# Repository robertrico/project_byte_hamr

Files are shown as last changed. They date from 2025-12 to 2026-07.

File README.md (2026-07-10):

# Byte Hamr

An open-source FPGA expansion card for the Apple II family of computers.

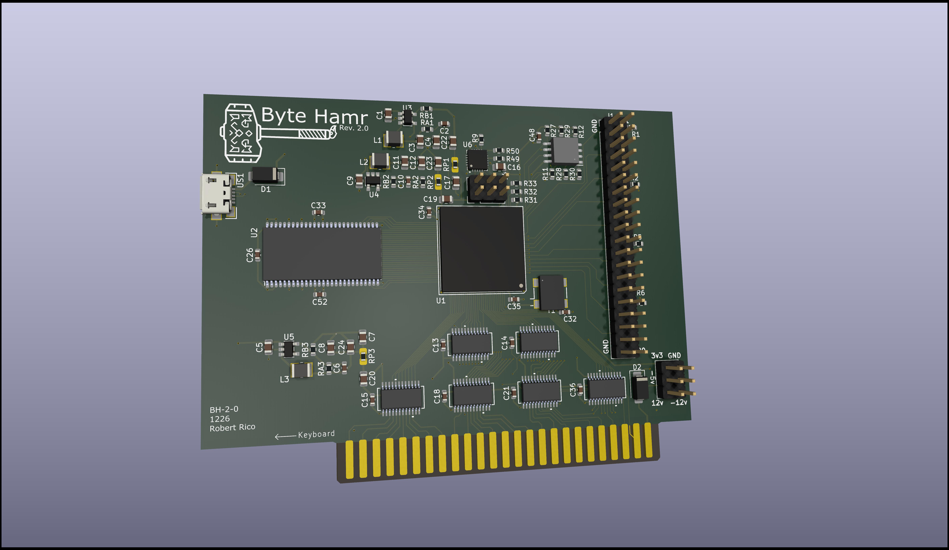
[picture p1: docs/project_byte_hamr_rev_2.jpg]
Byte Hamr


## Overview

Byte Hamr brings modern FPGA capabilities to the Apple II, II+, IIe, and IIgs. Unlike purpose-built cards that serve a single function, Byte Hamr is a general-purpose platform for developing and running custom hardware designs on vintage Apple hardware.

The card sits between the simplicity of the A2FPGA (which targets HDMI output) and the complexity of the Carte Blanche (which is difficult to obtain and uses proprietary tooling). Byte Hamr uses the Lattice ECP5 FPGA with full support for the open-source Yosys/nextpnr toolchain.

## Features

- Lattice ECP5-85F FPGA (84K LUTs, BGA381 package)
- 64MB SDRAM (AS4C32M16SB-7TCNTR)
- 128Mb SPI Flash for bitstream storage
- USB programming via FTDI FT231XQ
- JTAG header for development/debugging
- 20-pin GPIO header with heavy ground interleaving (Rev 2)
- 2×3 power breakout: +3V3, +5V, −5V, +12V, −12V (Rev 2)
- Full Apple II bus interface with bidirectional level shifting
- Dedicated FPGA-controlled data-bus transceiver OE (Rev 2)
- Hardware R/W inverter for correct transceiver direction (Rev 2)
- Bidirectional nRES — drive *and* monitor Apple II reset (Rev 2)
- Dual power input (USB or Apple II bus) with automatic switching
- On-board 100 MHz oscillator (Rev 2; 25 MHz on Rev 1)
- Open-source hardware and gateware

## Specifications

| Parameter | Value |
|---|---|
| FPGA | Lattice ECP5-85F (LFE5U-85F-8BG381I) |
| Logic Elements | 84K LUTs |
| Block RAM | 3744 Kbit |
| SDRAM | 64MB, 16-bit bus |
| Flash | 128Mb SPI |
| USB | Full-speed via FT231XQ |
| GPIO | 20 pins, 3.3V LVCMOS33 |
| Oscillator | 100 MHz (Rev 2) |
| Power | +5V from USB or Apple II slot |
| Dimensions | Standard Apple II card form factor |

## Architecture

```
                                    +------------------+
                                    |     SDRAM        |
                                    |   (64MB x16)     |
                                    +--------+---------+
                                             |
+-------------+     +----------+     +-------+--------+     +----------+
| Apple II    |     | Level    |     |                |     |   SPI    |
| Expansion   +---->+ Shifters +---->+   ECP5-85F     +---->+  Flash   |
| Slot        |     | (5V/3.3V)|     |     FPGA       |     |  (16MB)  |
+-------------+     +----------+     +-------+--------+     +----------+
                                             |
                                     +-------+--------+
                                     |      USB       |
                                     |  (FT231XQ)     |
                                     +----------------+
```

## Power Distribution

Three on-board switching regulators generate the required voltages:

- +3.3V for FPGA I/O, SDRAM, Flash, level shifters
- +2.5V for FPGA auxiliary power
- +1.1V for FPGA core

Power can be sourced from USB (+5V) or the Apple II slot, with Schottky diode OR-ing for automatic switching. Rev 2 moves the 5V input diode ahead of the level-shifter rail so USB alone can power the bus logic.

## Bus Interface

Six 74LVC8T245 bidirectional level shifters translate between the Apple II's 5V bus and the FPGA's 3.3V I/O. The interface provides access to:

- 16-bit address bus
- 8-bit data bus (bidirectional)
- Control signals (R/W, PHI0, device select, etc.)

Rev 2 adds a dedicated 74AHC1G04 inverter (`U7`) that generates the correct-polarity DIR control for the data-bus transceiver, and exposes the transceiver's OE on an FPGA pin so gateware can cleanly gate drive.

## GPIO Header

20-pin header with ground interleaving (pin `1` marked at the top, `20` at the bottom). All pins are 3.3V LVCMOS33.

| GPIO | FPGA Site | | GPIO | FPGA Site |
|---|---|---|---|---|
| GPIO_1  | P3 | | GPIO_11 | J1 |
| GPIO_2  | P1 | | GPIO_12 | H2 |
| GPIO_3  | P2 | | GPIO_13 | H1 |
| GPIO_4  | N1 | | GPIO_14 | G2 |
| GPIO_5  | M1 | | GPIO_15 | G1 |
| GPIO_6  | L2 | | GPIO_16 | F2 |
| GPIO_7  | L1 | | GPIO_17 | F1 |
| GPIO_8  | K3 | | GPIO_18 | E2 |
| GPIO_9  | K1 | | GPIO_19 | E1 |
| GPIO_10 | K2 | | GPIO_20 | D2 |

See [byte_hamr.lpf](gateware/rev2/constraints/byte_hamr.lpf) for full pin constraints.

## Project Status

**Rev 2** — fabricated and bring-up in progress (April 2026). Both boards enumerate over USB and pass initial SDRAM + GPIO tests.

**Rev 1** — sent to fabrication (December 2025). Tagged `rev1` in git; all Rev 1 gateware preserved under `gateware/rev1/`.

See [VERSION.md](VERSION.md) for full version history.

### Rev 2 changes

- Board footprint shrunk
- GPIO expanded from 12 → 20 pins with dense ground interleaving
- Power breakout block exposing ±5V / ±12V / 3V3
- On-board R/W inverter (replaces Rev 1 bodge wire)
- 5V diode moved ahead of level shifters so USB can power the bus side
- Shortened SDRAM routes to the ECP5
- Data-bus transceiver OE promoted from GPIO bodge to dedicated FPGA pin (`DATA_OE`, B20)
- Bidirectional nRES: separate `nRES_READ` input (A5) so gateware can monitor Apple II reset
- Oscillator upgraded 25 MHz → 100 MHz for better CDC oversampling and PLL headroom

## Repository Structure

```
project_byte_hamr/
├── hardware/
│   └── byte_hamr/          # Main FPGA card
│       ├── kicad/          # KiCad schematic and PCB
│       ├── bom/            # Bill of materials
│       └── gerbers/        # Manufacturing files
├── gateware/
│   ├── rev1/               # Rev 1 designs (frozen, matches rev1 git tag)
│   │   ├── constraints/
│   │   ├── signal_check/
│   │   ├── sdram_test/
│   │   ├── sdram_bank/
│   │   ├── pattern_rom/
│   │   ├── logic_hamr/
│   │   ├── smart_hamr/
│   │   ├── block_hamr/
│   │   └── flash_hamr/
│   └── rev2/               # Rev 2 designs (porting in progress)
│       ├── constraints/
│       └── signal_check/
├── software/
│   ├── ASM/                # 6502 assembly source (Merlin32)
│   ├── LOGICHAMR/          # Logic analyzer disk contents
│   └── utils/              # Disk image utilities
└── docs/                   # Documentation
```

## Getting Started

### Prerequisites

**Gateware:**
- [oss-cad-suite](https://github.com/YosysHQ/oss-cad-suite-build) (recommended) or individual tools:
  - [Yosys](https://github.com/YosysHQ/yosys) (synthesis)
  - [nextpnr-ecp5](https://github.com/YosysHQ/nextpnr) (place and route)
  - [openFPGALoader](https://github.com/trabucayre/openFPGALoader) (programming)

**6502 Assembly:**
- [Merlin32](https://brutaldeluxe.fr/products/crossdevtools/merlin/) (cross-assembler)

**Disk Utilities:**
- [AppleCommander](https://applecommander.github.io/) (disk image manipulation)
- [ADTPro](https://adtpro.com/) (disk transfer to real hardware)
- Java runtime

### Building Gateware

Builds are selected by `DESIGN` and `REV`. `REV` defaults to `rev1`; set `REV=rev2` when targeting the current hardware.

```bash
make                                # Build default (REV=rev1, DESIGN=signal_check)
make DESIGN=xxx                     # Build specific design (rev1)
make DESIGN=xxx REV=rev2            # Build against Rev 2 pinout
make sim DESIGN=xxx REV=rev2        # Run simulation
make wave                           # Run simulation and open GTKWave
make help                           # Show all available targets
```

`b8008_hamr` lives under `gateware/rev2/` and always needs `REV=rev2`; it also
needs `fusesoc` installed and a sibling `intel-8008-vhdl` checkout
(`INTEL8008_DIR`, default `~/Development/intel-8008-vhdl`) to generate its
netlist at build time, e.g. `make DESIGN=b8008_hamr REV=rev2 bit`.

### Programming

```bash
make DESIGN=xxx REV=rev2 prog                         # Program via JTAG (volatile)
make DESIGN=xxx REV=rev2 prog-flash                   # Program SPI flash (persistent)
make DESIGN=xxx REV=rev2 prog-flash SERIAL=<FTDI_SN>  # Target a specific board
```

### Software Development Workflow

```
┌─────────────┐     ┌───────────────┐     ┌─────────────┐     ┌───────────┐
│  Merlin32   │────▶│ AppleCommander│────▶│   ADTPro    │────▶│ Apple IIe │
│  (assemble) │     │ (create .dsk) │     │  (transfer) │     │   (run)   │
└─────────────┘     └───────────────┘     └─────────────┘     └───────────┘
```

```bash
# 1. Edit source in software/LOGICHAMR/*.S

# 2. Assemble with Merlin32
make assemble ASM_SRC=software/LOGICHAMR/LOGIC.S

# 3. Create disk image (auto-copied to ADTPro disks folder)
make create-dsk DSK=LOGICHAMR

# 4. Transfer via ADTPro to real hardware

# 5. On Apple II: BRUN LOGIC
```

**Disk utilities:**
```bash
make extract-dsk DSK=file.dsk     # Extract files from disk image
make list-dsk                     # List disks in ADTPro folder
```

### Utility Commands

```bash
make pinout             # Regenerate FPGA pinout from schematics
make lpf                # Regenerate LPF constraints
make clean              # Remove build files
```

## Gateware Designs

Rev 1 versions (proven on Rev 1 hardware):

| Design | Description |
|---|---|
| [signal_check](gateware/rev1/signal_check/SIGNAL_CHECK.md) | Board bring-up test (SDRAM, GPIO, bus monitor) |
| sdram_test | Register-driven SDRAM access from Apple II |
| [sdram_bank](gateware/rev1/sdram_bank/README.md) | SDRAM bank-switching controller |
| [pattern_rom](gateware/rev1/pattern_rom/README.md) | SDRAM-backed pattern ROM for display testing |
| [logic_hamr](gateware/rev1/logic_hamr/README.md) | 8-channel logic analyzer with HIRES display |
| [smart_hamr](gateware/rev1/smart_hamr/README.md) | SmartPort/IWM disk controller with ESP32 companion |
| [block_hamr](gateware/rev1/block_hamr/README.md) | ProDOS block device with SDRAM and SPI flash persistence |
| [flash_hamr](gateware/rev1/flash_hamr/) | SD card ProDOS block device (PicoRV32 + FatFS) |

Rev 2 port: `signal_check` ported and validated; other designs pending.

## Testing

Bringup sequence for new boards:

1. Visual inspection
2. Power rail verification (+5V, +3.3V, +2.5V, +1.1V)
3. USB enumeration (FTDI detection)
4. FPGA configuration with [signal_check](gateware/rev2/signal_check/)
5. Oscillator verification (100 MHz on scope; derived 25 MHz appears on SDRAM_CLK)
6. GPIO walk — watch walking 1s across `GPIO_9`..`GPIO_20`
7. Apple II bus communication (register loopback at $C0C0)
8. Data-bus transceiver + R/W inverter walk: `C0C0:01 → C0C0`, then `02`, `04`, … `80`
9. Full system integration

## Design References

This project builds on the work of others:

- [ULX3S](https://github.com/emard/ulx3s) - ECP5 reference design, power architecture
- [Xander's 8-bit fun](https://xjmaas.wordpress.com/my-apple-collection/apple-edge-connector-template-for-eagle/) - Apple II Edge Card Design
- [Understanding the Apple IIe](https://archive.org/details/understanding_the_apple_iie) - Jim Sather's essential reference

## Why "Byte Hamr"?

"Hamr" is Old Norse for "shape" or "form" — the concept of shapeshifting in Norse mythology. Byte Hamr: shapeshifting bytes. An FPGA that can become any hardware you define. The shape changes based on what you program it to be.

## License

This project is released under the [MIT License](LICENSE.md).

## Author

Robert Rico

## Contributing

This is an early-stage project. Issues, suggestions, and pull requests welcome.

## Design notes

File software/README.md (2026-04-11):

# Software

Apple II and host-side software for the Byte Hamr FPGA expansion card.

## Directories

| Directory | Language | Purpose |
|---|---|---|
| [ASM](ASM/) | 6502 Assembly | Graphics demos, logic analyzer UI prototypes, and FPGA hardware test programs |
| [LOGICHAMR](LOGICHAMR/) | 6502 Assembly | Logic analyzer display program with full FPGA capture engine integration |
| [SMARTPORT](SMARTPORT/) | C + ARM Assembly + PIO | PicoPort: SmartPort disk emulator on Raspberry Pi Pico W with SD card support |
| [utils](utils/) | Bash | Disk image manipulation scripts (extract/create `.dsk` files via AppleCommander) |

## Workflow

1. Write 6502 assembly source (`.S` files)
2. Assemble with **Merlin32** cross-assembler
3. Package into ProDOS `.dsk` images using `utils/create_dsk.sh`
4. Transfer to Apple II via **ADTPro** or embed in FPGA flash

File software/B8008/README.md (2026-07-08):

# B8008 — On-Apple Development Ecosystem for the Intel 8008 Coprocessor

Complete toolchain for writing, assembling, loading, and running Intel
8008 programs **entirely on the Apple //e**, targeting the `b8008_hamr`
coprocessor card (`gateware/rev2/b8008_hamr/`). No Mac in the loop once
the disk is built.

The 8008 core and its instruction encodings come from the upstream
`~/Development/intel-8008-vhdl` repo (consumer relationship — never
modified here). `docs/isa.json` in that repo is the single source of
truth for the ISA: the CPU, the assembler table, and the validation
model are all generated from or checked against it.

## The tools (all ProDOS BIN, `BRUN` from the shipped disk)

| Tool | What it does |
|---|---|
| `A8` | All-in-one 8008 environment: 80-col fullscreen editor + embedded ASM8 core + card loader. The whole edit → assemble → run loop in one program (see below). |
| `ASM8` | Native 8008 assembler. True 8008new syntax (`MOV A,B`, `MVI C,41h`) — no dialect. Reads a ProDOS TXT source, writes a BIN object whose **aux type = ORG**. |
| `B8RUN` | Loader. Reads a BIN object, streams it into 8008 RAM via the monitor's `L` (Intel-hex) command, prints the `G` address. |
| `B8CMP` | Byte-compare two files via MLI; prints `PASS $nnnn BYTES` or the first-diff offset. The acceptance gate tool. |
| `B8TERM` | Glass TTY attached to the 8008 monitor (Ctrl-Q exits, Ctrl-R reboots the 8008). |
| `B8TEST` | Card presence + FIFO self-test. Run first on a fresh flash. |
| `MAC8008.S` | Legacy: 8008 as Merlin macros (`MOV A;B`, `JMP8` renames). Proven, kept as fallback — ASM8 exists to delete this dialect. |

Fixtures: `HELLO8R.ASM` (verbatim upstream ASL source, ASM8's golden
input) and `HELLO8R.REF` (457-byte reference object derived from the
ASL golden hex). `HELLO8.S` is the same program in MAC8008 dialect.

## Build (Mac side)

Requirements: Merlin32 (`~/Development/Merlin32_v1.2`), AppleCommander
jars (paths in the top-level Makefile), python3, and the
`intel-8008-vhdl` repo checked out as a sibling of this project.

```
make asm8tab    # regenerate ASM8TAB.S from isa.json (opcode cross-check)
make asm8       # table + Python model gate + Merlin32 assemble of ASM8.S
make b8cmp      # assemble B8CMP.S
make b8008disk  # everything + bootable B8008.po (tools BIN, sources TXT)
make copy-dsk DSK=software/B8008/B8008.po   # ship to the //e via ADTPro
```

`make asm8` refuses to build if the design gate fails:
`scripts/asm8_check.py` is a Python reference model of the ASM8 spec —
same generated table (imports `build_table()` from
`scripts/gen_asm8_table.py`), same lexer/expression/encoder rules — and
must assemble `HELLO8R.ASM` byte-identical to `HELLO8R.REF` before
Merlin32 runs. The model passed 6/6 upstream sample programs against
their ASL golden hex. Design bugs die on the Mac; only 6502
implementation faithfulness is tested on hardware.

## Workflow on the //e

### A8 (the one-program loop)

`BRUN A8`, then live there:

```
edit -> ^A (assemble in memory; errors jump the cursor to the line)
     -> ^G (stream object into 8008 RAM, drop into the monitor TTY)
     -> inspect (D/H), type G <org>, watch it run
     -> ^Q back to the editor, buffer untouched
```

- Row 0 = key legend, rows 1-22 = 80-col window into the buffer,
  row 23 = status (filename, `*` dirty flag, L=line C=col, `<`/`>`
  horizontal-scroll hints) and all prompts/messages.
- Keys: arrows; `^B`/`^E` top/bottom; `^P`/`^V` page up/down;
  `^S` save, `^L` load, `^N` new; `^D` delete line; `^F` find
  (case-insensitive, wraps, prompt pre-filled with last pattern);
  `^O` goto line; `^A` assemble; `^G` load-to-card + TTY;
  `^Q` quit (confirms if dirty).
- Buffer: 12KB (~400 lines), CR line ends — the buffer IS the TXT
  file format, so load/save are single MLI calls and round-trip
  byte-identical. Lines longer than 79 cols edit via horizontal
  scroll of the current line (upstream ASL sources hit 81 cols).
- `^A` needs a filename (refuses with `NO NAME. ^S FIRST`); a clean
  assemble also writes the BIN object (aux=ORG) to disk, so B8RUN
  and B8CMP interop keeps working. Errors show `LINE n: MSG` on the
  status row and jump the cursor.
- `^G` assembles first if the buffer is dirty or never assembled,
  then streams and lands at the monitor: `LOADED $len AT $org -
  G org WHEN READY`. **No auto-G** — inspect with D/H, type G
  yourself. `^Q` exits the TTY back to the editor.

### Standalone tools (the original loop, still shipped)

1. Write 8008 source in an editor, save as ProDOS TXT (see Merlin
   notes below).
2. `BRUN ASM8` → filename → object written, `OK $nnnn BYTES AT $oooo`.
3. `BRUN B8RUN` → object name → streamed into 8008 RAM.
4. `PR#4` then `G <org>` — run it. (Ctrl-Q exits the terminal;
   objects are run with B8RUN, never `BRUN <8008 bin>`.)

Since the A8 work, ASM8.S is a thin file driver around `ASM8CORE.S`
(the parser/encoder/symbol library both programs embed). The core's
only seams are line source, object sink, and error exit; everything
else moved verbatim. `make asm8` and the Python model gate are
unchanged.

### ASM8 v1 syntax

- All 8008new mnemonics, real names, comma operands. Registers
  `A B C D E H L M`.
- Labels col 0 (trailing `:` optional), `;` comments, case-insensitive.
- Numbers: decimal, ASL `0FFh` (digit-first, trailing h), `$FF`, `'c'`.
- Expressions: flat left-to-right `+ - & | << >>` and parens.
- Directives: `ORG EQU DB DW DS END`; `cpu`/`page` accepted and
  ignored so verbatim upstream ASL sources assemble unmodified.
- Errors print `LINE n: MESSAGE` plus the offending line.
- Limits: symbols 12 chars, lines 127 chars, output 12KB (= full 8008
  RAM), sources any length (streamed in 512-byte chunks).

### Merlin usage notes

Merlin Pro is the **editor only** in this workflow — ASM8 does the
assembling. Save sources as TXT; ASM8 tolerates Merlin's CR line ends
and high-bit characters. Column alignment is free-form (one space
between fields is enough). Notes from the bench:

- Editing 6502 `.S` files here (ASM8.S, B8CMP.S, ASM8TAB.S) in Merlin
  works and is part of QA — they follow the project-wide Merlin style
  guide in `CLAUDE.md` (single-space fields, ASCII, <=40 cols).
- Do NOT load `HELLO8R.ASM` into Merlin: it has 81-col lines (that's
  ASM8 *input*, deliberately wider than Merlin's comfort).
- MAC8008 macro assembly inside Merlin still works as the fallback
  path, dialect warts and all (`MOV A;B`, `JMP8`).

The Merlin-as-editor loop works — it shipped ECHO8 and validated all
of ASM8 — but it is a multi-step round trip (save, quit, BRUN ASM8,
BRUN B8RUN, PR#4, G). That friction is the motivation for the next
project in this line: a single all-in-one fullscreen
editor/assembler/runner for the 8008. ASM8's assembler core was built
to be embeddable for exactly that future.

## Memory map (ASM8 at runtime)

| Range | Use |
|---|-----|
| `$2000-$3FFF` | ASM8 program + buffers (BRUN target) |
| `$4000-$6FFF` | Output buffer (12KB = full 8008 RAM) |
| `$7000-$8BFF` | Symbol table (14 bytes/entry: 12-char name + value) |
| `$8C00` | MLI IOBUF |

## Memory map (A8 at runtime)

| Range | Use |
|---|-----|
| `$2000-$57FF` | A8 code (14KB budget; ~9.2KB used) |
| `$5800-$87FF` | TEXT buffer (12KB, CR lines = TXT format) |
| `$8800-$8FFF` | Symbol table (2KB — 8008 scale is tens of symbols) |
| `$9000-$93FF` | MLI IOBUF |
| `$9400-$94FF` | Aux staging page |
| AUX `$4000-$6FFF` | 8008 object buffer (full 12KB of 8008 RAM) |

BASIC.SYSTEM stays resident (everything <= `$95FF`). Aux access is
via A8's own RAMRD/RAMWR copy loops — AUXMOVE is banned (it uses
ProDOS-adjacent ZP `$3C-$43`). Aux *reads* execute from a 20-byte
stub at `$0130`: the stack page stays main RAM under RAMRD, code at
`$2000` does not. Self-mod operands are only written with RAMWR off,
and MLI/COUT are never called with a bank flipped.

No zero page is touched anywhere (self-modifying absolute pointers) —
ProDOS ZP is a minefield; see `CLAUDE.md` and the SDM lessons.

## Validation status

ASM8 v1 SHIPPED 2026-07-08. All bench gates passed on real hardware
the day it was built: B8CMP plumbing, the golden gate (HELLO8R.ASM
assembled on the //e byte-identical to HELLO8R.REF, then run via
B8RUN + `G 2040`), the error paths, and a from-scratch program
(COUNT8) written in Merlin, assembled with ASM8, and run — the
founding "write 8008 code on the Apple" goal, in true 8008 syntax.

A8 v1 SHIPPED 2026-07-08 — all bench gates passed on real hardware
the same day it was built: the golden gate (`^A` of the verbatim
HELLO8R.ASM inside A8, B8CMP vs HELLO8R.REF = `PASS $01C9 BYTES`),
the `^G` stream + monitor D-dump + TTY + `^Q` round trip, error
cursor-jump (`LINE n:` message and the cursor lands on the line),
and the ship criterion: a from-scratch 8008 program written,
assembled, loaded, and run without ever leaving A8. Four bench
bugs were found and fixed the same day (key-dispatch clobber,
hi-bit TXT line ends, X-clobber digit truncation, save-prompt
editing) — see git log.

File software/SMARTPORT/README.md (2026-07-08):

# PicoPort (SmartPort Disk Emulator)

SmartPort disk emulator running on a Raspberry Pi Pico W. Receives SmartPort commands from the Apple II via the Byte Hamr FPGA, decodes FM-encoded packets, and serves ProDOS block storage from disk images on an SD card.

## What It Does

1. **Receives** SmartPort commands from Apple II via FM-encoded serial protocol
2. **Decodes** packets using oversampled PIO sampling and edge detection
3. **Processes** commands: STATUS, READBLOCK, WRITEBLOCK, FORMAT, CONTROL, INIT
4. **Reads** disk images from SD card (`.2mg` / `.po` format, block-based)
5. **Encodes** responses as SmartPort packets with proper framing and checksums
6. **Transmits** FM-encoded data back to Apple II via PIO output
7. **Manages** handshaking with ACK (open-drain), REQ, and phase signals

## Key Files

| File | Purpose |
|---|---|
| `main.c` | Entry point: GPIO init, PIO state machines, SmartPort bus loop |
| `picoport.h` | Pin definitions mapping Pico W GPIO to FPGA/SmartPort signals |
| `sp_proto.h` | Protocol definitions (commands, packet types, buffer sizes) |
| `sp_cmd.c` | Bus state machine, packet routing, command handlers |
| `sp_asm.S` | Timing-critical ARM assembly (ACK, phase reads, REQ waits) |
| `sp_encode.c` | Packet encoding (bit 7 masking, checksums, group-of-7) |
| `sp_decode_pkt.c` | Packet decoding (extract commands from received packets) |
| `sp_data.c` | Static data (DIB blocks, status responses, sync bytes) |
| `sd_block.c/h` | SD card interface: reads `.2mg` disk images, serves blocks |
| `fm_decode.S` | ARM Thumb-2 assembly: decodes FM samples from PIO into bytes |
| `fm_rx.pio` | PIO state machine for receiving FM-encoded data |
| `fm_tx.pio` | PIO state machine for transmitting FM-encoded data |
| `hw_config.c` | SPI clock and pin setup for SD card |

## SmartPort Wire Protocol

- **FM encoding**: 4us bit cells; transition = 1-bit, steady = 0-bit
- **Sync**: `$FF $3F $CF $F3 $FC $FF $C3` (PBEGIN)
- **Packet**: SYNC + PBEGIN + DEST + SRC + TYPE + AUX + STAT + ODDCNT + GRP7CNT + data + CHKSUM + PEND
- **Group-of-7 encoding**: Preserves bit 7 by packing MSBs into a header byte
- **Bus phases**: 4 pins (PH0-PH3) indicate command/idle/reset state
- **Block size**: 512 bytes

## Pin Mapping

| Pico GPIO | Signal | Direction |
|---|---|---|
| GP11 | SP_WRDATA | Output (to Apple II) |
| GP21 | SP_RDDATA | Input (from Apple II) |
| GP9 | SP_ACK | Output (open-drain) |
| GP2-5 | SP_PHx | Input (phase bits) |

## Build

Requires Raspberry Pi Pico SDK, ARM GCC cross-compiler, and CMake 3.13+.

```bash
make                        # Build with default images/ProDOS_2_4_1.po
make DISK=images/Merlin.po  # Build with different disk image
make flash                  # Flash via OpenOCD/SWD
make monitor                # Serial output at 115200 baud
make test                   # Build test firmware
make clean                  # Remove build directory
```

## Disk Utilities

```bash
python3 dsk2po.py game.dsk game.po         # Convert DOS 3.3 to ProDOS
python3 create_prodos_vol.py out.po 500000  # Create empty ProDOS volume
```

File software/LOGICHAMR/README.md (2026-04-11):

# Logic Hamr (Apple II Software)

Apple II logic analyzer display program for the Logic Hamr FPGA design. Renders captured digital waveforms on the HI-RES screen with trigger control and zoom.

## Programs

| File | Purpose |
|---|---|
| `LOGIC.S` | Main logic analyzer: captures, triggers, and renders 8-channel waveforms |
| `CAPTEST.S` | Capture engine test: validates trigger and capture flow without display |

## How It Works

Communicates with the Logic Hamr FPGA via `$C0C0`-`$C0C9`:

| Register | Purpose |
|---|---|
| `$C0C0` | Channel select (0-7) |
| `$C0C1` | Sample address |
| `$C0C2` | Data read port |
| `$C0C3` | Command register |
| `$C0C4` | Status register |
| `$C0C5` | Stretch/zoom factor |
| `$C0C6`-`$C0C9` | Trigger configuration |

The program arms the FPGA capture engine, waits for a trigger event, then reads back decimated sample data and renders each channel as a waveform trace on the Apple II HI-RES screen. Supports programmable trigger modes (rising/falling edge) and multiple window presets.

## Build

```bash
merlin32 LOGIC.S      # Produces LOGIC executable at $8000
merlin32 CAPTEST.S    # Produces CAPTEST executable at $8000
```

## Shared Includes

- `INCLUDE.S` -- Apple II memory constants and HI-RES utilities
- `LINEADDR.S` -- HI-RES line address lookup tables

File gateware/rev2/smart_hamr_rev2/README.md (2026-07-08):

# smart_hamr_rev2

ASIC-faithful Apple Liron card recreation on Byte Hamr Rev 2.

Stock FujiNet, stock ProDOS, stock Apple II. Card presents as Slot 4 SmartPort
controller; bridges Apple II IWM register space to FujiNet ESP32 over GPIO
header.

## Spec references

- Apple Integrated Woz Machine Specification, Revision 19 (Jan 2 1985)
- US Patent 4,326,256 (Wozniak, IWM bit-cell decoder)
- Apple SmartPort Bus Specification
- Liron schematic 670-9107 / 820-0117

## Build

```
make clean
make DESIGN=smart_hamr_rev2 REV=rev2
```

## Flash (only on user authorization)

```
make DESIGN=smart_hamr_rev2 REV=rev2 prog-flash
```

## Phase status

| Phase | Scope | Status |
|---|---|---|
| 0 | scaffolding (top, ROM, idle iwm) | bench PASS (2026-05-03) |
| 1 | state regs + mode reg + data_out mux + /ENBL timer | bench PASS (2026-05-03) |
| 2 | write path (TX serializer) | bench PASS (2026-05-03) |
| 3 | read path (RX shifter + x7 + buffer) | bench PASS (2026-05-03) |
| 4 | full ProDOS session | bench PASS (2026-05-03) — full 10-device enum + ProDOS boot |
| 5 | second drive + WRITE/FORMAT | not started |

v1 spec-pure (no drain, no Q6-flush, no DRAIN_DELAY) reaches the
PR#4 functional milestone of the prior `smart_hamr`. Empirical
hacks from PR#4 era are NOT required for Liron protocol fidelity.

`data_chksum=1` errors observed during early bring-up traced to
FujiNet ESP32 debug-print flooding stalling its ISR — not a
gateware fault. Reduce ESP32 print rate when troubleshooting
similar errors.

See `docs/bringup_log.md` for bench results.

## Files

| File | Purpose |
|---|---|
| `smart_hamr_rev2_top.v` | Slot interface, GPIO map, tri-state, POR, reset |
| `iwm_asic.v` | IWM ASIC emulation (single FCLK domain) |
| `addr_decoder.v` | nI_O_SELECT / nI_O_STROBE expansion ROM mgmt (verbatim) |
| `boot_rom.v` | 4 KB ROM container, combinatorial read (verbatim) |
| `liron_rom.mem` | Liron firmware data (verbatim) |
| `smart_hamr_rev2.lpf` | FPGA pin constraints (Rev 2) |

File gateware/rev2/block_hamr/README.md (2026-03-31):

# Block Hamr

ProDOS block storage device for the Apple II, implemented on the Byte Hamr FPGA card. Stores a disk image in SDRAM backed by SPI flash persistence, allowing the Apple II to boot and run from a virtual hard drive.

## What It Does

Block Hamr acts as a ProDOS-compatible block device (similar to a SmartPort drive):

1. **Boot** - On power-up, copies a disk image from SPI flash (at offset `0x400000`) into SDRAM
2. **Auto-detect** - Reads the ProDOS volume header to determine total block count
3. **Block I/O** - The 6502 reads and writes 512-byte blocks through a register interface at `$C0C0-$C0CF`
4. **Write-through persistence** - Modified blocks are asynchronously flushed back to SPI flash

Max disk image size: 12 MB (24,576 blocks of 512 bytes), limited by flash space after the bitstream.

## Register Map

Base address: `$C0C0` (slot 4)

| Offset | Name | R/W | Description |
|---|---|-----|---|
| `$00` | STATUS / CMD | R/W | Read: `{ready, error, 5'b0, boot_done}` / Write: `$01` = READ, `$02` = WRITE |
| `$01` | DATA_READ | R | Read block data (auto-increment) |
| `$02` | BLOCK_LO | R/W | Block number low byte |
| `$03` | BLOCK_HI | R/W | Block number high byte |
| `$04` | SOFT_RESET | W | Pulse to reset state machine |
| `$05` | DATA_WRITE | W | Write block data (auto-increment) |
| `$06` | BLKCNT_LO | R | Total block count low (from boot loader) |
| `$07` | BLKCNT_HI | R | Total block count high |

## Architecture

```
Apple II Bus (7 MHz)           FPGA System (25 MHz)

  boot_rom.v                   boot_loader.v
  (Slot $Cn ROM)               Flash -> SDRAM copy
       |                       Auto-detect blocks
  bus_interface.v                    |
  (Register file)              sdram_arbiter.v
       |                       (Mux boot + block requests)
  block_buffer.v                     |
  (512B dual-port BRAM)        sdram_controller.v
       |                       (64MB SDRAM interface)
       +------ CDC sync ------+
                               flash_persist.v
                               (Write-through to flash)
```

**Clock domains**: 7.16 MHz (Apple II bus) and 25 MHz (SDRAM/flash), with 2-FF synchronizers at boundaries.

**Key design decisions**:
- Driver fits entirely in `$Cn` (256 bytes) - no shared `$C800` ROM needed
- Separate DATA_READ/DATA_WRITE addresses to avoid 6502 STA dummy-read bug
- Prefetch pipeline hides BRAM read latency

## Boot Sequence

1. SDRAM initializes (~200us)
2. Boot loader reads disk image from flash at `0x400000`
3. ProDOS volume header parsed for block count (bytes 1065-1066)
4. Image copied to SDRAM address 0
5. `boot_done` asserted, SPI mux switches from reader to writer
6. Apple II boots from block 0

## Makefile Commands

All commands run from the project root (`project_byte_hamr/`).

```bash
# Build
make DESIGN=block_hamr         # Build complete bitstream
make DESIGN=block_hamr synth   # Synthesis only
make DESIGN=block_hamr pnr     # Place & route only
make DESIGN=block_hamr bit     # Generate bitstream

# Program
make DESIGN=block_hamr prog              # JTAG (volatile)
make DESIGN=block_hamr prog-flash        # SPI flash (persistent)
make DESIGN=block_hamr prog-flash-with-image  # Bitstream + disk image

# Disk image management
make DESIGN=block_hamr prog-flash-with-image DISK_IMAGE=path/to/image.po

# Swap disk images without re-flashing the bitstream
make read-flash                          # Dump current image to disk_dump.po
make read-flash DUMP_FILE=backup.po      # Dump to a specific file
make read-flash DUMP_SIZE=4194304        # Read only 4MB (default: 12MB)
make write-flash DISK_IMAGE=new_disk.po  # Write new image to flash at 0x400000
make write-flash DISK_IMAGE=new_disk.po FLASH_IMG_OFFSET=0x400000

# Simulate
make DESIGN=block_hamr sim         # Run testbench
make DESIGN=block_hamr wave        # Simulation + GTKWave
make DESIGN=block_hamr unit MODULE=bus_interface

# Reports
make DESIGN=block_hamr report      # View build summary
make clean                         # Remove build artifacts
```

## Files

| File | Description |
|---|---|
| `block_hamr_top.v` | Top-level - SPI mux, reset, clock domains |
| `boot_rom.v` | 4KB slot ROM (256B boot + shared expansion) |
| `bus_interface.v` | Register file, command/status, prefetch pipeline |
| `block_buffer.v` | 512-byte dual-port BRAM (7 MHz / 25 MHz) |
| `boot_loader.v` | Flash-to-SDRAM copy with ProDOS auto-detect |
| `sdram_controller.v` | SDRAM init, refresh, read/write |
| `sdram_arbiter.v` | Mux boot loader and block I/O requests |
| `flash_reader.v` | SPI flash reader (boot phase) |
| `flash_writer.v` | SPI flash programmer (runtime phase) |
| `flash_persist.v` | Sector erase/program controller |
| `write_through.v` | Gates block_ready during flash writes |
| `addr_decoder.v` | Apple II address space decoder |
| `hamr_rom.asm` | 6502 ProDOS driver source (Merlin32) |
| `hamr_rom.mem` | Generated ROM content (hex) |
| `block_hamr.lpf` | Pin constraints (design-specific) |

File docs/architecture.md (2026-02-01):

# Byte Hamr Architecture

## System Overview

```
┌─────────────────────────────────────────────────────────────────────────────┐
│                              APPLE II SLOT                                  │
│  ┌─────────────────────────────────────────────────────────────────────┐    │
│  │  Address Bus (A0-A15)  Data Bus (D0-D7)  Control (PHI0/1, R/W, etc) │    │
│  └──────────────────────────────┬──────────────────────────────────────┘    │
└─────────────────────────────────┼───────────────────────────────────────────┘
                                  │
                                  │ 5V ↔ 3.3V
                    ┌─────────────┴─────────────┐
                    │       LEVEL SHIFTERS      │
                    │        (SN74LVC245)       │
                    └─────────────┬─────────────┘
                                  │ 3.3V
┌─────────────────────────────────┼────────────────────────────────────────────┐
│                          BYTE HAMR PCB                                       │
│  ┌──────────────────────────────┴───────────────────────────────────────┐    │
│  │                                                                      │    │
│  │                      ┌─────────────────────┐                         │    │
│  │   Apple II Bus ──────│                     │────── SDRAM (64MB)      │    │
│  │   A0-A15, D0-D7      │                     │       AS4C32M16SB       │    │
│  │   PHI0, PHI1         │    LATTICE ECP5     │                         │    │
│  │   R/W, RDY           │    LFE5U-85F-8      │────── SPI Flash         │    │
│  │   IRQ, NMI, RES      │                     │       (Bitstream)       │    │
│  │   DMA, INH           │    381-ball BGA     │                         │    │
│  │   I/O SELECT         │    85K LUTs         │────── GPIO Header (J1)  │    │
│  │   I/O STROBE         │                     │       12 pins direct    │    │
│  │   DEVICE SELECT      │                     │                         │    │
│  │   7M, Q3, SYNC       └─────────────────────┘────── JTAG (FT2232H)    │    │
│  │                              │                                       │    │
│  │                         CLK_25MHz                                    │    │
│  │                        (Oscillator)                                  │    │
│  └──────────────────────────────────────────────────────────────────────┘    │
└──────────────────────────────────────────────────────────────────────────────┘
```

## Signal Categories

### Apple II Bus Interface (active low signals marked with n)

| Category | Signals | Direction | Description |
|---|---|---|---|
| Address | A0-A15 | Input | 16-bit address from 6502 |
| Data | D0-D7 | Bidirectional | 8-bit data bus |
| Timing | PHI0, PHI1 | Input | System clocks (~1MHz) |
| Timing | 7M, Q3 | Input | High-speed timing (7.16MHz, 1.79MHz) |
| Timing | SYNC | Input | Opcode fetch indicator |
| Control | R/nW | Input | Read/Write direction |
| Control | RDY | Input | Ready (active high) |
| Interrupt | nIRQ, nNMI | Output (active low) | Interrupt requests |
| Reset | nRES | Input | System reset |
| DMA | nDMA, DMA_IN, DMA_OUT | Mixed | DMA control |
| Select | nDEVICE_SELECT | Input | Slot device select ($C0n0-$C0nF) |
| Select | nI/O_SELECT | Input | Slot I/O select ($Cn00-$CnFF) |
| Select | nI/O_STROBE | Input | Expansion ROM ($C800-$CFFF) |
| Control | nINH | Output | Inhibit main ROM |
| Misc | INT_IN, INT_OUT | Mixed | Interrupt daisy chain |

### SDRAM Interface

| Signal | Width | Description |
|---|---|---|
| SDRAM_CLK | 1 | Clock (directly from FPGA, 25MHz) |
| SDRAM_CKE | 1 | Clock enable |
| SDRAM_nCS | 1 | Chip select |
| SDRAM_nRAS | 1 | Row address strobe |
| SDRAM_nCAS | 1 | Column address strobe |
| SDRAM_nWE | 1 | Write enable |
| SDRAM_BA | 2 | Bank address |
| SDRAM_A | 13 | Address (row/column multiplexed) |
| SDRAM_D | 16 | Data (bidirectional) |
| SDRAM_DQM | 2 | Data mask (byte lanes) |

**SDRAM: AS4C32M16SB-7TCNTR**
- 512Mbit (32M x 16bit = 64MB)
- 143MHz max, running at 25MHz (plenty of margin)
- CAS Latency 2 at this speed

### GPIO Header (J1)

12 pins directly connected to FPGA (no level shifters):
- GPIO1-GPIO12: General purpose I/O
- 3.3V logic levels
- Direct FPGA connection for maximum flexibility

## Clock Domains

```
                    ┌──────────────┐
   25MHz OSC ───────│  CLK_25MHz   │──────┬────── FPGA Logic
                    └──────────────┘      │
                                          └────── SDRAM_CLK

   ~1MHz (Apple) ───│    PHI0      │──────────── Sampled by FPGA
                    │    PHI1      │             (oversampled at 25MHz)

   7.16MHz ─────────│    7M        │──────────── Available for timing
   1.79MHz ─────────│    Q3        │
```

**Key Insight**: PHI0/PHI1 are NOT used as FPGA clocks. They are sampled as inputs using the 25MHz system clock. This avoids clock domain crossing issues and provides 25 samples per Apple II bus cycle.

## Memory Map (Apple II Perspective)

| Address Range | Signal Asserted | Typical Use |
|---|---|---|
| $C0n0-$C0nF | nDEVICE_SELECT | Slot n I/O registers (soft switches) |
| $Cn00-$CnFF | nI/O_SELECT | Slot n ROM space (directly addressable) |
| $C800-$CFFF | nI/O_STROBE | Expansion ROM (shared, banked by slot access) |

Where n = slot number (1-7, typically 4-7 for peripheral cards)

## Build Flow

```
┌─────────────┐     ┌─────────────┐     ┌─────────────┐     ┌─────────────┐
│   Verilog   │────▶│   Yosys     │────▶│  nextpnr    │────▶│  ecppack    │
│   Sources   │     │  (synth)    │     │   (PnR)     │     │ (bitstream) │
└─────────────┘     └──────┬──────┘     └──────┬──────┘     └──────┬──────┘
                           │                   │                   │
                           ▼                   ▼                   ▼
                      .json             .config               .bit/.svf
                                           │
┌─────────────┐                            │
│    LPF      │────────────────────────────┘
│ Constraints │    (pin locations, I/O settings)
└─────────────┘
```

## File Structure

```
project_byte_hamr/
├── gateware/                    # FPGA designs
│   ├── signal_check/            # Board bring-up test
│   │   ├── signal_check_top.v   # Top module
│   │   └── signal_check_tb.v    # Testbench
│   └── <future_projects>/
├── hardware/
│   └── byte_hamr/
│       ├── kicad/               # Schematic & PCB
│       └── constraints/
│           └── byte_hamr.lpf    # Pin constraints (generated)
├── scripts/
│   ├── extract_fpga_pinout.py   # Parse KiCad netlist
│   ├── augment_fpga_pinout.py   # Add ECP5 pin info
│   └── generate_lpf.py          # Generate LPF from JSON
├── docs/
│   ├── fpga_pinout.json         # Master pinout (generated)
│   └── architecture.md          # This file
├── build/                       # Build outputs (gitignored)
└── Makefile                     # Build system
```

## Design Conventions

### Signal Naming
- Active-low signals: prefix with `n` (e.g., `nRES`, `nIRQ`)
- Apple II signals: match slot documentation where possible
- SDRAM signals: prefix with `SDRAM_`
- GPIO header: `GPIO1` through `GPIO12`
- Signals starting with numbers: prefix with `sig_` (e.g., `sig_7M`)

### I/O Standards
- All I/O: LVCMOS33 (3.3V)
- SDRAM: FAST slewrate for signal integrity
- Apple II bus: SLOW slewrate (through level shifters)
- Default drive: 8mA

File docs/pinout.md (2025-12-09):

# Apple IIe Peripheral Slot Pinout

This document describes the 50-pin peripheral slot connector used in the Apple IIe. Each expansion slot provides address decoding, data bus access, power, and control signals for peripheral cards.

---

## Pin Reference

| Pin | Signal | Direction | Description |
|-----|---|---|---|
| 1 | I/O SELECT´ | To FPGA | Active low when the MMU references page `$Cn`, where *n* is the slot number. Active during Ø0. |
| 2–17 | A0–A15 | To FPGA | Three-state buffered address bus. Valid during Ø1 through Ø0. |
| 18 | R/W´ | To FPGA | Three-state buffered Read/Write signal. Valid with address bus; high = read, low = write. |
| 19 | SYNC | To FPGA | **Slot 7 only.** Connected to the video timing generator's composite sync signal. |
| 20 | I/O STROBE´ | To FPGA | Active low during Ø0 when address is `$C800`–`$CFFF`. |
| 21 | RDY | To Apple IIe | 6502 RDY input. Pulling low during Ø1 halts the processor with the current address held on the bus. |
| 22 | DMA´ | To Apple IIe | Pulling low disables the 6502 address bus and halts the processor. Held high by 3kΩ resistor to +5V. |
| 23 | INT OUT | To FPGA | Daisy-chain input from higher-priority slot. Active = no higher slot is using interrupts. |
| 24 | DMA OUT | To FPGA | Daisy-chain input from higher-priority slot. Active = no higher slot is using DMA. |
| 25 | +5V | — | +5 volt power supply. 500mA available across *all* peripheral cards. |
| 26 | GND | — | System ground. |
| 27 | DMA IN | To Apple IIe | Daisy-chain output to lower-priority slot. Directly connect to DMA OUT (pin 24), or disable when asserting DMA´. |
| 28 | INT IN | To Apple IIe | Daisy-chain output to lower-priority slot. Directly connect to INT OUT (pin 23), or disable when asserting IRQ´/NMI´. |
| 29 | NMI´ | To Apple IIe | Non-Maskable Interrupt. Pulling low initiates an interrupt cycle; jumps to vector at `$03FB`. This line has a 3.3kΩ pullup to +5v.|
| 30 | IRQ´ | To Apple IIe | Interrupt Request. Pulling low initiates an interrupt cycle if the 6502's I flag is clear. Vector at `$03FE`–`$03FF`. This line has a 3.3kΩ pullup to +5v. |
| 31 | RES´ | To Apple IIe | Reset. Pulling low initiates a processor reset cycle. |
| 32 | INH´ | To Apple IIe | Inhibit. Pulling low disables all onboard ROMs. This line has a 2kΩ pullup to +5v.|
| 33 | −12V | — | −12 volt power supply. 200mA maximum across all peripheral cards. |
| 34 | −5V | — | −5 volt power supply. 200mA maximum across all peripheral cards. |
| 35 | COLOR REF / 3.58M | To FPGA | **Slot 7 only.** 3.58 MHz color reference signal from the video generator. |
| 36 | 7M | To FPGA | 7 MHz clock. |
| 37 | Q3 | To FPGA | 2 MHz asymmetrical clock. |
| 38 | Ø1 | To FPGA | Microprocessor phase-one clock. |
| 39 | µPSYNC | To FPGA | The 6502 drives this line high during the first read cycle of each instruction (opcode fetch). |
| 40 | Ø0 | To FPGA | Microprocessor phase-zero clock. |
| 41 | DEVICE SELECT´ | To FPGA | Active low when address is `$C0n0`–`$C0nX`, where *n* = slot number + 8 and X is between 1 & F. |
| 42–49 | D0–D7 | Both | Three state buffered bidirectional data bus. Write data valid 300ns into Ø0; read data must be stable 100ns before end of Ø0. |
| 50 | +12V | — | +12 volt power supply. 250mA maximum across all peripheral cards. |

---

## Regarding DMA´ and INT, IRQ´, NMI´

The DMA and interrupt signals use a hardware daisy-chain for priority arbitration. Priority is determined by slot position — higher slot numbers have higher priority:

```
Slot 7 (highest) → 6 → 5 → 4 → 3 → 2 → 1 (lowest)
```

**To use interrupts (IRQ´ or NMI´):**
1. Check INT OUT (pin 23) — if active, no higher-priority slot is interrupting
2. Assert IRQ´ or NMI´ to request the interrupt
3. Disable INT IN (pin 28) — this blocks lower-priority slots until you release

**To use DMA:**
1. Check DMA OUT (pin 24) — if active, no higher-priority slot is using DMA
2. Assert DMA´ (pin 22) to take control of the bus
3. Disable DMA IN (pin 27) — this blocks lower-priority slots until you release

For the daisy-chain to function, all slots between yours and slot 7 must either have cards that pass INT OUT → INT IN and DMA OUT → DMA IN, or be empty (with the signals connected on the backplane). [1]

---

## Regarding µPSYNC

The µPSYNC signal enables peripheral cards to detect specific 6502 instructions in hardware. When µPSYNC is high, the data bus contains an opcode being fetched. By sampling the data bus when Ø0 falls, a card can identify which instruction is executing.

For example, detecting an RTI instruction: watch for µPSYNC high with `$40` on the data bus at the falling edge of Ø0. This allows peripheral cards to respond directly to program instructions without software intervention. [2]

---

## Notes

- Active-low signals are indicated with a prime suffix (´), matching Apple's convention. In KiCad, use `~{SIGNAL}` for the equivalent overline notation.
- Slot 7 has unique signals (SYNC, COLOR REF) for video applications.
- The daisy-chain connections (INT IN/OUT, DMA IN/OUT) enable priority-based arbitration across slots.

---

## References

- [1] _Reference Manual for the Apple IIe_ by Apple
- [2] _Understanding the Apple IIe_ by Jim Sather

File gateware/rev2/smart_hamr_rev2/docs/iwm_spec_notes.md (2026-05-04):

# iwm_asic.v — spec → RTL signal mapping

Cross-reference for every IWM signal in `iwm_asic.v`. Citation form
`spec pN` = IWM Specification Rev 19 (Jan 2 1985); `patent col N` = US
Patent 4,326,256 (Wozniak).

## Bus interface

| RTL signal | Source | Spec ref | Notes |
|---|---|---|---|
| `addr[3:0]` | A0..A3 of slot bus | spec p7 | A3..A1 selects state bit, A0 is value |
| `nDEVICE_SELECT` | slot decode | spec p7 | active-low, drives state-reg latches |
| `fclk` | sig_7M | spec p2 | 7.16 MHz Apple II 7M |
| `Q3` | Apple II Q3 | spec p7 | 2 MHz strobe, OR'd with /DEV for bus access |
| `R_nW` | 6502 R/W | spec p7 | gates buffer / mode writes |
| `nRES` | combined POR + Apple reset | — | async clear |
| `data_in/data_out` | D0..D7 mux | spec p9 | tri-stated externally by top |

## State registers (/DEV-clocked)

Per spec p7 + patent Fig. 2 block 39. addr[3:1] decode:

| addr[3:1] | Register | addr[0]=0 | addr[0]=1 |
|---|---|---|---|
| 000 | `phase_r[0]` | clear | set |
| 001 | `phase_r[1]` | clear | set |
| 010 | `phase_r[2]` | clear | set |
| 011 | `phase_r[3]` | clear | set |
| 100 | `motorOn` | clear | set |
| 101 | `driveSel` | clear | set |
| 110 | `q6` | clear | set |
| 111 | `q7` | clear | set |

Latched on `negedge nDEVICE_SELECT`. Async clear on `~nRES`. No FCLK
synchronizer downstream — real ASIC has none, state changes are bus-
cycle-aligned and slower than any FCLK consumer's reaction window.

`rnw_dev` and `a0_dev` also latched on /DEV falling, used by mode/buffer
write event.

## Bus access strobe

Per spec p7. `dev_or_q3 = nDEVICE_SELECT | Q3`. `bus_strobe_rise` =
posedge of `dev_or_q3` in fclk domain. Used to commit data_held into
`modeReg` when q7=1, q6=1, a0_dev=1, rnw_dev=0, motorOn=0.

`data_held` continuously samples `data_in` while `~nDEVICE_SELECT`,
so the latched value is the last byte the 6502 drove during PHI0 high.

## Mode register (spec p8)

| Bit | Name | Function |
|-----|---|---|
| 0 | modeLatch | 1 = latch (SmartPort) framing |
| 1 | modeAsync | 1 = async handshake |
| 2 | modeTimerOff | 1 = disable 1-second motor timer |
| 3 | modeFast | 1 = 2 µs bit cells |
| 4 | mode8MHz | 1 = 8 MHz fclk (unused on Apple II) |
| 5 | modeTest | 1 = test mode |
| 6 | modeMZreset | 1 = MZ reset |
| 7 | (unused) | — |

Reset value: `8'h07` (latch=1, async=1, timer-off=1) — Liron ROM init
expects this.

## Bit-cell timing constants (spec p4 / p10)

Not yet instantiated (Phase 2/3). Reference values for FCLK cycle counts:

| Mode | oneThreshold | zeroThreshold | writeBitCell |
|---|---|---|---|
| slow / 7 MHz | 14 | 42 | 28 |
| slow / 8 MHz | 16 | 48 | 32 |
| fast / 7 MHz | 7 | 21 | 14 |
| fast / 8 MHz | 8 | 24 | 16 |

## /ENBL gating (spec p7 / p12)

`_enbl1 = ~((motorOn & ~driveSel) | (timerActive & ~timerDriveSel))`
`_enbl2 = ~((motorOn &  driveSel) | (timerActive &  timerDriveSel))`

`timerActive` set on `motorOn` falling when `~modeTimerOff`. Holds
2^23 + 100 FCLK = 8388708 cycles (~1.17 s @ 7.16 MHz).

`timerDriveSel` snapshots `driveSel` at timer start so the correct
/ENBL is held even if `driveSel` toggles during the wind-down.

## Read register mux (spec p7 / p9)

| q7 | q6 | motorOn | data_out |
|----|----|---|---|
| 0 | 0 | 0 | `8'hFF` |
| 0 | 0 | 1 | `{x7, buffer[6:0]}` |
| 0 | 1 | x | `{sense, 1'b0, enableActive, modeReg[4:0]}` (status) |
| 1 | 0 | x | `{writeBufferEmpty, _underrun, 6'b0}` (handshake) |
| 1 | 1 | x | `8'hFF` (write-only registers) |

`enableActive = ~_enbl1 | ~_enbl2`. Per spec p9 bit 5.

## Phase 1 stubs

Not yet implemented; held at idle:

- `x7 = 0`, `buffer = 0`
- `writeBufferEmpty = 1`, `_underrun = 1`
- `wrdata = 1` (idle HIGH)
- `_wrreq = 1` (inactive)
- `rddata` consumed by `_unused_rd` ribbon

Phase 2 brings `wrdata`, `writeShifter`, `_underrun`, `_wrreq` under
the serializer. Phase 3 brings `rddata` sampling, `bitTimer`,
`shifter`, `buffer`, `x7`.

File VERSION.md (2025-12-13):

# Version History

## Current Version

**Rev 1** - December 2025

## Changelog

### Rev 1 (December 2025)

Initial release sent to fabrication.

- Lattice ECP5-85F FPGA (LFE5U-85F-8BG381I)
- 64MB SDRAM (AS4C32M16SB-7TCNTR)
- 16MB SPI Flash for bitstream storage
- USB programming via FTDI FT231XQ
- JTAG header for development/debugging
- 13-pin GPIO header
- Full Apple II bus interface with bidirectional level shifting
- Dual power input (USB or Apple II bus)
- On-board 25MHz oscillator

## Planned Revisions

Future revisions will be documented here as the project evolves based on
Rev 1 hardware validation results.

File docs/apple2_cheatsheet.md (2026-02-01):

# Apple II Address Cheat Sheet

Quick reference for slot peripheral development.

## Slot Address Calculation

| Region | Address Formula | Range (Slot 4) | Purpose |
|---|---|---|---|
| Device Select | $C080 + (slot × 16) | $C0C0-$C0CF | 16 I/O registers |
| I/O Select | $C000 + (slot × 256) | $C400-$C4FF | 256 bytes slot ROM |
| I/O Strobe | $C800-$CFFF | $C800-$CFFF | 2K shared expansion ROM |

### Decimal Equivalents (for BASIC)

| Slot | Device Select Base | I/O Select Base |
|---|---|---|
| 1 | 49296 ($C090) | 49408 ($C100) |
| 2 | 49312 ($C0A0) | 49664 ($C200) |
| 3 | 49328 ($C0B0) | 49920 ($C300) |
| 4 | 49344 ($C0C0) | 50176 ($C400) |
| 5 | 49360 ($C0D0) | 50432 ($C500) |
| 6 | 49376 ($C0E0) | 50688 ($C600) |
| 7 | 49392 ($C0F0) | 50944 ($C700) |

**Formula:** `BASE = 49280 + SLOT * 16` (Device Select)

## Common Soft Switches

| Address | Read | Write | Description |
|---|---|---|---|
| $C000 | Keyboard | 80STOREOFF | Last key pressed (bit 7 = strobe) |
| $C010 | Any | Any | Clear keyboard strobe |
| $C030 | Toggle | Toggle | Speaker click |
| $C050 | TXTCLR | TXTCLR | Graphics mode |
| $C051 | TXTSET | TXTSET | Text mode |
| $C052 | MIXCLR | MIXCLR | Full screen |
| $C053 | MIXSET | MIXSET | Mixed (4 lines text) |
| $C054 | PAGE1 | PAGE1 | Display page 1 |
| $C055 | PAGE2 | PAGE2 | Display page 2 |
| $C056 | LORES | LORES | Lo-res graphics |
| $C057 | HIRES | HIRES | Hi-res graphics |

## HIRES Screen Memory

| Page | Address Range | Size |
|---|---|---|
| Page 1 | $2000-$3FFF | 8K |
| Page 2 | $4000-$5FFF | 8K |

**Line address calculation:** Non-linear! Use lookup table.

```
Line 0:   $2000, $2400, $2800, $2C00, $3000, $3400, $3800, $3C00
Line 8:   $2080, $2480, $2880, $2C80, $3080, $3480, $3880, $3C80
Line 64:  $2028, $2428, $2828, $2C28, $3028, $3428, $3828, $3C28
...
```

Each line = 40 bytes. Bits 0-6 = pixels, bit 7 = palette.

## BASIC Examples

### Read from Card
```basic
10 SLOT = 4
20 BASE = 49280 + SLOT * 16
30 STATUS = PEEK(BASE + 4)
40 PRINT "STATUS: "; STATUS
```

### Write to Card
```basic
10 SLOT = 4
20 BASE = 49280 + SLOT * 16
30 POKE BASE + 0, 0: REM Select channel 0
40 POKE BASE + 3, 2: REM Send read command
50 DATA = PEEK(BASE + 2): REM Read result
```

### Enter HIRES Mode
```basic
10 HGR: REM Page 1, mixed mode
20 HGR2: REM Page 2, full screen
30 POKE 49234,0: REM Full screen (MIXCLR)
```

## Assembly Examples

### Slot-Independent Register Access
```asm
* X = slot number * 16 (e.g., $40 for slot 4)
        LDA $C080,X     ; Read register 0
        STA $C081,X     ; Write register 1
```

### Calculate Slot Offset
```asm
* Convert slot number (1-7) to offset
        LDA SLOT        ; Slot number
        ASL             ; ×2
        ASL             ; ×4
        ASL             ; ×8
        ASL             ; ×16
        TAX             ; X = slot × 16
```

### Wait for Ready Bit
```asm
WAIT    LDA $C084,X     ; Read status register
        AND #$02        ; Check ready bit
        BEQ WAIT        ; Loop until ready
```

## Hex/Decimal Conversion

| Hex | Decimal | Hex | Decimal |
|-----|---|-----|---|
| $00 | 0 | $80 | 128 |
| $10 | 16 | $90 | 144 |
| $20 | 32 | $A0 | 160 |
| $30 | 48 | $B0 | 176 |
| $40 | 64 | $C0 | 192 |
| $50 | 80 | $D0 | 208 |
| $60 | 96 | $E0 | 224 |
| $70 | 112 | $F0 | 240 |
| $FF | 255 | | |

## Byte Hamr Register Maps

### logic_hamr_v1 (Slot 4: $C0C0-$C0CF)

| Offset | Address | R/W | Name | Description |
|---|---|-----|---|---|
| $00 | $C0C0 | R/W | CHANNEL | Channel select (0-7) |
| $01 | $C0C1 | R/W | ADDR | Byte index (0-37) |
| $02 | $C0C2 | R | DATA | Read result from SDRAM |
| $03 | $C0C3 | W | CMD | $02=Read, $10=Regenerate |
| $04 | $C0C4 | R | STATUS | [0]=busy [1]=ready |
| $05 | $C0C5 | R/W | STRETCH | Pixels per sample (1-15) |

### signal_check (Slot 4: $C0C0-$C0CF)

| Offset | Address | R/W | Name | Description |
|---|---|-----|---|---|
| $00-$0F | $C0C0-$C0CF | R/W | REG[n] | General-purpose registers |

Reads return last written value. GPIO directly reflects card status.

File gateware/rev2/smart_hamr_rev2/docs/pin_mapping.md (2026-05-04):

# Pin mapping — smart_hamr_rev2

LPF: `smart_hamr_rev2.lpf`. Identical layout to `smart_hamr/smart_hamr.lpf`
(daughter-board mapping shared).

## Apple II slot

| Signal | FPGA pin | Direction | Notes |
|---|---|---|---|
| sig_7M | A9 | in | 7.16 MHz |
| Q3 | B10 | in | 2 MHz IWM strobe |
| PHI0 / PHI1 | A11 / A10 | in | unused |
| R_nW | D10 | in | |
| nDEVICE_SELECT | D16 | in | $C0Cx assertion |
| nI_O_SELECT | A19 | in | $C400-$C4FF |
| nI_O_STROBE | C11 | in | $C800-$CFFF |
| nRES | A8 | out (open-drain) | always released |
| nRES_READ | A5 | in | Apple II reset monitor |
| A0..A15 | (see LPF) | in | individually constrained |
| D0..D7 | (see LPF) | inout | tri-state by `data_oe` |
| DATA_OE | B20 | out | level-shifter U12 OE (active-low) |

## GPIO header (FujiNet bridge)

Daughter-board ribbon mapping. ESP32 column on right of perfboard.

| GPIO | FPGA | Direction | Signal | ESP32 GPIO |
|---|---|---|---|---|
| GPIO_1 | P3 | out | nDEVICE_SELECT (LA debug) | — |
| GPIO_2 | P1 | out | tied 0 | — |
| GPIO_3 | P2 | out | nRES_READ (LA debug) | — |
| GPIO_4..GPIO_8 | N1, M1, L2, L1, K3 | out | tied 0 (reserved LA debug) | — |
| GPIO_9 | K1 | out | _enbl2 | IO3/RX |
| GPIO_10 | K2 | out | wrdata (FAST slew) | IO22 |
| GPIO_11 | J1 | out | tied 0 | — |
| GPIO_12 | H2 | in | rddata (idle-LOW, inverted internally) | IO14 |
| GPIO_13 | H1 | in | sense (PULLMODE=UP) | IO27 |
| GPIO_14 | G2 | out | _wrreq | IO26 |
| GPIO_15 | G1 | out | phase[1] | IO33 |
| GPIO_16 | F2 | out | phase[0] (damped pad) | IO32 |
| GPIO_17 | F1 | out | phase[3] | IO35 |
| GPIO_18 | E2 | out | phase[2] | IO34 |
| GPIO_19 | E1 | out | tied 0 | — |
| GPIO_20 | D2 | out | _enbl1 | IO36 |

## Pad properties

- `wrdata` (GPIO_10): SLEWRATE=FAST so bit-cell edges stay clean.
- `rddata` (GPIO_12): PULLMODE=DOWN (matches ESP32 idle-LOW).
- `sense` (GPIO_13): PULLMODE=UP (defined idle when ESP32 not driving).
- All others: SLEWRATE=SLOW, PULLMODE=NONE/UP per slot defaults.

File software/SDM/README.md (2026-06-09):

# SDM — SDRAM driver library + bank test

Apple II software for the Byte Hamr Rev 2 `project_obscurus` card (slot 4). A
reusable Merlin driver library for the card's SDRAM register port, plus a test
that exercises all 1024 banks.

Talks to the always-live `$C0C0–$C0C6` register port directly — **no `PR#4`, no
`$C800` monitor ROM**. The interactive `$C800` monitor and this library are two
independent clients of the same hardware.

## Files

| File | What |
|---|---|
| `SDRAMLIB.S` | The driver. `PUT`-include into any Merlin program. No `ORG`, no zero page. |
| `SDMTEST.S`  | The bank test. `ORG $2000`, `PUT SDRAMLIB`, BRUN it. |
| `SDMTEST` / `SDMTEST.po` | Build artifacts (assembled BIN / bootable disk). |

## Library API (`SDRAMLIB.S`)

Configure the slot with one equate at the top: `SLOT = 4` (→ `SDMBASE = $C0C0`).

**Param variables** (set, then call an entry point):

| Var | Size | Meaning |
|-----|---|---|
| `SDM_BANK` | 2 | bank `$000–$3FF` (high 6 bits ignored) |
| `SDM_ADDR` | 2 | 16-bit offset within the bank |
| `SDM_VAL`  | 1 | value to write / last value read |

**Entry points** (`JSR`):

| Routine | Contract |
|---|---|
| `SDM_READY`  | Bounded wait for ready. **Returns `C=0` ready, `C=1` timeout** (card absent / wrong slot). Caller MUST branch on carry. |
| `SDM_SETBANK`| `SDM_BANK` → bank registers |
| `SDM_SETADDR`| `SDM_ADDR` → addr registers |
| `SDM_WRITE`  | set bank+addr, write `SDM_VAL`, wait |
| `SDM_READ` | set bank+addr, read → `A` and `SDM_VAL`, wait |
| `SDM_WRNEXT` | write `SDM_VAL` at the auto-incremented addr (no addr re-set), wait |
| `SDM_RDNEXT` | read at the auto-incremented addr → `A`/`SDM_VAL`, wait |

**Handshake** is internal: every entry point sets the strobe then spins on
STATUS busy (bit7) until the access completes, so callers never poll manually.

**Auto-increment rules:**
- `addr` advances by one on each *completed access* (a `WRITE`/`WRNEXT` or a
  `READ`/`RDNEXT`). A bare DATA read does not advance — only the library's
  triggered ops do.
- `WRNEXT`/`RDNEXT` need a prior `SETADDR` (or `WRITE`/`READ`) to establish the
  start address; the hardware then walks forward by one per call.
- **No bank carry on wrap:** the 16-bit `addr` wraps `$FFFF→$0000` within the
  same bank. A walk past `$FFFF` needs an explicit `SETBANK`+`SETADDR`.

**Invariant:** the library uses only plain absolute `STA`/`LDA $C0Cx` (never
indexed) — a single `nDEVICE_SELECT` pulse each, dodging the `STA abs,X`
dummy-read double-count. Preserve this in any addition.

## Using it from your own Merlin source (on the Apple II)

```
        ORG $2000
        ...
        LDA #$22 : STA SDM_ADDR : LDA #$4D : STA SDM_ADDR+1   ; offset $4D22
        LDA #$00 : STA SDM_BANK : STA SDM_BANK+1               ; bank 0
        LDA #$AA : STA SDM_VAL
        JSR SDM_WRITE
        JSR SDM_READ        ; A = byte read back
        ...
        PUT SDRAMLIB        ; include the library (first is cleanest)
```
On disk the file is named **`SDRAMLIB.S`** (TXT, sequential, high-bit). Merlin-Pro
auto-appends `.S` to Load/Save/`PUT`/`USE`, so `L SDRAMLIB` and `PUT SDRAMLIB`
both resolve `SDRAMLIB.S`. (If a file ever lands without the `.S` suffix, Merlin
reports `46 FILE NOT FOUND` — rename it via the Disk command: `RENAME
SDRAMLIB,SDRAMLIB.S`.) Note: AppleCommander stamps TXT files with record length
$2000 by default — the build forces `--aux 0` (sequential), because a
random-access (`L=8192`) text file makes ProDOS copy utilities read past EOF and
crash.

## The bank test (`SDMTEST.S`)

Two-phase sweep over offsets `$0000–$0009` of every bank `0..1023`:
`expected(bank,off) = lo(bank) EOR hi(bank) EOR off EOR $5A`.
- **Phase 1** writes the expected value to every (bank, offset).
- **Phase 2** reads every (bank, offset) back and compares.

Writing *everything* before reading *anything* is what catches **bank aliasing**
(a dropped/stuck bank-address line) — an immediate read-after-write would mask
it. The value folds both bank bytes, so any **single-bit** bank-decode fault
yields a different expected value and is caught. (An 8-bit value can't uniquely
tag 1024 banks, so multi-bit aliases — banks ≥2 bits apart — are not
distinguished; those aren't reachable by a single-bit fault anyway.)

Output: `SDM BANK TEST` banner, a `.` every 64 banks, the first 16 mismatches as
`bbbb/oo ee gg` (bank/offset expected got), then `PASS` or `nnnn FAILURES`
(hex). `NO CARD` if `SDM_READY` times out (no hang).

## Build & run

```bash
make sdmtest        # assemble SDMTEST.S (+ SDRAMLIB) -> software/SDM/SDMTEST
make sdmdisk        # build bootable software/SDM/SDMTEST.po (BIN + lib source)
```
Deliver: copy `software/SDM/SDMTEST.po` to the ADTPro disks folder, send it to a
5.25" floppy, boot it (lands at `]`), then:
```
BRUN SDMTEST
```

## Bench verification checklist

1. Boot `SDMTEST.po` → `]` → `BRUN SDMTEST`.
2. Expect: `SDM BANK TEST`, ~16 `.` per phase, then **`PASS`**.
3. **Negative test** (proves the test actually checks): in `SDMTEST.S` change
   phase-2's `CALCEXP` constant `$5A`→`$5B` so every read mismatches → `make
   sdmdisk` → expect `FAILURES` count `2800` (hex = 10240) with the first 16
   mismatch lines, then revert.
4. Card absent at boot → `NO CARD` (not a hang, not a fail count).
5. Capture the screen via the `obs-screenshot` skill.

## Notes

- This is host-side software only — no FPGA rebuild or flashing.
- The card RTL is `gateware/rev2/project_obscurus/`; the interactive monitor is
  separate (`PR#4`).

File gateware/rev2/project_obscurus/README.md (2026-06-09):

# project_obscurus

Apple II SDRAM monitor for the Byte Hamr Rev 2. A self-contained 6502 monitor
in the card's `$C800` expansion ROM does live random-access read/write to the
full 64 MB SDRAM through a `$C0Cx` register port, with 64 KB bank switching.
No disk image, no FujiNet, no external probing — everything ships in the
bitstream and runs on the Apple II keyboard + screen. Slot 4 hardcoded.

Foundation for later "hardware support for software" experiments. (Supersedes
the original boot-time "HELLO, WORLD! / HELLO, SDRAM!" string demo.)

## What it does

On power-on the `sdram_ctrl` controller initializes SDRAM (precharge, 2×
refresh, mode register CL=2 / burst=1) and then idles, servicing one byte
read/write per request with a free-running, priority refresh. From the Apple II:

```
PR#4
```

does `JSR $C400`. The `$C400` stub **arms the `$C800` expansion ROM** (writes
`$AA` to `$C0C7`), restores the BASIC output vector (`CSW = $FDF0` / COUT1) so
screen output works, then `JMP $C800` into the monitor. The monitor prints a
banner + `*` prompt and accepts commands:

| Command | Action |
| --- | --- |
| `R aaaa` | Read one byte; prints `aaaa: bb` |
| `W aaaa bb` | Write byte `bb` to offset `aaaa` in current bank  |
| `B bbb` | Set bank (`$000`–`$3FF`) |
| `D aaaa` | Dump 16 bytes from `aaaa` (hex + ASCII) |
| `T` | Run the 1024-bank sweep; prints `TEST PASS`/`nnnn TEST FAIL` |
| `Q` | Disarm `$C800` and return to BASIC |

All numbers are hex. `Q` jumps to a `DISARM` routine at `$C420` in the always-live
slot ROM, which writes `$AA` to `$C0C8` and `RTS`es to BASIC.

## Expansion ROM arming (the `$C800` bus-contention fix)

`$C800–$CFFF` is a **shared** Apple expansion-ROM bus. The card is **silent**
there by default — it only drives it when software arms it:

- **Arm:** write `$AA` to `$C0C7`. **Disarm:** write `$AA` to `$C0C8`. Any other
  value is ignored (symmetric magic guard).
- **Reset / Ctrl-Reset / POR auto-disarm** — a crash recovers to silent.
- The card drives `$C800–$CFFF` only when `rom_en & rom_armed`. With `rom_armed=0`
  by default, **CATALOG, file copies, and disk I/O never collide** with the //e
  internal ROM or other cards (this was the `$CEF3`-crash bug).
- Unused expansion ROM (`$CA08–$CFFE`) is filled with `$60` (RTS), so a stray
  fetch returns harmlessly.

**Software contract:**
- **SDRAM data access (`$C0C0–$C0C6`) never arms** — it's slot-gated and always
  safe. `SDMTEST`/`SDRAMLIB` use only this path.
- **Arm only to run `$C800` ROM code** (`arm → run → disarm`). Keep the window
  short; don't do disk I/O or call other `$C800` firmware while armed (`SEI` if an
  IRQ could touch `$C800`). `rom_en` must also be set (a `$C4xx` access) to drive
  `$C800` — `PR#4` does this via `JSR $C400`.
- Timing: `rom_armed` settles in ~80 ns (≪ one 6502 instruction) — no delay needed
  after `STA $C0C7`. `SDRAMLIB` provides `SDM_ROMON`/`SDM_ROMOFF` helpers.

## Memory model

- SDRAM AS4C32M16 = 32M × 16 = **64 MB**, **byte-packed** (two bytes per 16-bit
  word, DQM-selected): `phys_word = phys_byte[25:1]`, `phys_byte[0]` picks the
  lane.
- Physical byte address = `{bank[9:0], addr[15:0]}` = 26 bits = **1024 banks of
  64 KB**. Each bank is a full 6502-style 64 KB space; `R 4D22` reads offset
  `$4D22` inside the selected bank.

## Register port (slot 4, `$C0Cx`)

| Address | R/W | Name | Description |
| --- | --- | --- | --- |
| `$C0C0` | W | ADDR_LO | `addr[7:0]` |
| `$C0C1` | W | ADDR_HI | `addr[15:8]` |
| `$C0C2` | W | BANK_LO | `bank[7:0]` |
| `$C0C3` | W | BANK_HI | `bank[9:8]` |
| `$C0C4` | W | TRIG_RD | Write any byte → start SDRAM read at `{bank,addr}`|
| `$C0C5` | R | STATUS | **bit7 = busy**, **bit6 = ready**; others 0 |
| `$C0C6` | W | DATA | Write → SDRAM write at `{bank,addr}` |
| `$C0C6` | R | DATA | Read → last SDRAM read result (RD_HOLD) |
| `$C0C7` | W | ROM_ARM | Write `$AA` → arm `$C800` ROM (other values ignored) |
| `$C0C8` | W | ROM_DISARM| Write `$AA` → disarm `$C800` ROM |
| `$C0C9-$C0CF` | R/W | SCRATCH | Loopback registers |
| `$C400-$C4FF` | R | slot ROM  | `$C400` stub (`slot_rom.S`) |
| `$C800-$CFFF` | R | exp ROM | monitor program (`monitor.S`); `$CFFF` unused |

**Handshake.** SDRAM latency >> one 6502 bus cycle, so there is no in-cycle
round-trip. Sequence: set ADDR/BANK → strobe (TRIG_RD or DATA write) → **poll
STATUS until bit7 (busy) clears** → read DATA / done.

- `BIT $C0C5` lands busy→N and ready→V, so polling is branchless:
  `BIT $C0C5 : BMI *-3` (loop while busy); `BIT $C0C5 : BVC *-3` (wait ready).
- `busy` is **sticky** from the strobe until the first STATUS read after the
  access completes, so the first poll always observes busy=1 even for a fast op.
- `addr` **auto-increments on access completion** (not on the DATA read), so a
  `D` dump loop is: set start addr once, then `{strobe; poll; read}` ×N. A bare
  DATA read with no strobe does not advance `addr`.

`STA $C0Cx` / `LDA $C0Cx` absolute = 4 cycles, single `nDEVICE_SELECT` pulse —
no indexed dummy-read double-step. (CLAUDE.md "6502 Bus Timing Gotchas".)

## Expansion ROM enable

`rom_en` flip-flop: set on `$Cn00` access (`nI_O_SELECT`), cleared on `$CFFF`
access. Gates `~nI_O_STROBE` into both the U12 `DATA_OE` and the `$C800` data
drive. **`$CFFF` is reserved unused** — touching it disables the ROM; the
monitor (520 bytes) lives only in `$C800–$CA07`.

## Files

| File | Description |
| --- | --- |
| `project_obscurus_top.v`  | Top — clock, POR, bus iface, monitor_regs, exp ROM  |
| `sdram_ctrl.v` | SDRAM controller: init, priority refresh, byte R/W  |
| `sim/sdram_model.v` | Behavioral SDRAM model (bounded dense) for sim |
| `sdram_ctrl_tb.v` | Unit TB for `sdram_ctrl` |
| `project_obscurus_tb.v` | Integration TB (register-port protocol) |
| `slot_rom.S` / `.mem` | `$C400` stub (Merlin32) |
| `monitor.S` / `.mem` | `$C800` monitor program (Merlin32) |

## Build & run

```bash
make clean && make DESIGN=project_obscurus REV=rev2     # bitstream
make DESIGN=project_obscurus REV=rev2 sim               # integration TB
make unit DESIGN=project_obscurus MODULE=sdram_ctrl REV=rev2   # controller unit TB
make assemble ASM_SRC=gateware/rev2/project_obscurus/monitor.S # reassemble monitor
```

> **iverilog note:** this machine's Icarus 13.0 hangs on `-g2009`/`-g2012`; the
> build uses default `-g2005`. The SDRAM sim model is a bounded dense array
> (64K words, banks 0–1) rather than a SystemVerilog associative array.

To program flash (only when you intend to flash):
`make DESIGN=project_obscurus REV=rev2 prog-flash`. After flashing, type `PR#4`.

## Bench verification checklist

**The regression that motivated the arm switch (do this first):**
1. Card installed, **without** `PR#4`: `CATALOG`, then **copy a file** (CopyUtils)
   → no crash, no `$CEF3`, disks intact. (The card is disarmed = silent on `$C800`.)

**Monitor + test:**
2. `PR#4` → monitor banner + `*` prompt.
3. `W 0000 AA`, then `R 0000` → `0000: AA`.
4. `B 1`, `R 0000` → value ≠ `AA` (bank isolation); `B 0`, `R 0000` → `AA`.
5. `D 0000` → 16-byte hex + ASCII dump, first byte `AA`.
6. `T` → `TEST PASS`.
7. `Q` → returns to BASIC `]` prompt.
8. After `Q`: `CATALOG` / copy a file again → still clean (card re-disarmed).
9. Ctrl-Reset mid-monitor → back to BASIC, card silent, disks fine.

Capture via the `obs-screenshot` skill.

## Why "obscurus"

Placeholder name — this is the foundation. The next thing built on top will
need a real name.

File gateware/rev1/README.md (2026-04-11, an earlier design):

# Gateware

FPGA designs for the Byte Hamr Apple II expansion card, targeting a Lattice ECP5-85F with 64 MB SDRAM, 16 MB SPI flash, and a 12-pin GPIO header.

All designs are built with the open-source ECP5 toolchain: **Yosys** (synthesis) -> **nextpnr** (place & route) -> **ecppack** (bitstream).

## Designs

| Design | Purpose | Clocks |
|---|---|---|
| [block_hamr](block_hamr/) | ProDOS block storage (SDRAM + flash persistence) | 7M / 25M |
| [flash_hamr](flash_hamr/) | SD card disk system with PicoRV32 CPU and FatFS | 7M / 25M |
| [smart_hamr](smart_hamr/) | IWM/SmartPort disk controller (ESP32 FujiNet bridge) | 7M only |
| [logic_hamr](logic_hamr/) | 8-channel logic analyzer with Apple II display | 25M |
| [signal_check](signal_check/) | Board bring-up: SDRAM test, GPIO walking 1s, bus monitor | 25M |
| [pattern_rom](pattern_rom/) | SDRAM read-path validation (test patterns) | 25M |
| [sdram_test](sdram_test/) | Direct register-driven SDRAM access (full 25-bit addressing) | 25M |
| [sdram_bank](sdram_bank/) | 4-bank independent SDRAM addressing PoC | 25M |
| [constraints](constraints/) | Shared pin constraint file (ECP5 LPF) | -- |

## Quick Start

```bash
make DESIGN=<name>              # Full bitstream build
make DESIGN=<name> prog         # JTAG program (volatile)
make DESIGN=<name> prog-flash   # Flash program (persistent)
make DESIGN=<name> sim          # Testbench simulation
make DESIGN=<name> report       # Timing and utilization summary
```

Default design (no `DESIGN=` argument) is `signal_check`.

## Disk Image Management

```bash
make DESIGN=block_hamr prog-flash-with-image DISK_IMAGE=path/to/disk.po
make write-flash DISK_IMAGE=new.po    # Swap disk without bitstream rebuild
make read-flash                       # Dump image from flash
```

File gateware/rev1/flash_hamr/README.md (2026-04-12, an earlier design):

# Flash Hamr

Full-featured SD card-based disk system with an embedded PicoRV32 (RISC-V) CPU running FatFS, a Merlin picker menu, and multi-drive support.

## What It Does

- Embeds a **PicoRV32 RISC-V CPU** running at 25 MHz with 32KB IMEM and 16KB DMEM
- Reads `.po`/`.2mg` disk images from **SD card** via SPI using FatFS (FAT32)
- Presents up to **4 drives** (S4D1-S4D4) to the Apple II as ProDOS block devices
- **Magic block interception**: CPU fills the block buffer for catalog/metadata blocks (`$FFFF`/`$FFFE`)
- **On-demand caching**: Optionally intercepts all reads for performance
- **Menu volume**: Picker program + ProDOS on SPI flash for disk image selection at boot
- Toggle-based **mailbox CDC** for safe 7 MHz / 25 MHz cross-domain communication

## Architecture

```
PicoRV32 CPU (25 MHz)
  +-- IMEM (32KB, firmware.mem)
  +-- DMEM (16KB, stack/heap)
  +-- SPI Master -> SD card (GPIO1-4)
  +-- UART TX -> serial debug
  +-- GPIO output [7:0]

Apple II Bus (7.16 MHz)
  +-- Boot ROM (4KB, $C0C0/$C400/$C800)
  +-- bus_interface (register file)
  |     +-- Block request arbiter
  |     +-- Magic block detection
  |     +-- Cache gating
  +-- Block buffer (512B dual-port)
  +-- SDRAM (shared with CPU)

Mailbox (toggle-CDC): 7 MHz <-> 25 MHz
  - Command/status, persist requests, unit metadata
```

## CPU Memory Map

| Address | Size | Purpose |
|---|---|---|
| `0x00000000` | 32KB | IMEM (firmware) |
| `0x10000000` | 16KB | DMEM (stack/heap) |
| `0x20000000` | -- | SPI Master (SD card) |
| `0x30000000` | -- | Mailbox |
| `0x40000000` | -- | SDRAM port |
| `0x50000000` | -- | UART TX |
| `0x60000000` | -- | Block buffer port |
| `0x70000000` | -- | GPIO output |

## Key Modules

### Gateware
| File | Purpose |
|---|---|
| `flash_hamr_top.v` | Top-level integration (CDC, multiplexing) |
| `cpu_soc.v` | PicoRV32 wrapper (IMEM, DMEM, peripherals) |
| `picorv32.v` | PicoRV32 CPU core |
| `bus_interface.v` | Enhanced register file (multi-unit support) |
| `block_buffer.v` | 512B dual-port BRAM |
| `boot_loader.v` | Flash-to-SDRAM copy, ProDOS header parsing |
| `sdram_controller.v` | SDRAM interface |
| `sdram_arbiter.v` | Mux boot/block/CPU requests |
| `mailbox.v` | Toggle-CDC mailbox |
| `spi_master.v` | SD card SPI interface |
| `uart_tx.v` | Serial debug output |

### Firmware (C / RISC-V)
| File | Purpose |
|---|---|
| `main.c` | Main program (SD mount, FatFS, catalog) |
| `spi_sd.c/h` | SD card SPI driver |
| `diskio.c/h` | FatFS disk I/O layer |
| `ff.c/h` | FatFS filesystem library |
| `hal.h` | Hardware abstraction layer |
| `crt0.S` | RISC-V startup |
| `linker.ld` | Linker script |

### 6502 Boot
| File | Purpose |
|---|---|
| `hamr_rom.S` | ProDOS block driver (Merlin32) |
| `picker.S` | Menu picker (selects disk image) |
| `images/menu.po` | ProDOS disk image with picker + ProDOS |

## Build

```bash
make DESIGN=flash_hamr              # Build gateware
make DESIGN=flash_hamr prog         # JTAG program
make DESIGN=flash_hamr prog-flash   # Flash program (persistent)
make menu                           # Build menu volume
make DESIGN=flash_hamr report       # Timing and utilization
make DESIGN=flash_hamr sim          # Testbench simulation
```

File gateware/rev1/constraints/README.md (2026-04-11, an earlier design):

# Constraints

Shared FPGA pin constraints for the Byte Hamr ECP5-85F board.

## What It Contains

- `byte_hamr.lpf` -- Base pin constraint file (Lattice LPF format)

## Pin Groups

- **Apple II bus**: Address, data, and control lines (PHI0, sig_7M, R/W, nDEVICE_SELECT, nI_O_SELECT, nI_O_STROBE)
- **SDRAM**: Address, data, and control (CKE, CLK, nCS, nRAS, nCAS, nWE, BA, DQM)
- **SPI flash**: CS, CLK, MOSI, MISO
- **GPIO header**: 12 pins for expansion/debugging
- **Clock inputs**: sig_7M, PHI0, CLK_25MHz

Each design may include its own `.lpf` file for design-specific overrides; the build system checks for a design-specific file first, then falls back to this base.

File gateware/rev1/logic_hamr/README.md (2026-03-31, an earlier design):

# Logic Hamr

8-channel digital logic analyzer for the Apple II, implemented on the Byte Hamr FPGA card. Captures digital signals at 1 MHz, stores raw samples in SDRAM, and regenerates decimated display data in Apple II HIRES format.

## What It Does

Logic Hamr turns the Byte Hamr into a self-contained logic analyzer:

1. **Capture** - Arms on a configurable trigger (rising/falling edge on any channel), captures 8 bits of digital input at 1 MHz into SDRAM with a pre-trigger window
2. **Regenerate** - Processes raw samples through 8 parallel `decimate_pack` engines that convert to Apple II HIRES 7-bit byte format with configurable zoom
3. **Read** - Apple II software reads the display buffer (8 channels x 38 bytes) and renders waveforms to screen

Key capabilities:
- 4 window presets: 38us, 88us, 133us, 266us capture depth
- Configurable pre/post trigger split
- Rising or falling edge trigger on any channel
- **Re-zoom without recapture** - regenerate the same raw data at different zoom levels
- Built-in debug pattern generator with 8 test frequencies

## Register Map

Base address: `$C0C0` (slot 4)

| Offset | Name | R/W | Description |
|---|---|-----|---|
| `$00` | CHANNEL | R/W | Select channel (0-7) for display read |
| `$01` | ADDR | R/W | Byte offset (0-37) within channel |
| `$02` | DATA | R | Display buffer read result |
| `$03` | CMD | W | `$02` = read, `$10` = regenerate, `$FF` = reset |
| `$04` | STATUS | R | init_done, busy, armed, captured, regen_done |
| `$05` | STRETCH | R | Current zoom stretch factor (1-7) |
| `$06` | TRIG_CH | R/W | Trigger channel (0-7) |
| `$07` | TRIG_MODE | R/W | `0` = rising edge, `1` = falling edge |
| `$08` | WINDOW | R/W | Window preset (0-3) |
| `$09` | ARM | W | Arm capture |
| `$0A` | DEBUG_EN | R/W | Enable debug test patterns |

## Probe Inputs

Connect digital signals to the GPIO header:

| GPIO | Channel |
|---|---|
| GPIO4 | Channel 0 |
| GPIO5 | Channel 1 |
| GPIO6 | Channel 2 |
| GPIO7 | Channel 3 |
| GPIO8 | Channel 4 |
| GPIO10 | Channel 5 |

GPIO1 outputs a 250 kHz heartbeat. GPIO2/GPIO3 indicate ready/armed status.

## Architecture

```
Probes (GPIO) --> Capture Engine --> SDRAM (raw samples)
                                       |
                                       v
Apple II <-- Bus Interface <-- Regen Engine (8x parallel decimate_pack)
                                       |
                                       v
                               SDRAM (display buffer)
```

- **Capture engine**: Pre-trigger BRAM circular buffer + edge detector + SDRAM streaming
- **Regen engine**: 8 parallel `decimate_pack` instances process all channels in a single SDRAM pass
- **SDRAM controller**: 25 MHz, CAS latency 2, with pause_refresh during capture
- **Clock**: 25 MHz system, 1 MHz sample strobe, PHI0 sampled (not used as clock)

## Makefile Commands

All commands run from the project root (`project_byte_hamr/`).

```bash
# Build
make DESIGN=logic_hamr         # Build complete bitstream
make DESIGN=logic_hamr synth   # Synthesis only
make DESIGN=logic_hamr pnr     # Place & route only
make DESIGN=logic_hamr bit     # Generate bitstream

# Program
make DESIGN=logic_hamr prog        # JTAG (volatile)
make DESIGN=logic_hamr prog-flash  # SPI flash (persistent)

# Simulate
make DESIGN=logic_hamr sim         # Run testbench
make DESIGN=logic_hamr wave        # Simulation + GTKWave

# Unit test a specific module
make DESIGN=logic_hamr unit MODULE=capture_engine
make DESIGN=logic_hamr unit MODULE=decimate_pack
make DESIGN=logic_hamr unit-wave MODULE=regen_engine

# Reports
make DESIGN=logic_hamr report      # View build summary
make clean                         # Remove build artifacts
```

## Files

| File | Description |
|---|---|
| `logic_hamr_top.v` | Top-level integration - phase state machine, clock gen, probe sync |
| `capture_engine.v` | Trigger detection, pre-trigger buffer, raw sample capture |
| `regen_engine.v` | Parallel decimation controller - reads SDRAM, feeds 8 channels |
| `decimate_pack.v` | Converts 1-bit samples to HIRES 7-bit bytes with stretch/zoom |
| `sdram_controller.v` | SDRAM init, refresh, read/write with pause_refresh support |
| `bus_interface.v` | Apple II register file with PHI0 synchronization |
| `logic_hamr.lpf` | Pin constraints (design-specific) |

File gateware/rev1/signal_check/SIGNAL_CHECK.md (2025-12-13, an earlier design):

# Signal Check

Board bring-up test gateware for the Byte Hamr.

## Purpose

Validates that all major interfaces are functional after assembly:

1. **SDRAM** - Write/read pattern test to 8 addresses
2. **GPIO** - Walking 1s pattern on GPIO5-12 (0.5s per step)
3. **Apple II Bus** - Monitors PHI0 for bus activity

## Status Indicators

| GPIO | Signal | Meaning |
|---|---|---|
| GPIO1 | Heartbeat | Blinks at 1Hz when FPGA is running |
| GPIO2 | SDRAM Pass | Solid ON = SDRAM test passed |
| GPIO3 | Apple Activity | ON when PHI0 transitions detected |
| GPIO4 | Error | ON = SDRAM test failed |
| GPIO5-12 | Walking 1s | Rotating pattern for scope/LED verification |

## Build

From the project root:

```bash
make                    # Build signal_check (default)
make prog               # Program via JTAG (volatile)
make prog-flash         # Program SPI flash (persistent)
```

## Simulation

A testbench is included that simulates the SDRAM and Apple II bus:

```bash
make sim                # Run simulation
make wave               # Run simulation and open GTKWave
```

The testbench (`signal_check_tb.v`) includes:
- 25 MHz system clock
- Simple SDRAM model that stores/returns written data
- PHI0 toggling at ~1 MHz to simulate Apple II bus activity

VCD output is written to `build/signal_check_tb.vcd`.

## Expected Results

On power-up or programming:

1. GPIO1 starts blinking immediately (FPGA alive)
2. After ~200us, SDRAM initialization begins
3. After a few ms, GPIO2 lights up (SDRAM pass) OR GPIO4 lights up (fail)
4. If Apple II is connected and running, GPIO3 will be lit

## Files

| File | Description |
|---|---|
| `signal_check_top.v` | Top-level module with SDRAM controller, bus monitor, GPIO driver |
| `signal_check_tb.v` | Testbench with SDRAM model and Apple II bus simulation |

## Notes

- The signal "7M" from the schematic is mapped to `sig_7M` in Verilog (identifiers can't start with numbers)
- This test does NOT drive the Apple II data bus - it only observes
- DMA_OUT and INT_OUT are held low (inactive)
- The SDRAM test is basic - it doesn't test all memory or all patterns

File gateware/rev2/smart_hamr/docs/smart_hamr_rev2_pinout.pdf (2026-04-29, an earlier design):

================================================================================ SMART HAMR REV 2 -- DAUGHTER BOARD PINOUT REFERENCE
FujiNet bridge for Byte Hamr Rev 2. ESP32-WROVER-E + microSD breakout + ribbon cable to Byte Hamr's J1 GPIO header.
Design files:
gateware/rev2/smart_hamr/smart_hamr_top.v gateware/rev2/smart_hamr/smart_hamr.lpf ================================================================================
1. ESP32-WROVER-E DEVKIT -- PIN MAP (USB pointing UP) ================================================================================ Hold the module with the USB-C jack at the top. CLK/D0 sit at the top-left corner; 5V/CMD at the top-right.
[ USB-C jack at top ]
+-----------------------+
1 | | CLK (IO6, FLASH) | | <-- top-left corner
2 | | D0 | (IO7, FLASH) | | | (flash pins -- DO NOT USE)
3 | | D1 | (IO8, FLASH) | |
4 | | IO15 | | |
5 | | IO2 | | |
6 | | IO0 | | |
7 | | IO4 | | |
8 | | IO16 | | |
9 | | IO17 | | |
10 | | IO5 | SD-CS | |
11 | | IO18 | SD-SCK | |
12 | | IO19 | SD-MISO | |
13 | | GND | | |
14 | | IO21 | -- _enbl2 | | <-- LEFT-edge straggler #1
15 | | IO3 / RX0 | | | (UART RX, leave free)
16 | | IO1 / TX0 | |
17 | | IO22 | -- wrdata | | <-- LEFT-edge straggler #2
18 | | IO23 | SD-MOSI | |
19 | | GND | | <-- bottom-left
+-----------------------+
+-----------------------+
1 | | 5V | | <-- top-right corner
2 | | CMD (IO11, FLASH) | | | (flash pins -- DO NOT USE)
3 | | D3 | (IO10, FLASH) | |
4 | | D2 | (IO9, FLASH) | | | (silkscreen sometimes "D9")
5 | | IO13 | | |
6 | | GND | | |
7 | | IO12 | | |
8 | | IO14 | -- rddata | | | <-- RIGHT-edge cluster
9 | | IO27 | -- sense/ACK |
10 | | IO26 | -- _wrreq | |
11 | | IO25 | | |
12 | | IO33 | -- phase[1] | |
13 | | IO32 | -- phase[0] | |
14 | | IO35 | -- phase[3] | |
15 | | IO34 | -- phase[2] | |
16 | | IO39 / SVN (in only) |
17 | | IO36 / SVP -- _enbl1 | | <-- RIGHT-edge cluster end
18 | | EN | | |
19 | | 3V3 | | <-- bottom-right
+-----------------------+

2. DAUGHTER-BOARD LAYOUT -- PERFBOARD VIEW

[ ESP32 USB jack -- top of perfboard ] +---------------------------------------------------+
| | +--------+ | +-----------------+ | |
| | | | SD | | | | | ESP32 | | | |
| | | HW-... | | | | WROVER-E | | | |
| | | socket | | | | (USB up) | | | |
| | +--------+ | | | | | |
| | \ | | L-edge | R-edge | | |
| | \ | | pins | | pins | | |
| | SD-SPI (CS, | | | | | | | | | | | |
| | SCK, MISO, | | | v | | | v | | | |
| | MOSI, 3V3) | | | "stragglers" | | | |
| | +-----------------------------------------------+
| | | 2 x 20 IDC RIBBON HEADER (to Byte Hamr J1) | |
| | +-----------------------------------------------+
+---------------------------------------------------+ External wires (taped/glued alongside the ribbon):
+5V from Byte Hamr J6 pin 3 (CARD5V) ---> ESP32 VIN
GND from Byte Hamr J6 pin 5 (GND) | ---> ESP32 GND | (optional, redundant
via ribbon)
================================================================================
3. RIBBON HARNESS -- ESP32 -> DAUGHTER IDC -> BYTE HAMR J1 (40-pin, 1:1) ================================================================================ Daughter IDC has GND on every odd pin (1, 3, 5, ...39) and signal on every even pin (2, 4, 6, ...40). The signal row carries GPIO_1 through GPIO_20 in order. Standard 40-conductor ribbon connects pin N <-> pin N.
IDC pin | GPIO_N | FPGA pad | Signal | | Solder to ESP32 pin
--------+---------+----------+--------------+---------------------------
2 | GPIO_1 | P3 (33Ω) | /DEV debug | | (none -- FPGA-only output)
4 | GPIO_2 | P1 | | unused (0) | | --
6 | GPIO_3 | P2 | | unused (0) | | --
8 | GPIO_4 | N1 | | unused (0) | | --
10 | GPIO_5 | M1 | | unused (0) | | --
12 | GPIO_6 | L2 (33Ω) | unused (0) | | --
14 | GPIO_7 | L1 | | unused (0) | | --
16 | GPIO_8 | K3 | | unused (0) | | --
18 | GPIO_9 | K1 | | _enbl2 | | pin 14 (IO21 / WIRE_SDA)
20 | GPIO_10 | K2 | | wrdata | | pin 17 (IO22)
22 | GPIO_11 | J1 (33Ω) | unused (0) | | --
24 | GPIO_12 | H2 | | rddata | | pin 8 (IO14) | *RIGHT col*
26 | GPIO_13 | H1 | | sense/ACK | | pin 9 (IO27) | *RIGHT col*
28 | GPIO_14 | G2 | | _wrreq | | pin 10 (IO26) | *RIGHT col*
30 | GPIO_15 | G1 | | phase[1] | | pin 12 (IO33) | *RIGHT col*
32 | GPIO_16 | F2 (33Ω) | phase[0] | | pin 13 (IO32) | *RIGHT col* 34 | GPIO_17 | F1 | | phase[3] | | pin 14 (IO35) | *RIGHT col*
36 | GPIO_18 | E2 | | phase[2] | | pin 15 (IO34) | *RIGHT col*
38 | GPIO_19 | E1 | | unused (0) | | --
40 | GPIO_20 | D2 | | _enbl1 | | pin 17 (IO36 / SVP) *RIGHT*
IDC odd pins 1, 3, 5, ... 39 -- all GND (40-cond ribbon ground returns)

Notes:
* "(33Ω)" = Byte Hamr's GPIO_1, _6, _11, _16 pads have a 33Ω series-damping resistor between the FPGA pin and the J1 connector. Fine for slow signals (debug, phase[0]) -- avoided for fast serial lines (rddata, wrdata).
* RIGHT-column ESP32 pins drop straight down on the daughter board to the right half of the IDC ribbon header.
* LEFT-column stragglers (_enbl2, wrdata) drop down to the right end of the LEFT half of the ribbon (IDC pins 18, 20).
* The two ESP32 pins labeled "SVP" and "SVN" are input-only. IO36 (SVP)
is fine for _enbl1 (output from FPGA, input to ESP32). ================================================================================
4. SD CARD WIRING (3.3V module, no level shifter) ================================================================================ All four SPI lines connect ESP32 directly to the SD module pins. Power is 3.3V from the ESP32's onboard regulator (pin 19 of the right column). No wires cross the ribbon -- this stays entirely on the daughter board.
SD pin | Signal | ESP32 pin
----------+--------+-----------------------
VCC | | 3V3 | | right col pin 19 (3V3)
GND | | GND | | (any GND pin)
CS | | CS | | left col pin 10 (IO5)
SCK | | SCK | | left col pin 11 (IO18)
MISO | | MISO | | left col pin 12 (IO19)
MOSI | | MOSI | | left col pin 18 (IO23)
================================================================================
5. BYTE HAMR REV 2 -- J1 GPIO HEADER (2x20 IDC) ================================================================================ Top row -- GPIO signals (matches the ribbon when crimped 1:1):
IDC pin: 2 | 4 | 6 | 8 | 10 | 12 | 14 | 16 | 18 | 20
GPIO: | 1 | 2 | 3 | 4 | 5 | 6 | 7 | 8 | 9 | 10
^ | ^
debug | _enbl2 ----+
IDC pin: 22 | 24 | 26 | 28 | 30 | 32 | 34 | 36 | 38 | 40
GPIO: | 11 | 12 | 13 | 14 | 15 | 16 | 17 | 18 | 19 | 20
| | ^ | ^ | ^ | ^ | ^ | ^ | ^ | | ^
rd sense wr | ph1 ph0 ph3 ph2 | _enbl1
Bottom row -- GND on every odd pin (1, 3, 5, ... 39). ================================================================================
6. BYTE HAMR REV 2 -- J6 AUXILIARY POWER HEADER (2x3) ================================================================================ Tap +5V from here for the ESP32 VIN.
J6 pin | Net | Use
-------+----------+----------------------------------------------------------
1 | | CARD-12V | -12V from slot (unused for FujiHamr)
2 | | CARD12V | +12V from slot (unused for FujiHamr)
* 3 | | CARD5V | | +5V from slot --> tap for ESP32 VIN
4 | | CARD-5V | -5V from slot (unused for FujiHamr)
* 5 | | GND | | ground | --> optional second wire for clean return
6 | | +3V3 | | 3.3V from on-board regulator (don't use unless skipping
the ESP32's own regulator -- check budget first)

7. SUMMARY -- WHAT TO BUILD
(a) 40-conductor ribbon, IDC connector each end, straight-through (1:1).
(b) Daughter perfboard:
- ESP32-WROVER-E DevKit, USB at top
- SD breakout module (3V3) on the upper-left
- 2x20 right-angle IDC header on the bottom edge
- 11 wires from ESP32 -> IDC (per section 3 table)
- 5 wires from ESP32 -> SD module (per section 4 table)
(c) Two flying leads from Byte Hamr J6 -> ESP32 VIN/GND, taped/glued alongside the ribbon.
(d) ESP32's own USB cable becomes optional after that -- needed only for serial monitor / firmware reflash. ================================================================================ END OF DOCUMENT
================================================================================

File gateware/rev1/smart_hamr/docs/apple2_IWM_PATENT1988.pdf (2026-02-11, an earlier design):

Apple Computer Inc. Patent : 4_742_448

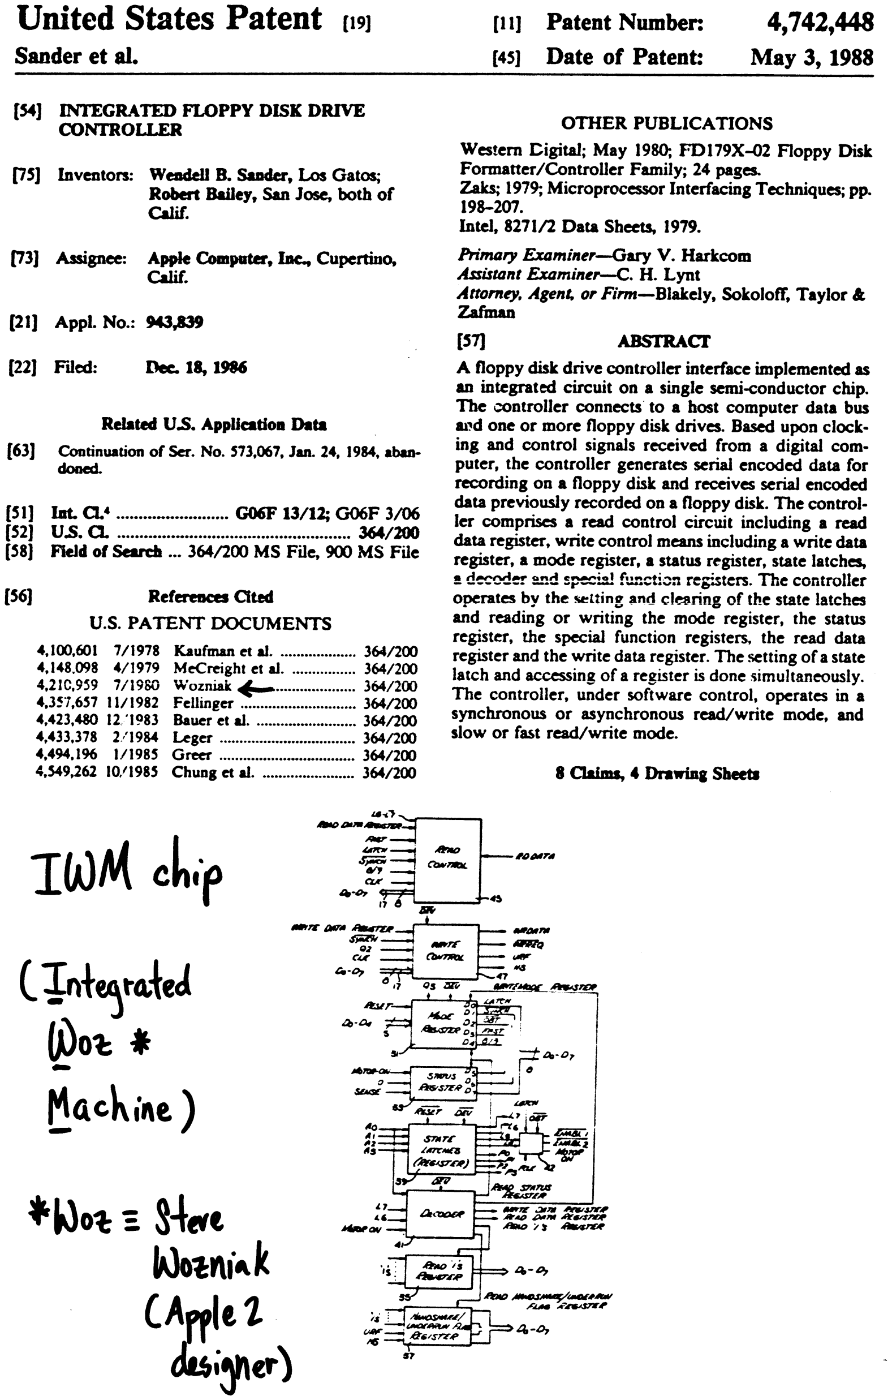
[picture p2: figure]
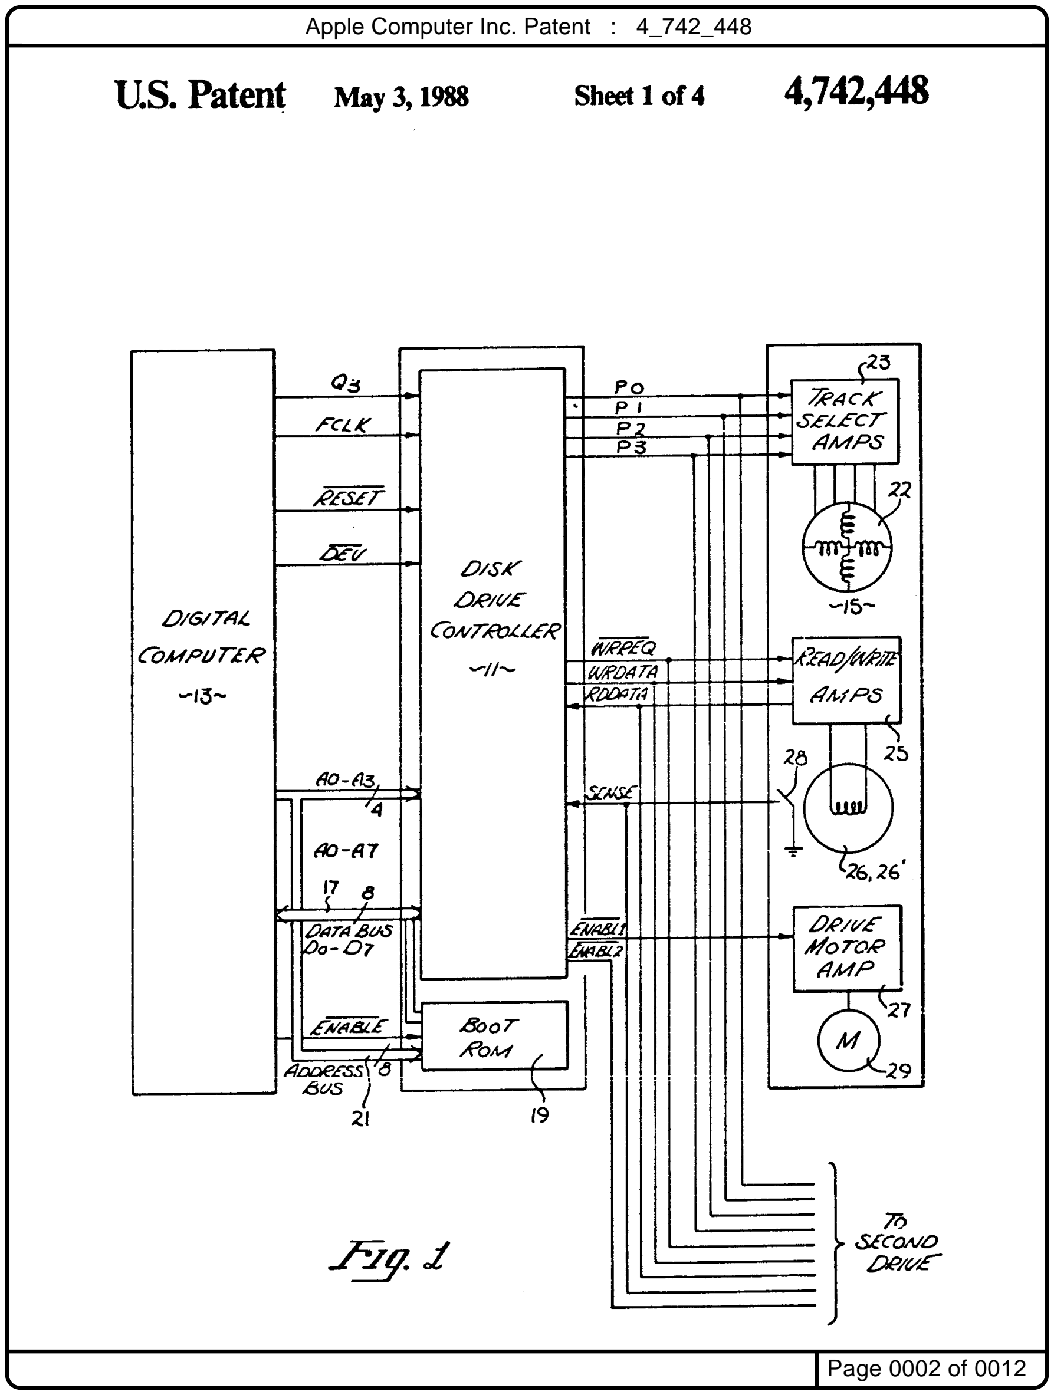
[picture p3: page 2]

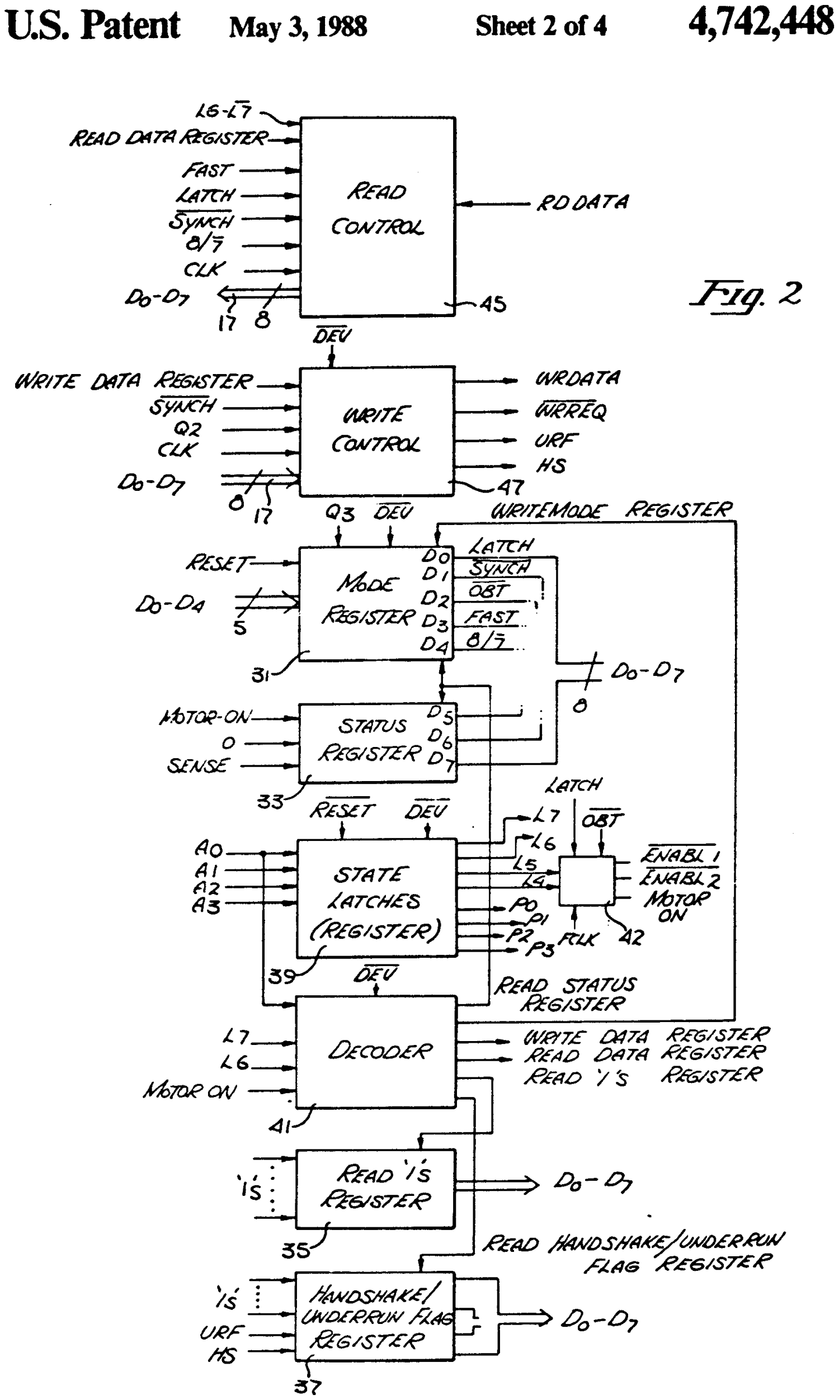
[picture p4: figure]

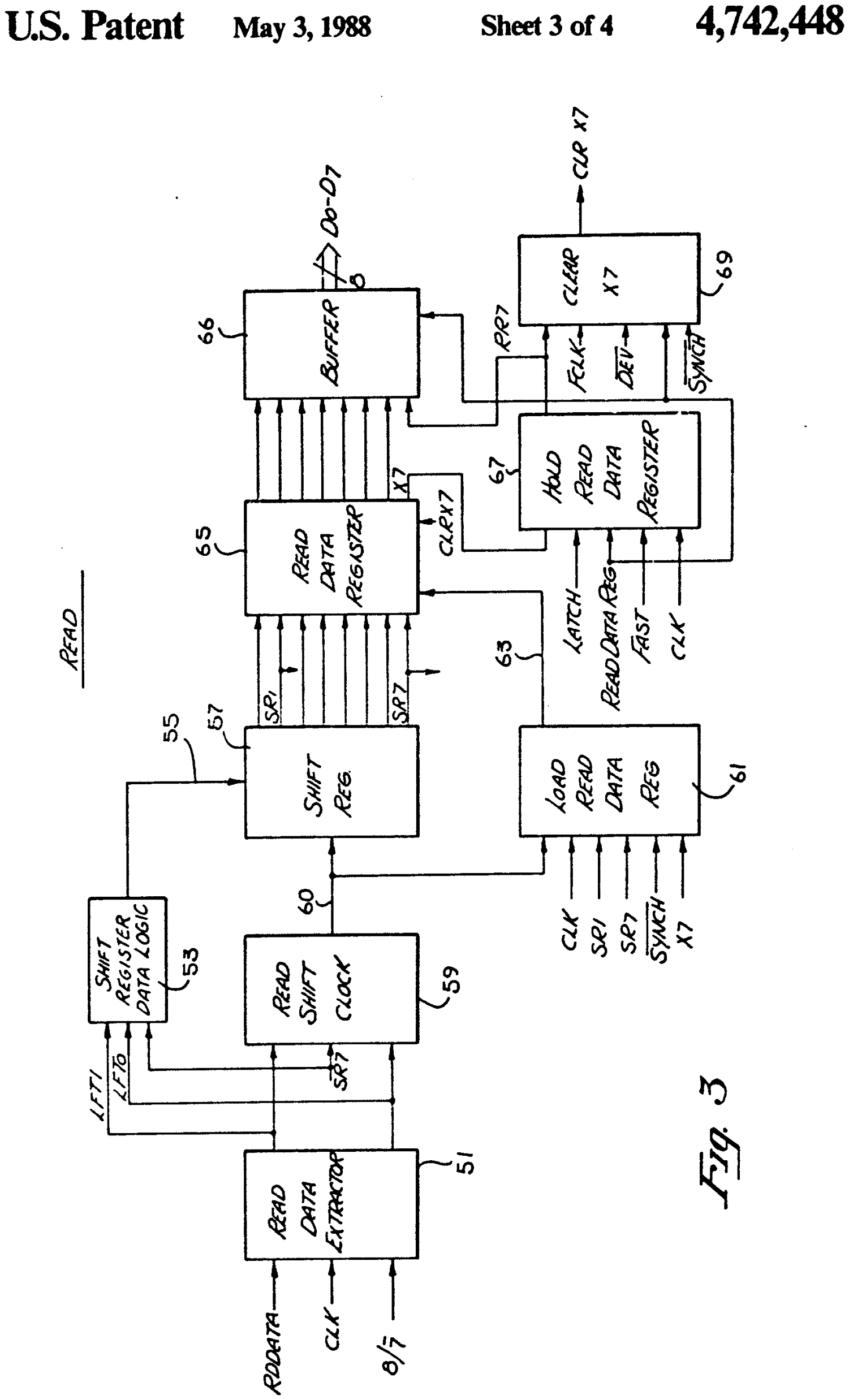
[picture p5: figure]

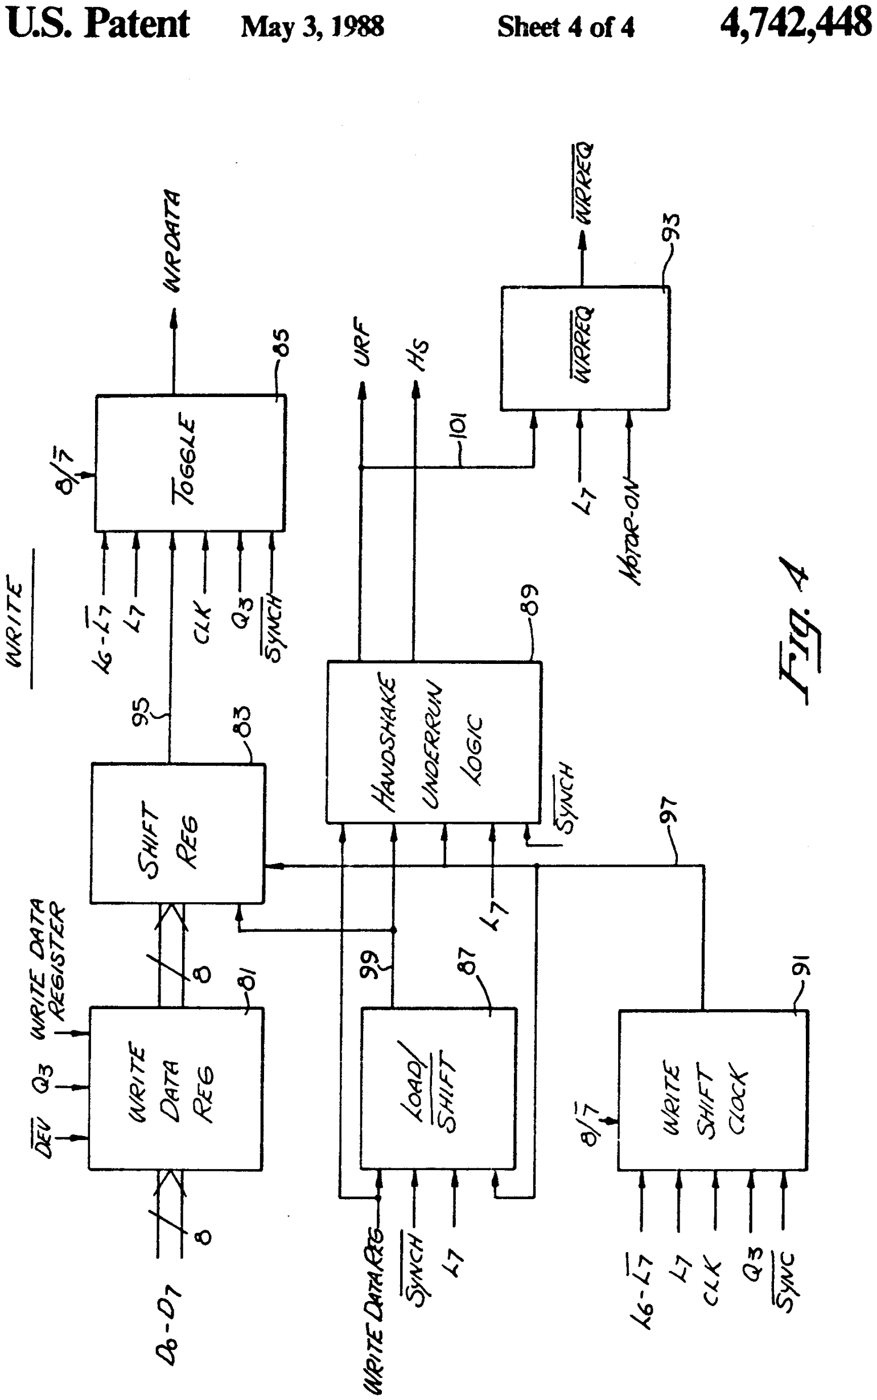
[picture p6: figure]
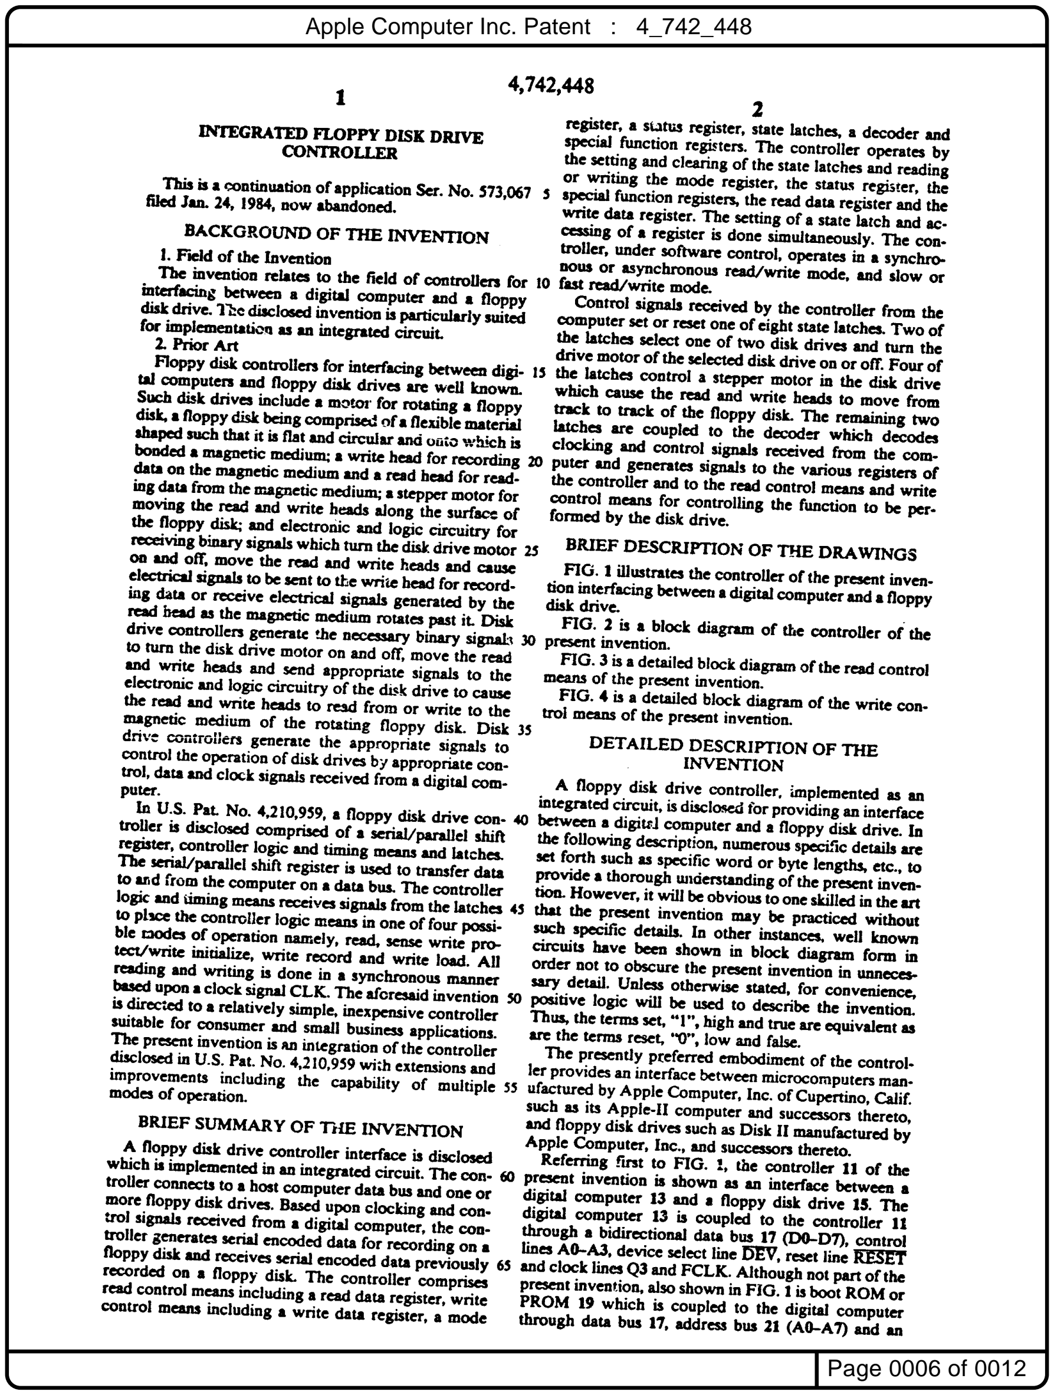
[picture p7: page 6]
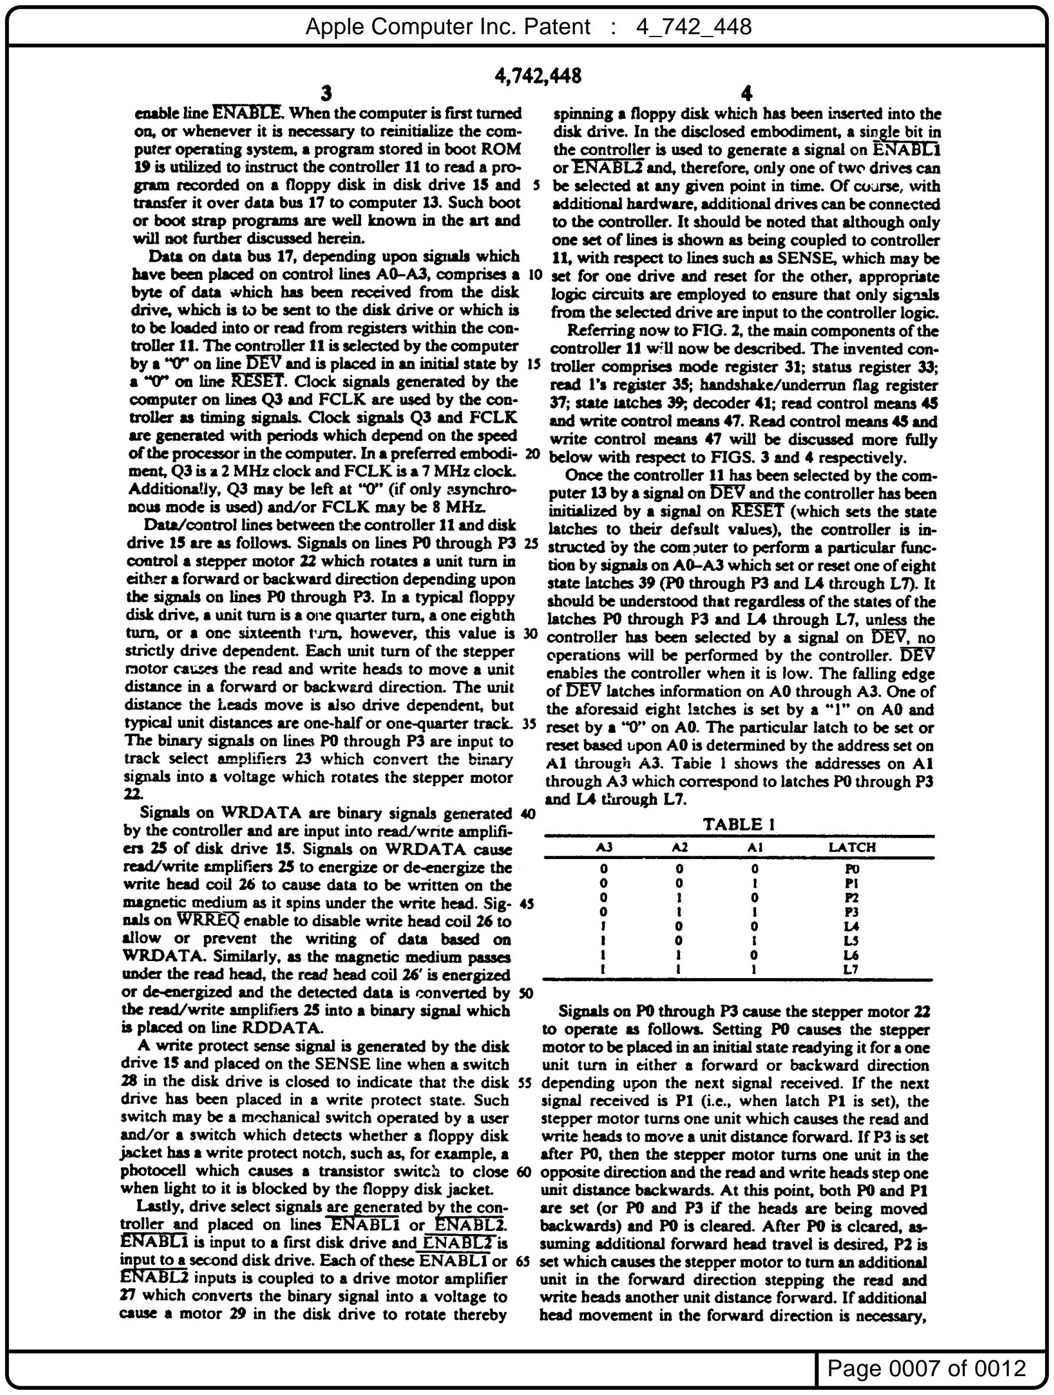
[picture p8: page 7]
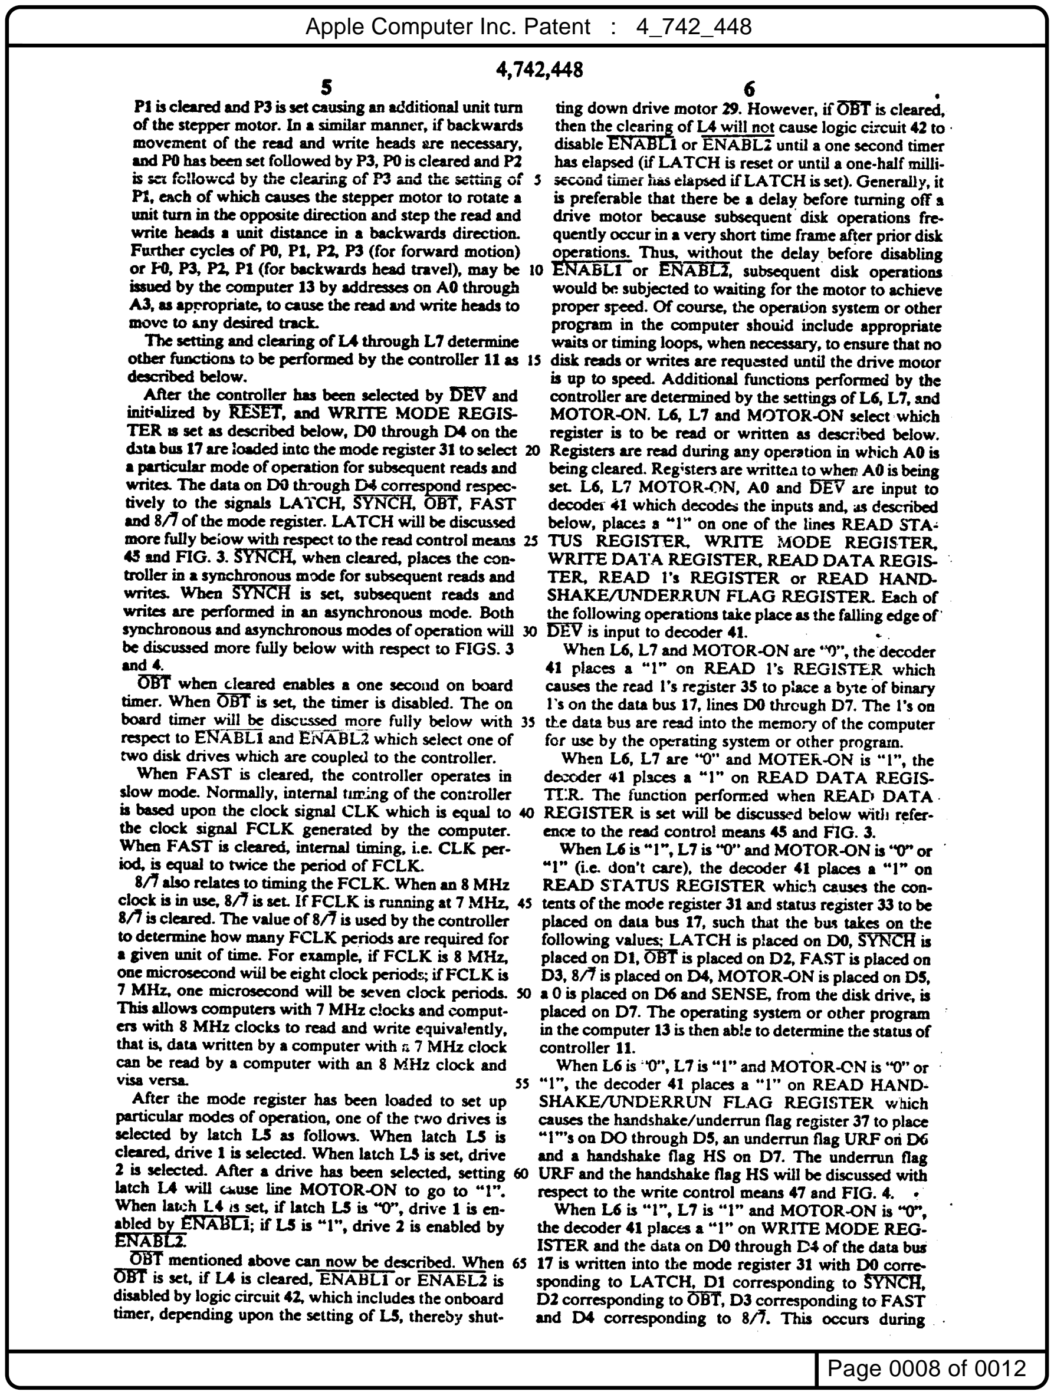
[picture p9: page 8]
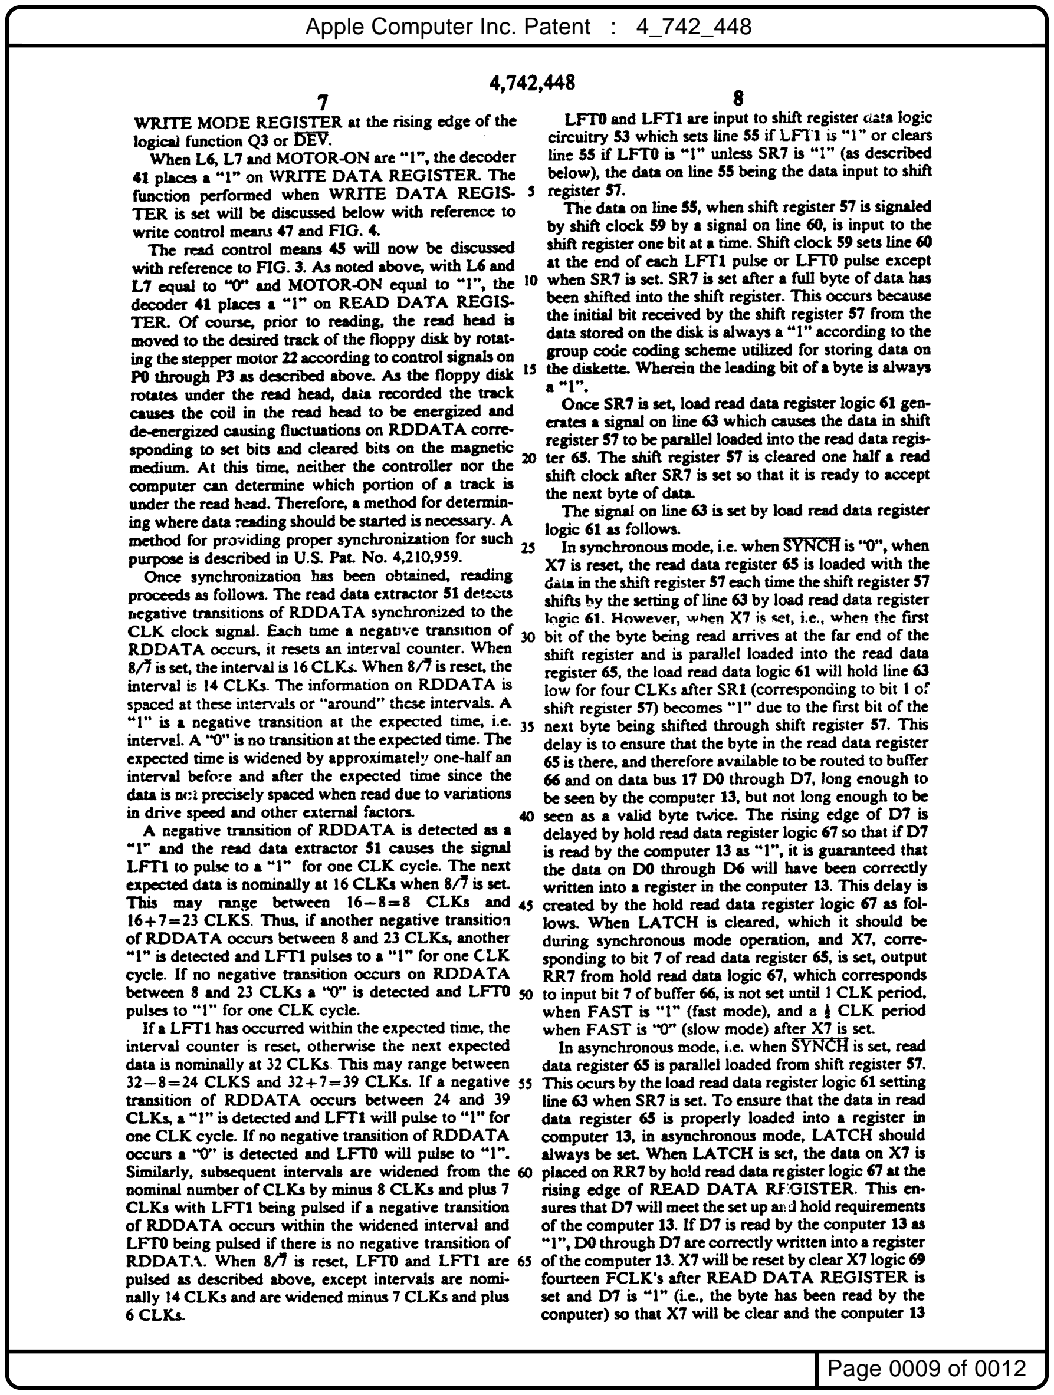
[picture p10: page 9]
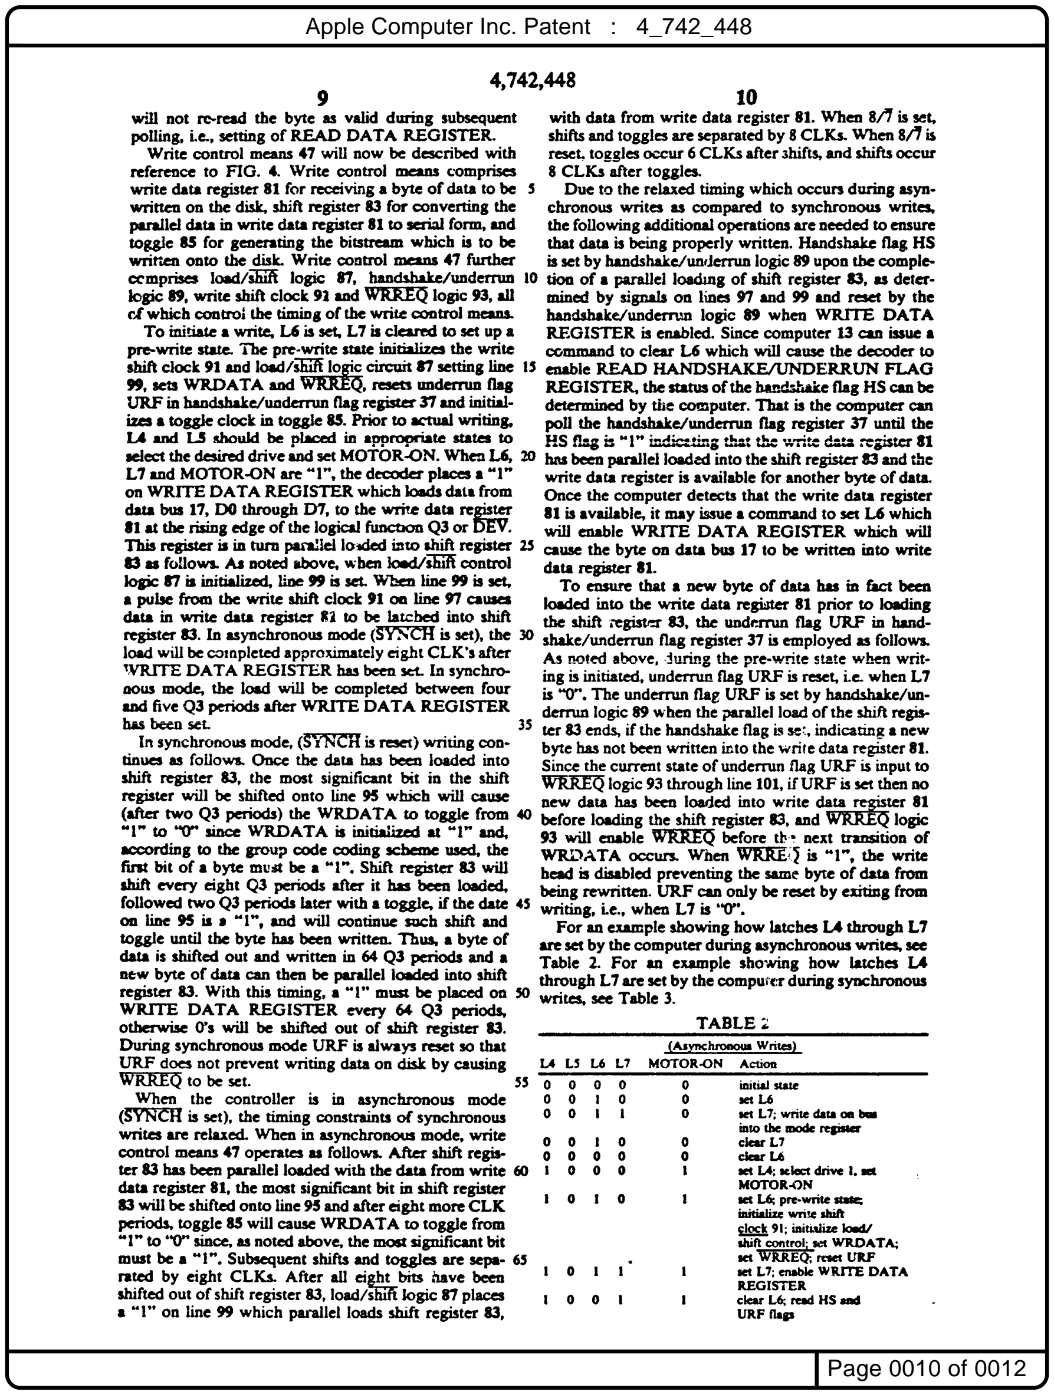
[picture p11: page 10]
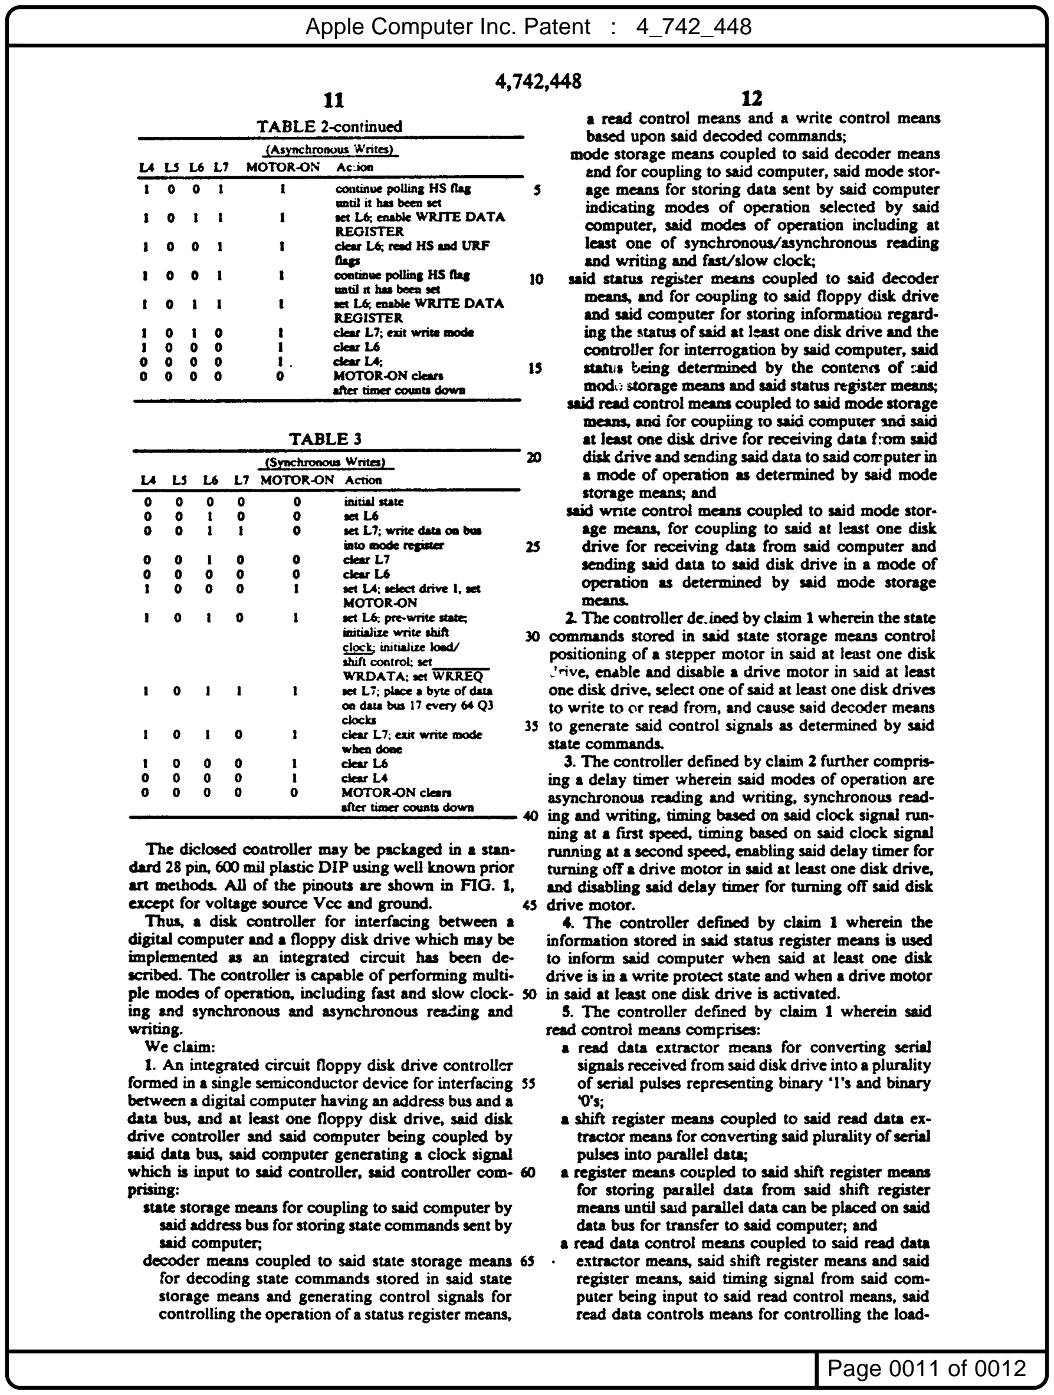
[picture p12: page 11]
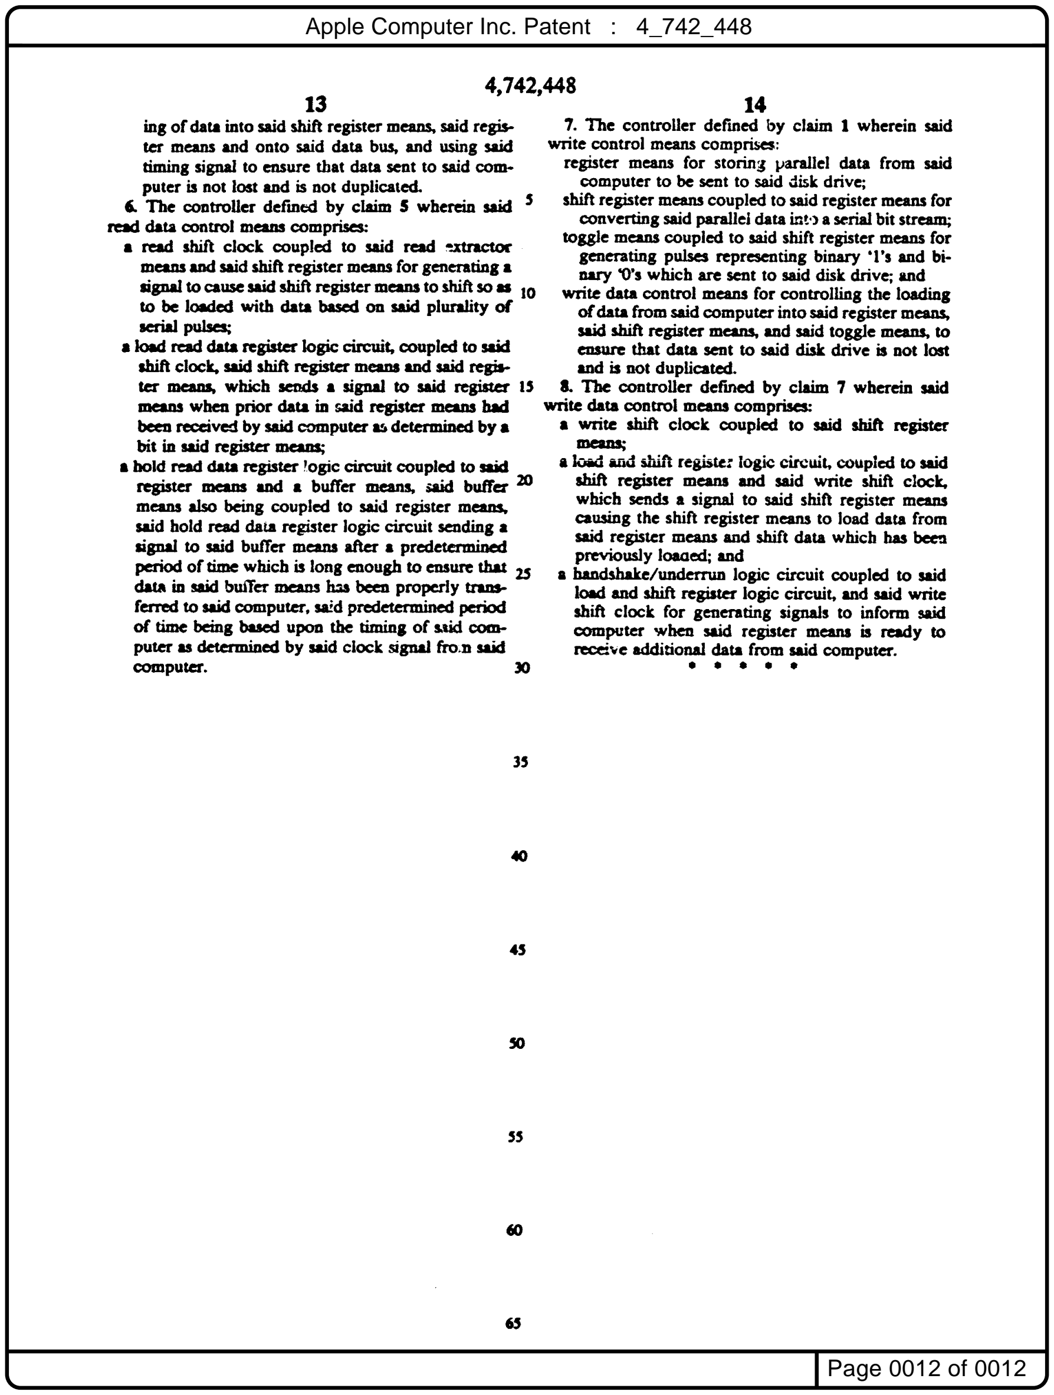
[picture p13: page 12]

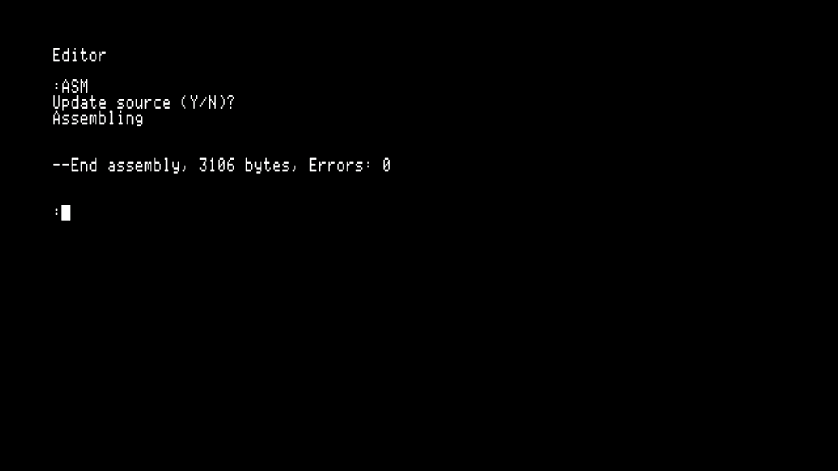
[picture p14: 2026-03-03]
docs/Logic Hamr/Screenshot 2026-02-04 16-24-38.png

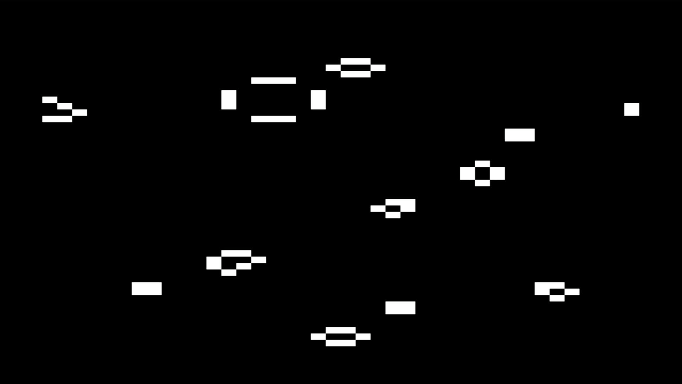
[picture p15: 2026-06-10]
docs/blog/multiverse/soup-oscillators.png

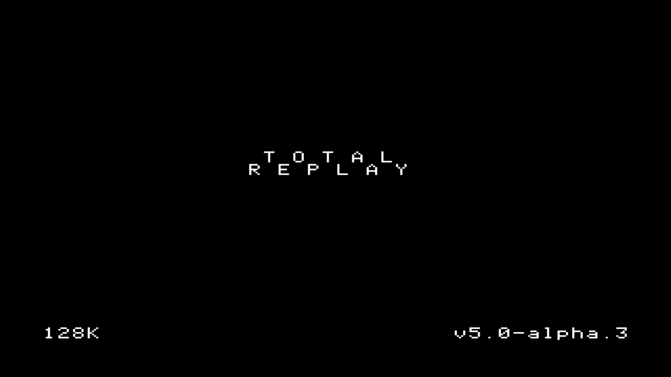
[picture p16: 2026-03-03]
docs/Smart Hamr/Screenshot 2026-03-02 16-49-06.png

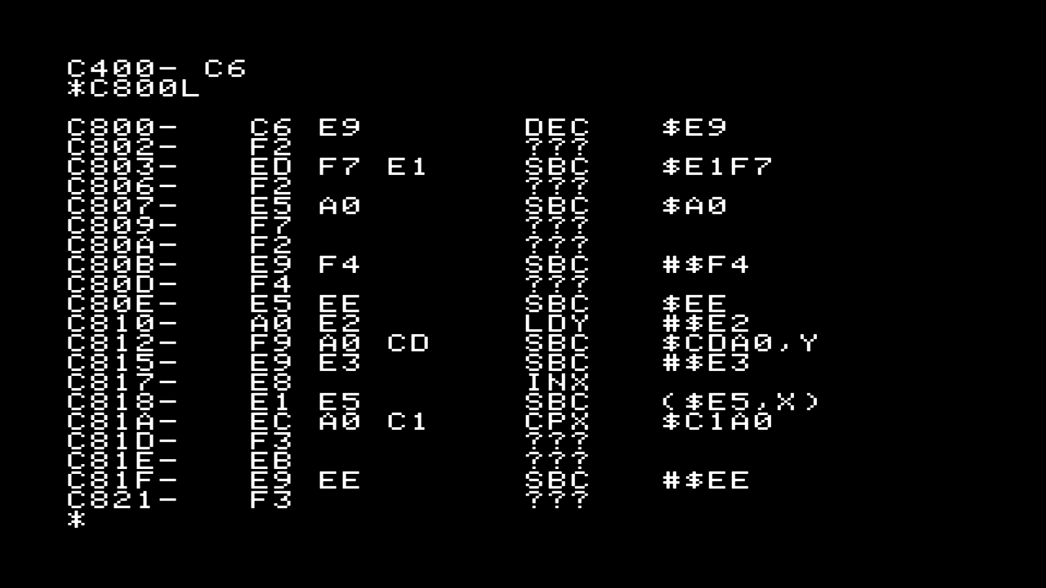
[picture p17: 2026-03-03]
docs/Logic Hamr/Screenshot 2026-02-04 17-32-33.png

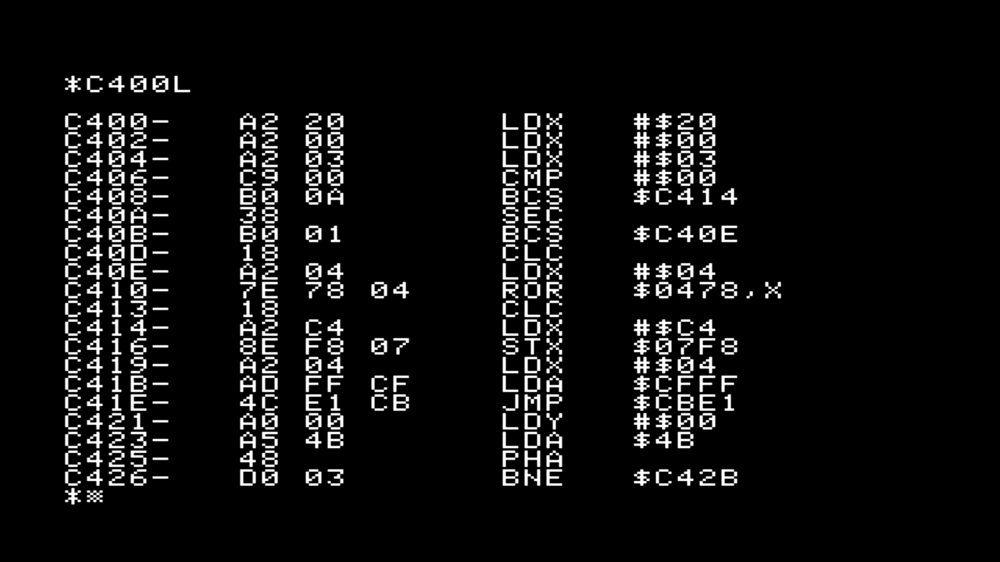
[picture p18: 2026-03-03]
docs/Logic Hamr/Screenshot 2026-02-04 17-45-37.png

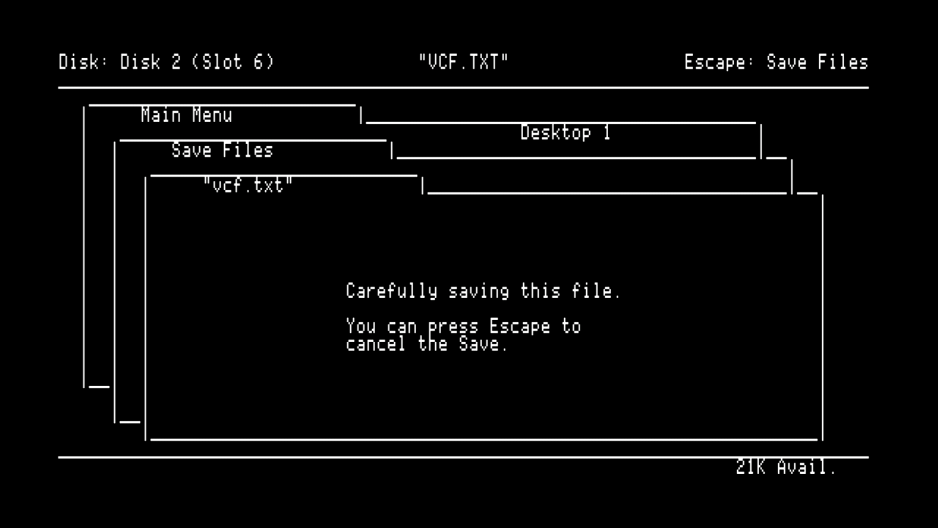
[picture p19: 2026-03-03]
docs/Smart Hamr/Screenshot 2026-03-02 17-00-26.png

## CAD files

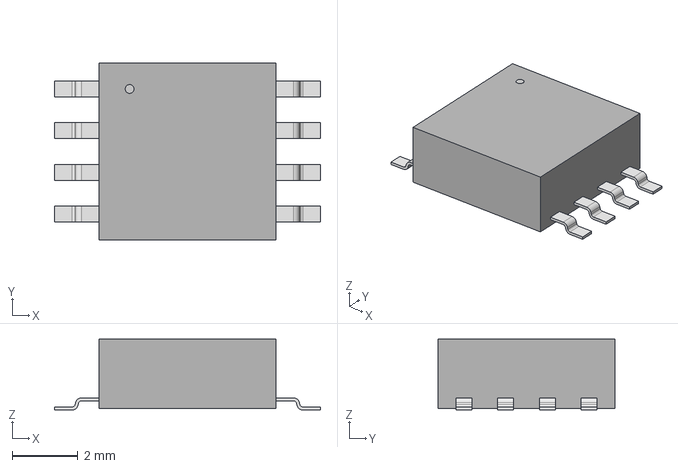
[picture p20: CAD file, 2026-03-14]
hardware/byte_hamr/kicad/3d_models/SOIC8_208MIL_JB_ISI.step
8.10 x 5.38 x 2.16 mm

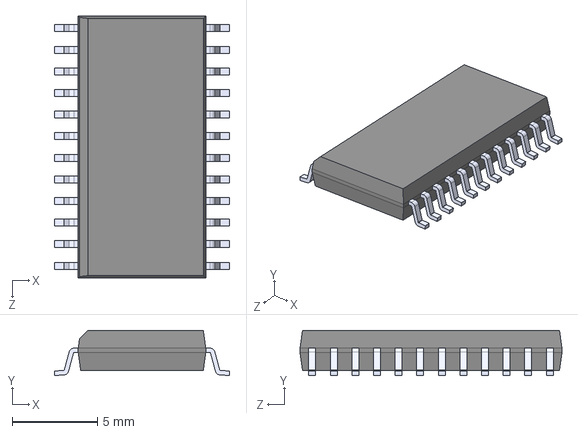
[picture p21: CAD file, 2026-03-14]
hardware/byte_hamr/kicad/footprints/SN74LVC1G04DBVR/SN74LVC8T245DWR.STEP
10.3 x 2.65 x 15.4 mm

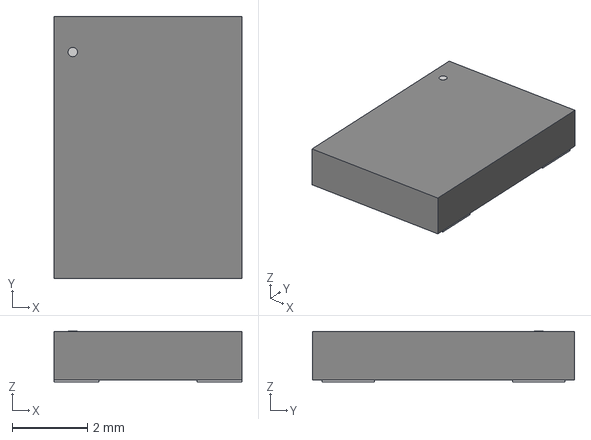
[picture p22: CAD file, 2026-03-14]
hardware/byte_hamr/kicad/3d_models/CWX813-100_0M_CNW.step
5.00 x 6.98 x 1.35 mm

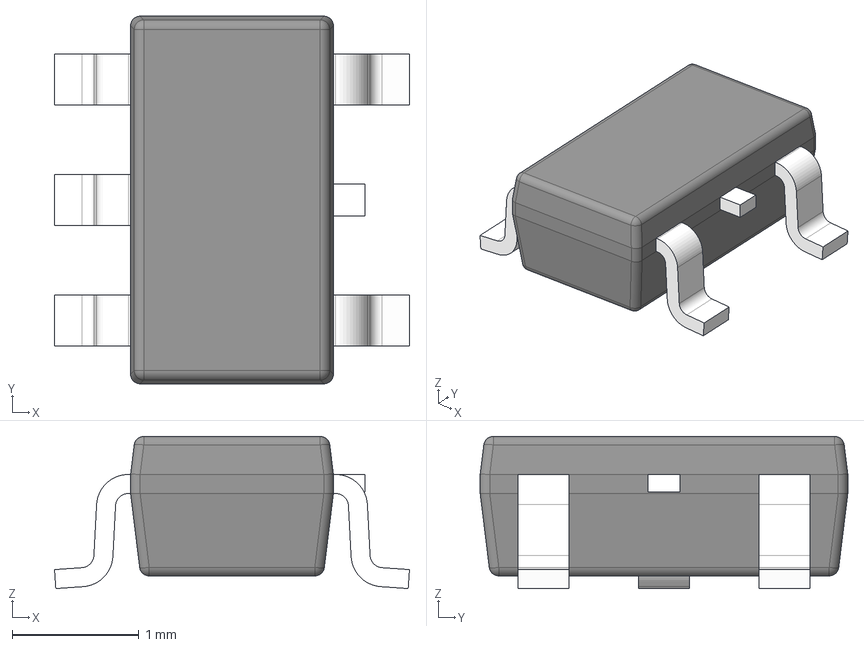
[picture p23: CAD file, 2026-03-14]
hardware/byte_hamr/kicad/3d_models/DBV0005A.stp
2.80 x 2.90 x 1.20 mm
BODY-SOT
LEAD-SOT x 5
LEAD-DUMMY

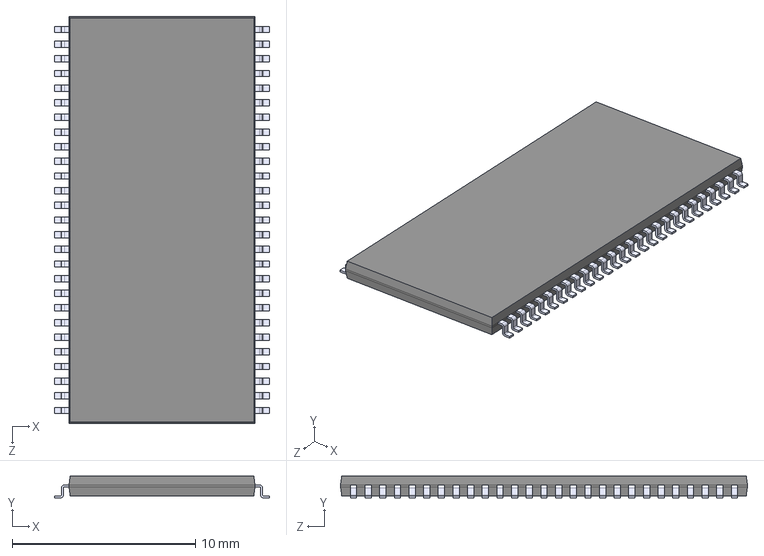
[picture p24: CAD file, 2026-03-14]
hardware/byte_hamr/kicad/3d_models/AS4C32M16SB-7TCNTR.STEP
11.8 x 1.20 x 22.2 mm

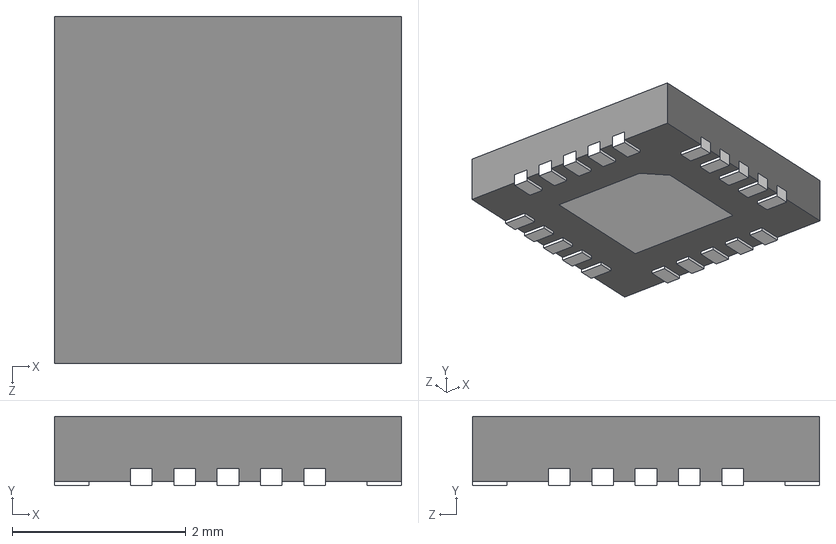
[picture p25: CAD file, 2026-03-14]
hardware/byte_hamr/kicad/3d_models/FT231XQ-R.STEP
4.00 x 0.8 x 4.00 mm

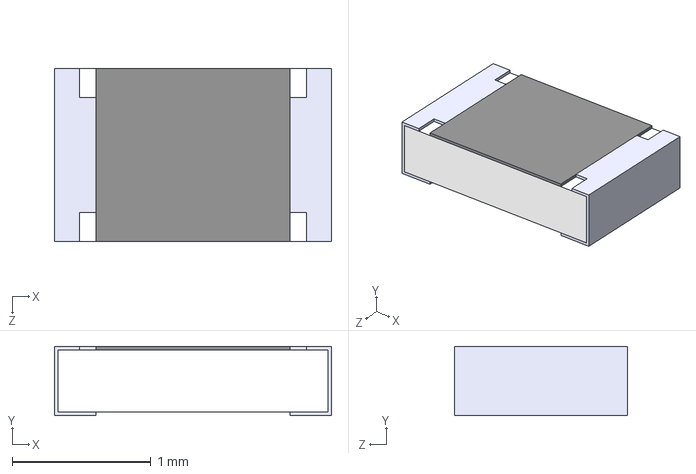
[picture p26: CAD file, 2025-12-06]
docs/RCS08050000Z0EA/RCS08050000Z0EA.step
2.00 x 0.5 x 1.25 mm

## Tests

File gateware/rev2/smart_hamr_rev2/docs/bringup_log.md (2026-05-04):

# Bring-up log — smart_hamr_rev2

Per-phase bench validation history. Each entry: date, design SHA, observed
behavior, pass/fail, notes.

## Phase 0 — scaffolding

### Pass criteria

- Apple II boots, no freeze, no smoke.
- Slot 4 visible to scanning.
- ProDOS does not panic.
- No driver claim acceptable; slot inert is acceptable.

### Bench log

| Date | SHA | Result | Notes |
|---|-----|---|---|
| 2026-05-02 | (uncommitted v1) | RTL written, build clean. Bench validation pending user authorization to flash. | |

## Phase 1 — state registers + register read mux + /ENBL

### Pass criteria

- Liron ROM init runs without crash.
- `_enbl` + phase outputs visibly cycle on FujiNet bench (ESP32 reads
  pattern changes, logs activity).

### Bench log

| Date | SHA | Result | Notes |
|---|-----|---|---|
| 2026-05-02 | (uncommitted v1) | RTL written, build clean. Bench validation pending. | Phase 1 RTL is in same iwm_asic.v as Phase 0 — both gated by single `make`. |

## Phase 2 — write path (TX)

### Pass criteria

- FujiNet receives valid SmartPort command packets.
- Capture confirms PBEGIN $C3, dest, src, type, aux, status, count, data,
  checksum, PEND $C8 byte stream.

### Bench log

| Date | SHA | Result | Notes |
|---|-----|---|---|
| 2026-05-02 | (uncommitted v1) | RTL written: writeShifter, writeBitTimer/Counter, _underrun, _wrreq, buffer load on bus_strobe_rise. Spec-exact constants (writeBitCell = 28 / 32 / 14 / 16). Build clean. Bench validation pending. | Midpoint toggle = writeBitCell>>1 (spec p2). No DRAIN_DELAY hack. |

## Phase 3 — read path (RX)

### Pass criteria

- Apple II runs Liron STATUS command.
- Receives valid status block from FujiNet.
- ProDOS sees mounted SmartPort device.

### Bench log

| Date | SHA | Result | Notes |
|---|-----|---|---|
| 2026-05-02 | (uncommitted v1) | RTL written: 2-FF rddata sample, bitTimer thresholds, latch-mode framing (sync on first $FF, then 8 bits/byte), GCR fallback (MSB=1 latch), x7 with 14-fclk clear timer (patent col 8). Build clean. | No Q6-falling-edge flush, no Q7-rise pre-seed buffer. Spec only. |

## Phase 4 — full ProDOS session

### Pass criteria

- ProDOS catalogs disk image.
- Sequential file load.
- 50+ cold + warm reboot cycles without freeze.

### Bench log

| Date | SHA | Result | Notes |
|---|-----|---|---|
| 2026-05-02 | (uncommitted v1) | v1 RTL = Phases 0-3 superset. Pending flash + bench. v1 target = match prior smart_hamr PR#4 milestone (boots ProDOS from FujiNet). | |
| 2026-05-03 | (uncommitted v1, spec-pure) | **PASS.** Boots ProDOS from FujiNet. Full 10-device SmartPort enumeration (drives 0x81–0x8a). READ_BLOCK / STATUS / CONTROL all work. | Spec-pure RTL: no drain, no Q6-flush, no DRAIN_DELAY. Proves the empirical hacks in prior `smart_hamr` were not load-bearing for Liron protocol. |
| 2026-05-03 | same | False alarm: `data_chksum=1` errors and `Send REQ timeout dest=0x83` traced to **FujiNet ESP32 print-flooding stalling its own ISR window**, not an IWM-emulation bug. Disabled debug printf reduces error rate. | Important lesson: ESP32 serial debug output competes with IWM bit-cell capture for CPU. Always evaluate FujiNet errors against current debug-print level before assuming gateware fault. |

## Phase 5 — second drive + WRITE/FORMAT

Pending.

## Phase 5 — second drive + WRITE/FORMAT

Pending.

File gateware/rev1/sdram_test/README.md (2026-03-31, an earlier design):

# SDRAM Test

Register-driven SDRAM read/write test for the Byte Hamr. Allows Apple II software to directly read and write arbitrary SDRAM addresses through memory-mapped I/O registers, providing full 25-bit linear addressing across the 64MB SDRAM.

## What It Does

Exposes the onboard SDRAM to the Apple II CPU through a register interface at `$C0C0-$C0CF`. The CPU stages an address and data value in registers, issues a read or write command, polls for completion, then reads the result. Supports full 16-bit SDRAM data width.

The design handles SDRAM initialization automatically on power-up (precharge, refresh, mode register load) and runs periodic refresh in the background.

## Register Map

Base address: `$C0C0` (slot 4)

| Offset | Name | R/W | Description |
|---|---|-----|---|
| `$00` | ADDR_LO | R/W | Address bits [7:0] |
| `$01` | ADDR_MID | R/W | Address bits [15:8] |
| `$02` | ADDR_HI | R/W | Address bits [24:16] (7 bits) |
| `$03` | DATA_LO | R/W | Write data / read result [7:0] |
| `$04` | DATA_HI | R/W | Write data / read result [15:8] |
| `$05` | CMD | W | `$01` = Write, `$02` = Read |
| `$06` | STATUS | R | `[0]` busy, `[1]` init_done, `[2]` last cmd type |
| `$07-$0F` | SCRATCH | R/W | 9 general-purpose loopback registers |

### Address Decomposition

The 25-bit linear address maps to SDRAM signals:
- Column[9:0] = `{ADDR_MID[1:0], ADDR_LO[7:0]}`
- Row[12:0] = `{ADDR_HI[4:0], ADDR_MID[7:2]}`
- Bank[1:0] = `ADDR_HI[6:5]`

## Usage from Apple II

```
; Write $BEEF to SDRAM address $000000
LDA #$00 : STA $C0C0    ; ADDR_LO
LDA #$00 : STA $C0C1    ; ADDR_MID
LDA #$00 : STA $C0C2    ; ADDR_HI
LDA #$EF : STA $C0C3    ; DATA_LO
LDA #$BE : STA $C0C4    ; DATA_HI
LDA #$01 : STA $C0C5    ; CMD = WRITE
:wait BIT $C0C6 : BNE :wait  ; Poll busy

; Read it back
LDA #$02 : STA $C0C5    ; CMD = READ
:wait2 BIT $C0C6 : BNE :wait2
LDA $C0C3               ; DATA_LO = $EF
LDA $C0C4               ; DATA_HI = $BE
```

## GPIO Debug Outputs

| GPIO | Signal |
|---|---|
| GPIO1 | Heartbeat (250 kHz) |
| GPIO2 | SDRAM init done |
| GPIO3 | I/O select activity |
| GPIO4 | SDRAM busy |
| GPIO5 | R/nW debug |
| GPIO8-12 | Walking 1s pattern (0.5s) |

## Makefile Commands

All commands run from the project root (`project_byte_hamr/`).

```bash
# Build
make DESIGN=sdram_test         # Build complete bitstream
make DESIGN=sdram_test synth   # Synthesis only
make DESIGN=sdram_test pnr     # Place & route only
make DESIGN=sdram_test bit     # Generate bitstream

# Program
make DESIGN=sdram_test prog        # JTAG (volatile)
make DESIGN=sdram_test prog-flash  # SPI flash (persistent)

# Simulate
make DESIGN=sdram_test sim         # Run testbench
make DESIGN=sdram_test wave        # Simulation + GTKWave

# Reports
make DESIGN=sdram_test report      # View build summary
make clean                         # Remove build artifacts
```

## Files

| File | Description |
|---|---|
| `sdram_test_top.v` | Top module - register file, SDRAM state machine, bus interface |
| `sdram_test_tb.v` | Testbench - SDRAM model, bus transactions, multi-address verification |

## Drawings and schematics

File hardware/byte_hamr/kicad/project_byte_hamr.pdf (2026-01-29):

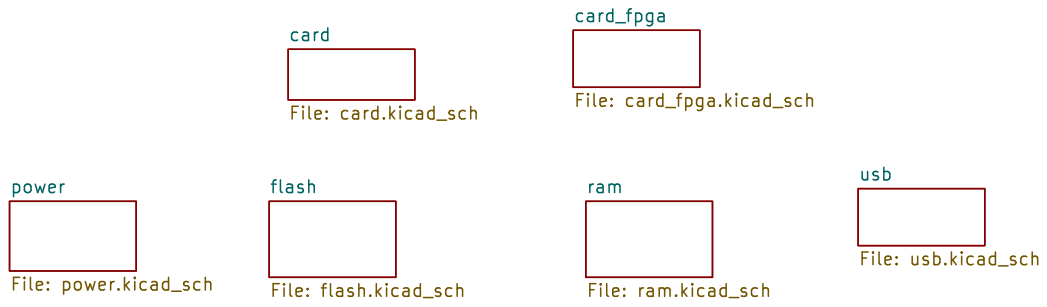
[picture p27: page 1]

Id: 1/7 Title: Byte Hamr - Apple II FPGA Peripheral Card

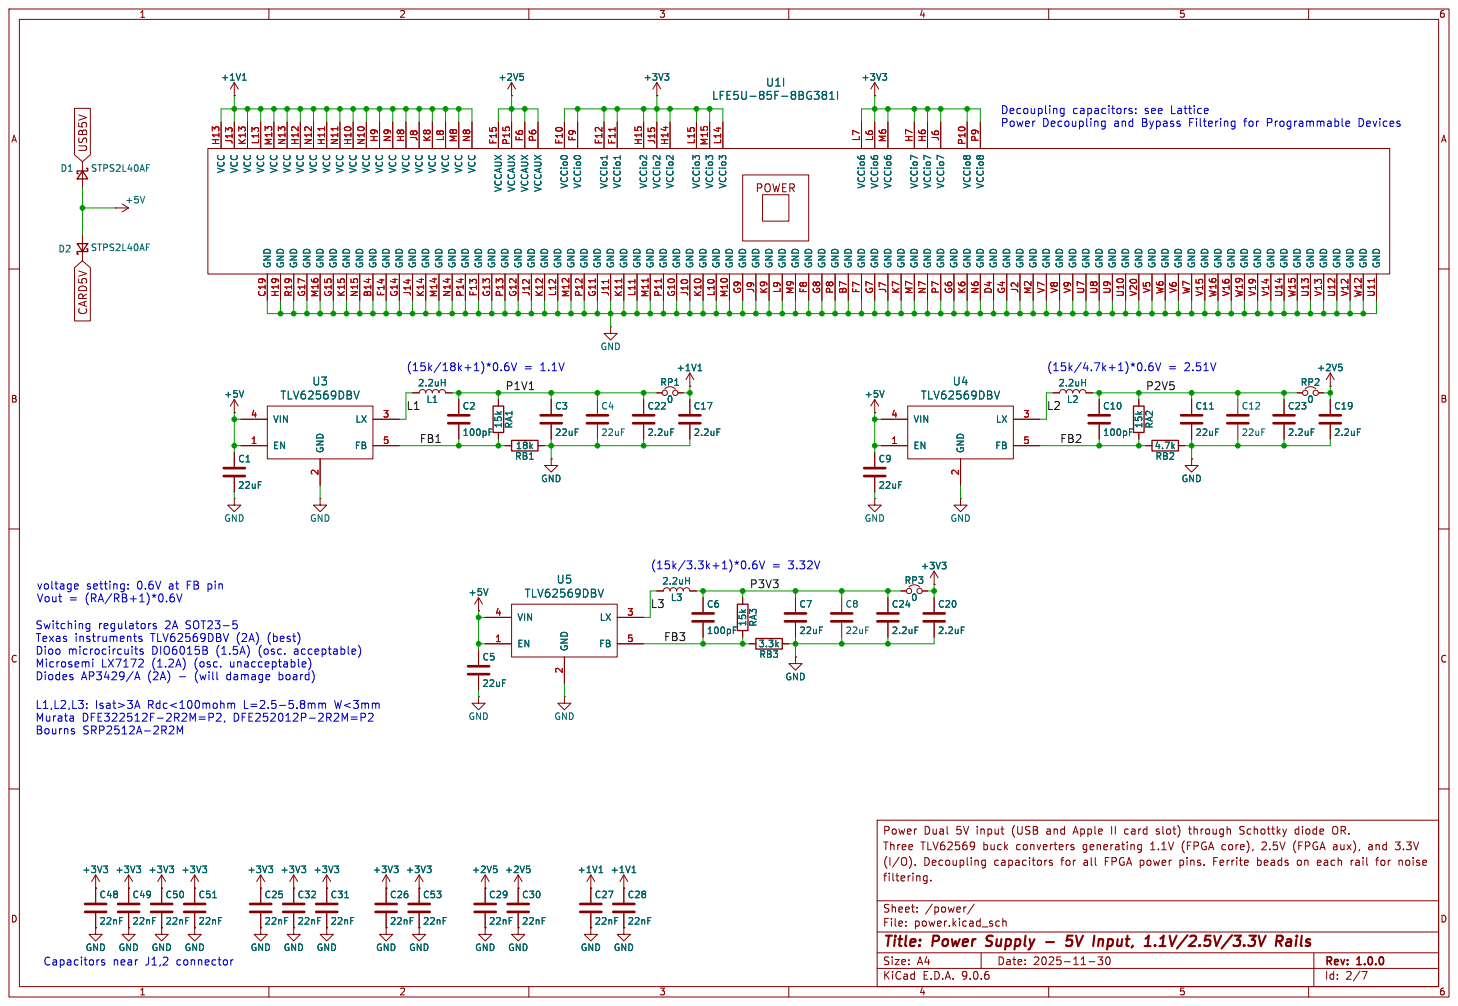
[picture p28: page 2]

voltage setting: 0.6V at FB pin Vout = (RA/RB+1)*0.6V

File: power.kicad_sch Sheet: /power/

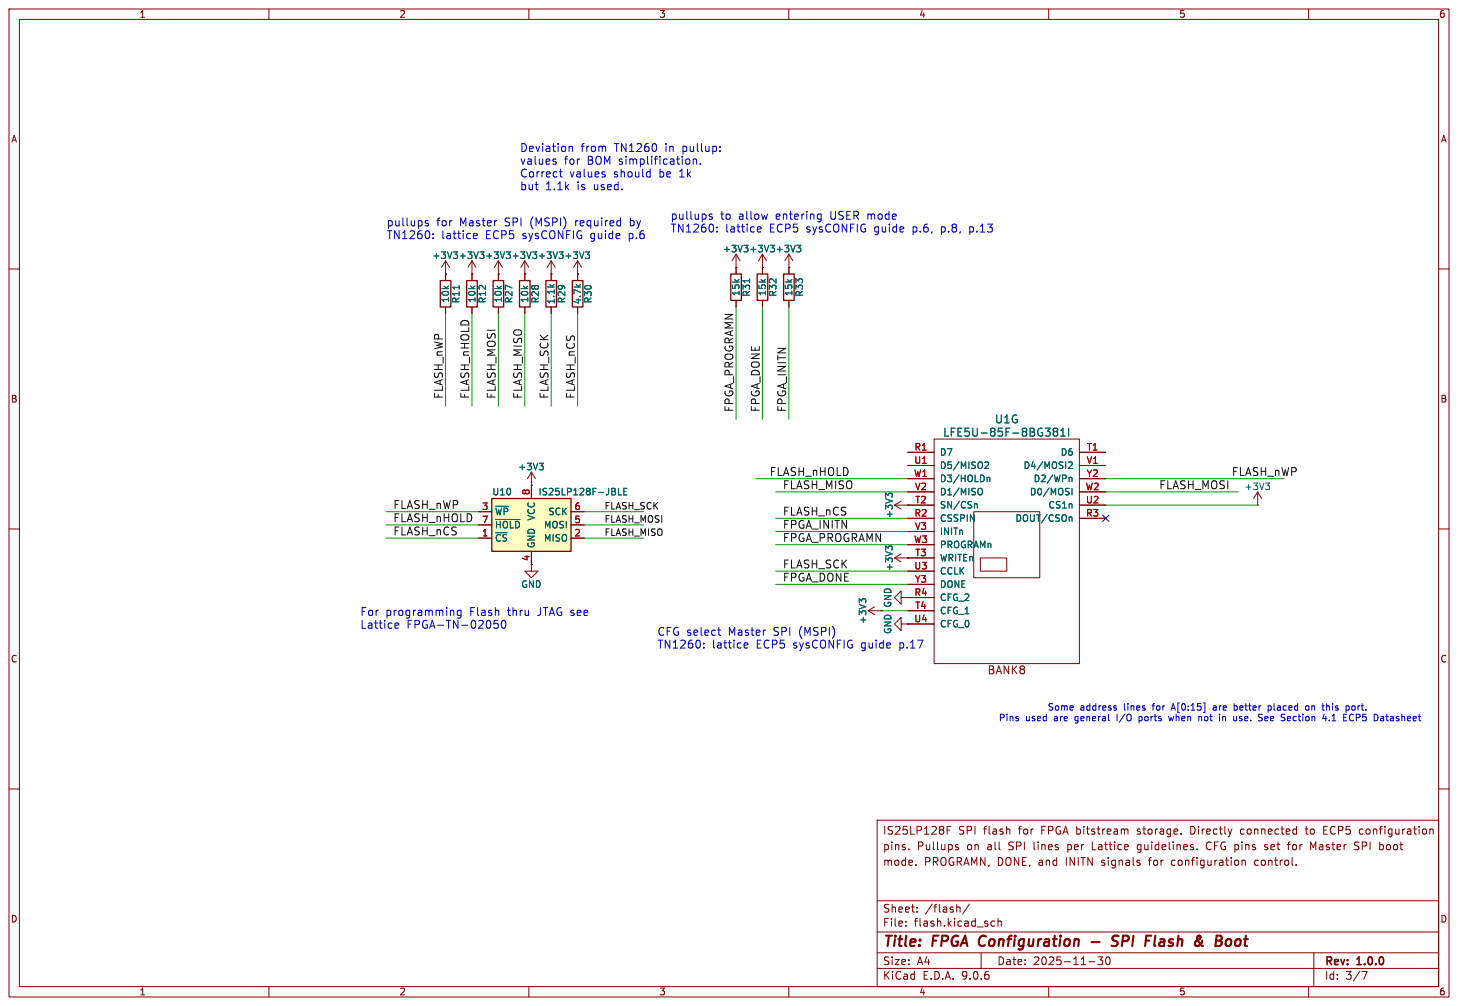
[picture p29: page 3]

FPGA_DONE Deviation from TN1260 in pullup: values for BOM simplification.

4 SCK 6 MOSI 5 MISO 2 U10 IS25LP128F-JBLE

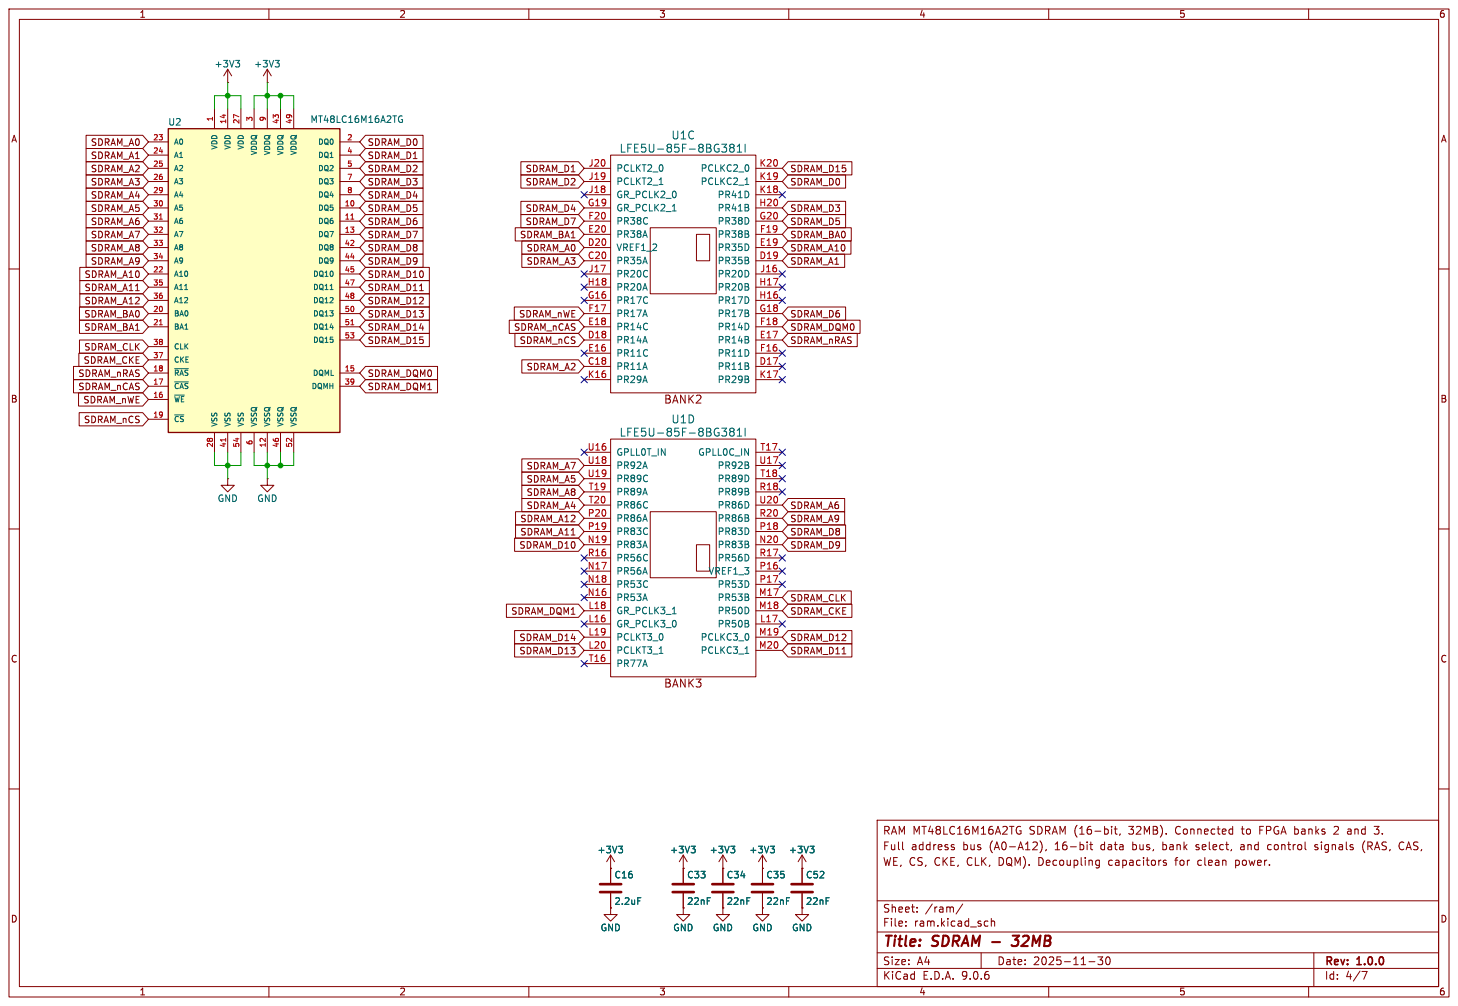
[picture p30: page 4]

9 VSSQ 12 VDDQ 43 VSSQ 46 VDDQ 49 VSSQ 52 DQ0 2 DQ1 4 DQ2 5 DQ3 7 DQ4 8 DQ5 10 DQ6 11 DQ7 13 DQ8 42 DQ9 44 DQ10 45 DQ11 47 DQ12 48 DQ13 50 DQ14 51 DQ15 53 DQML 15 DQMH 39 U2 MT48LC16M16A2TG

1 VSS 28 VDD 14 VSS 41 VDD 27 VSS 54 VDDQ

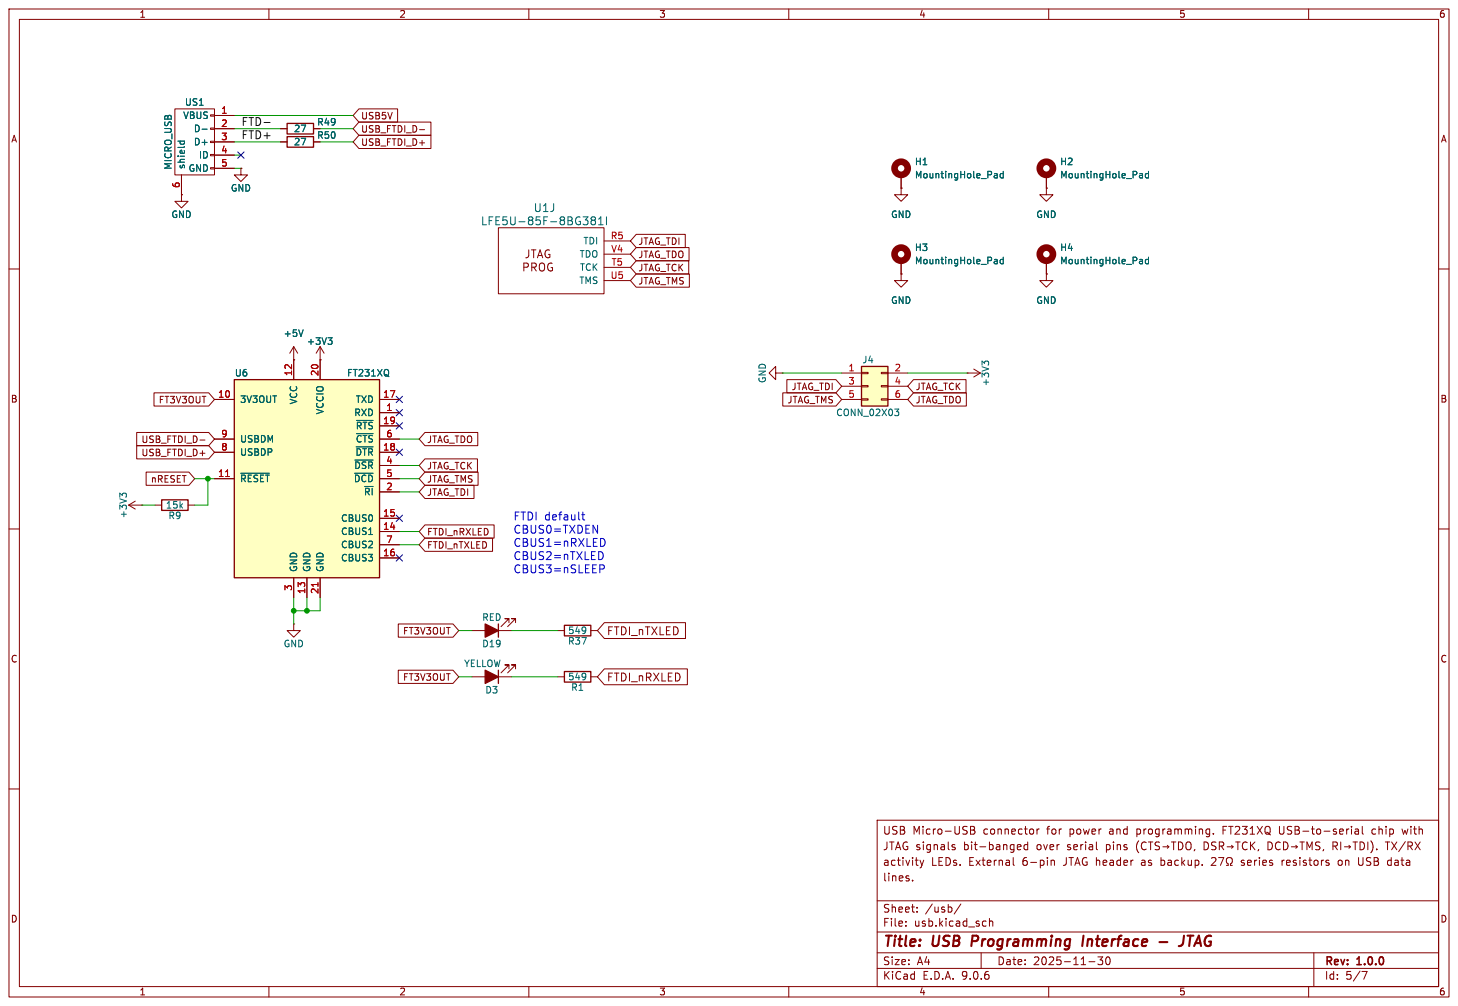
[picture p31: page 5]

3 GND 13 VCCIO 20 GND 21 TXD 17 RXD 1 ~{RTS}19 ~{CTS}6 ~{DTR}18 ~{DSR}4 ~{DCD}5 ~{RI} 2 CBUS0 15 CBUS1 14 CBUS2 7 CBUS3 16 +5V

3 GND 13 VCCIO 20 GND 21 TXD 17 RXD 1 ~{RTS}19 ~{CTS}6 ~{DTR}18 ~{DSR}4 ~{DCD}5 ~{RI} 2 CBUS0 15 CBUS1 14 CBUS2 7 CBUS3 16 U6 FT231XQ

File: usb.kicad_sch Sheet: /usb/
Id: 5/7 Title: USB Programming Interface - JTAG

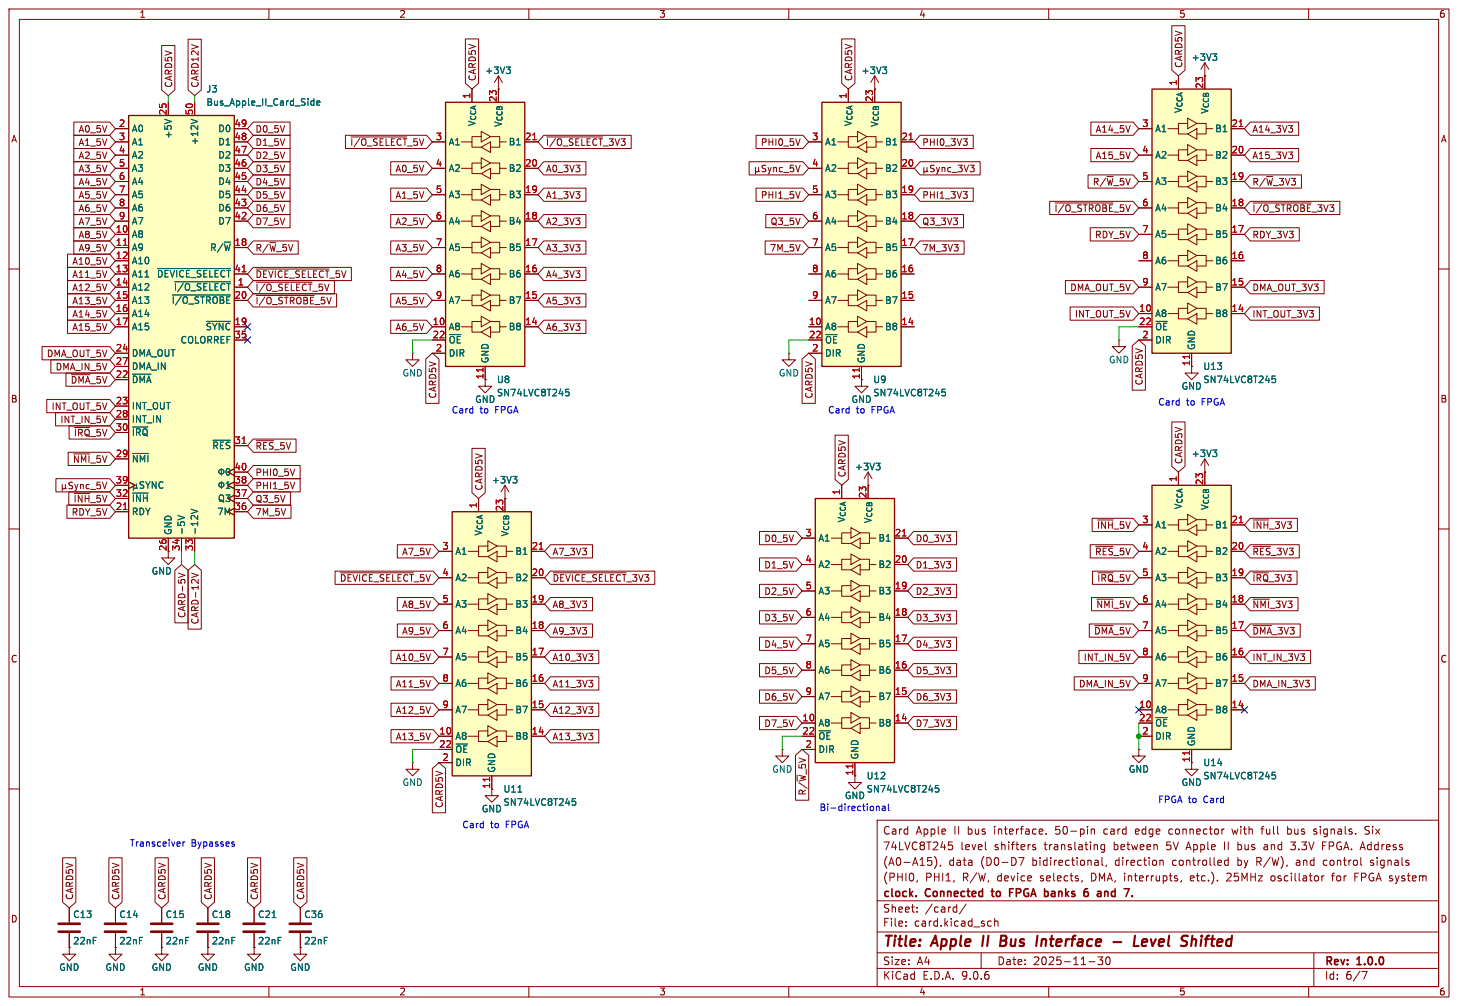
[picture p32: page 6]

Bi-directional Card to FPGA

Id: 6/7 Title: Apple II Bus Interface - Level Shifted

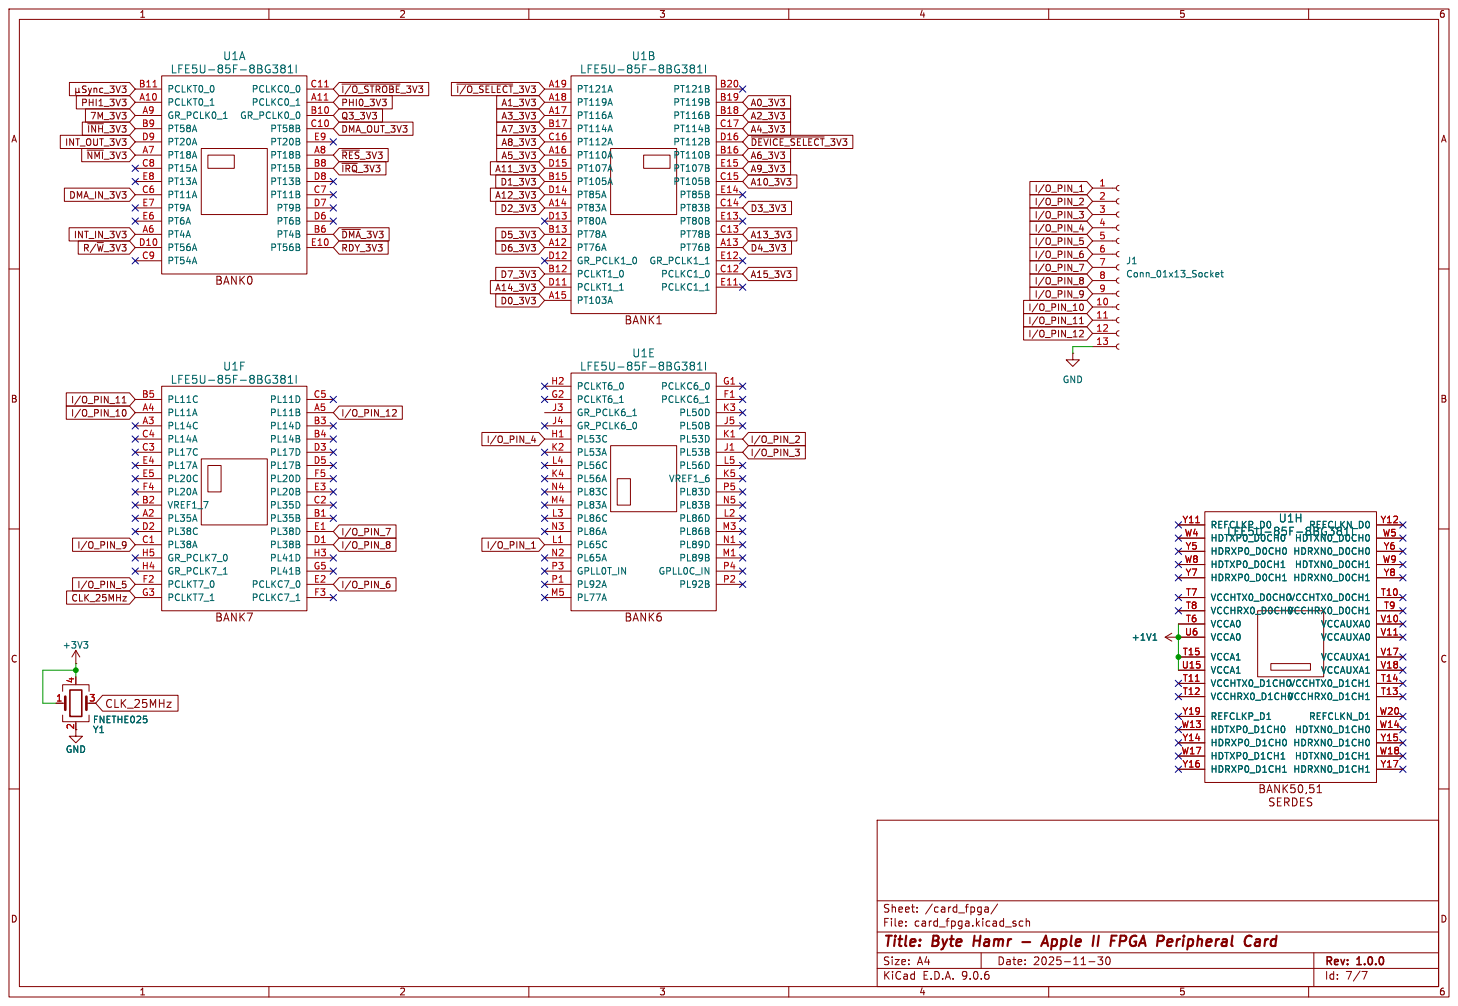
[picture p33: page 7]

File: card_fpga.kicad_sch Sheet: /card_fpga/
Id: 7/7 Title: Byte Hamr - Apple II FPGA Peripheral Card

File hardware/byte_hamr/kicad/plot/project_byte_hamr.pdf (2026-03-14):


Id: 1/7 Title: Byte Hamr - Apple II FPGA Peripheral Card

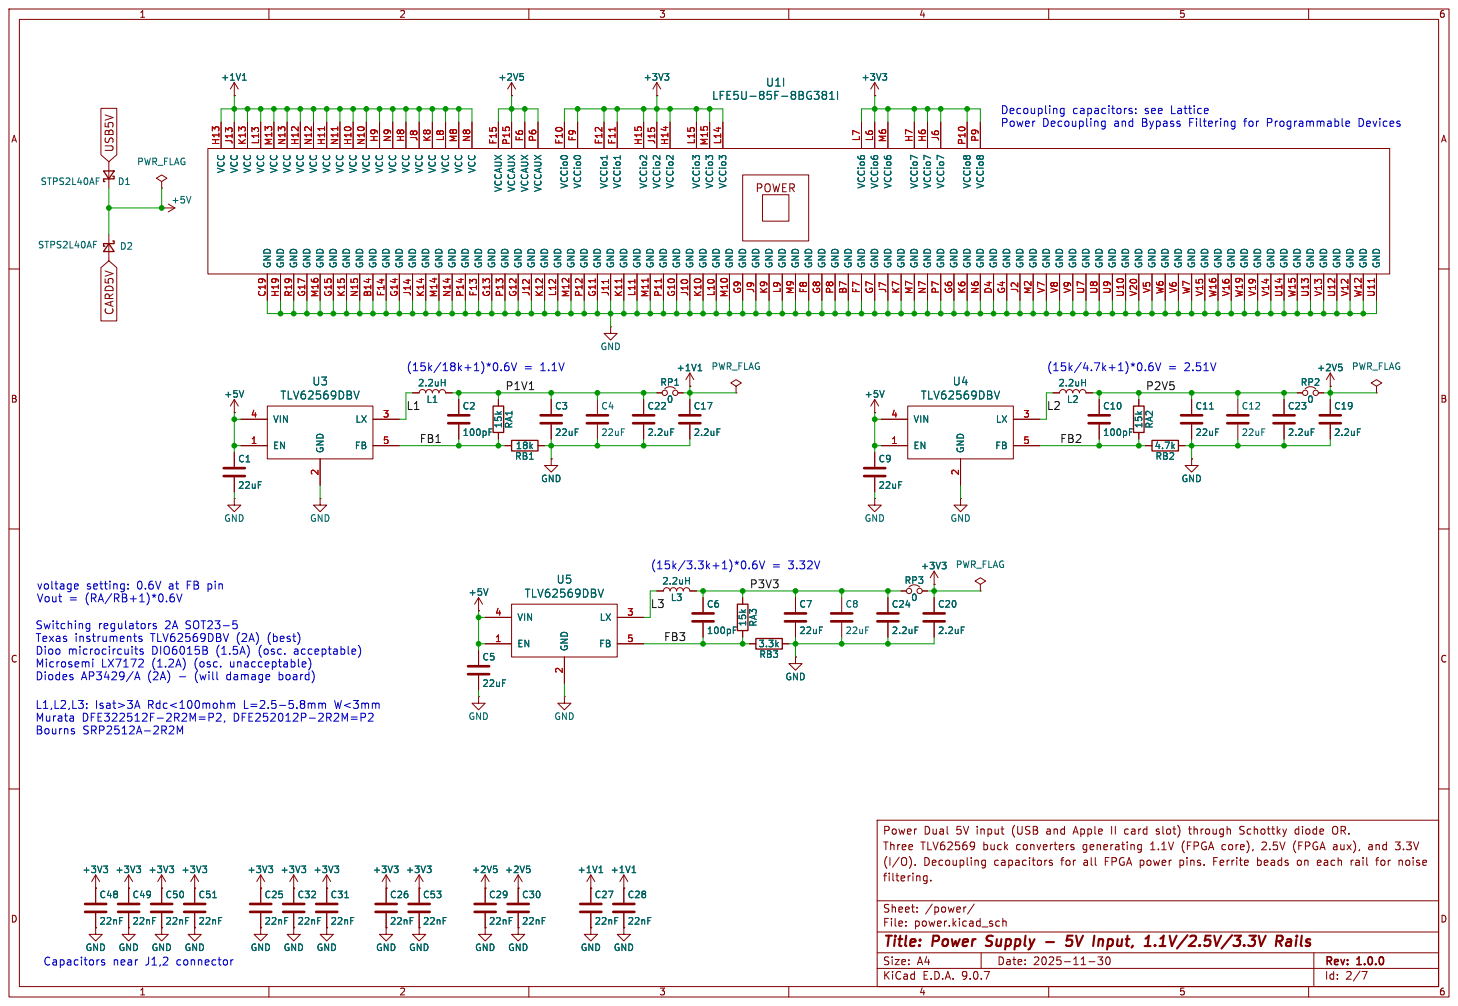
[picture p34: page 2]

voltage setting: 0.6V at FB pin Vout = (RA/RB+1)*0.6V

File: power.kicad_sch Sheet: /power/

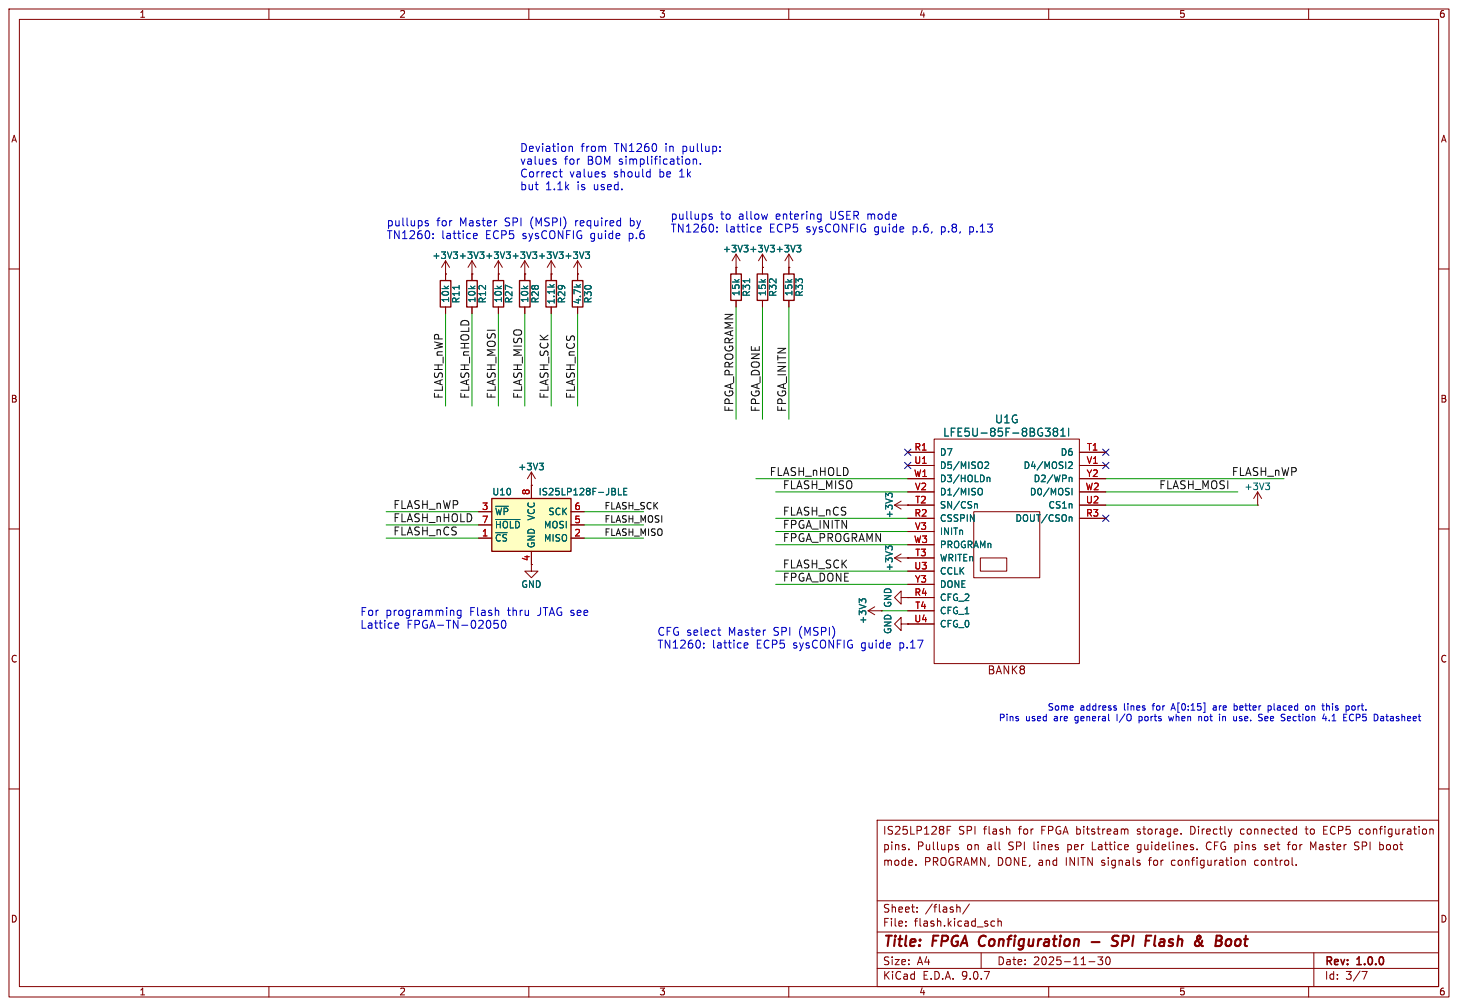
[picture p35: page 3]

4 SCK 6 MOSI 5 MISO 2 U10 IS25LP128F-JBLE

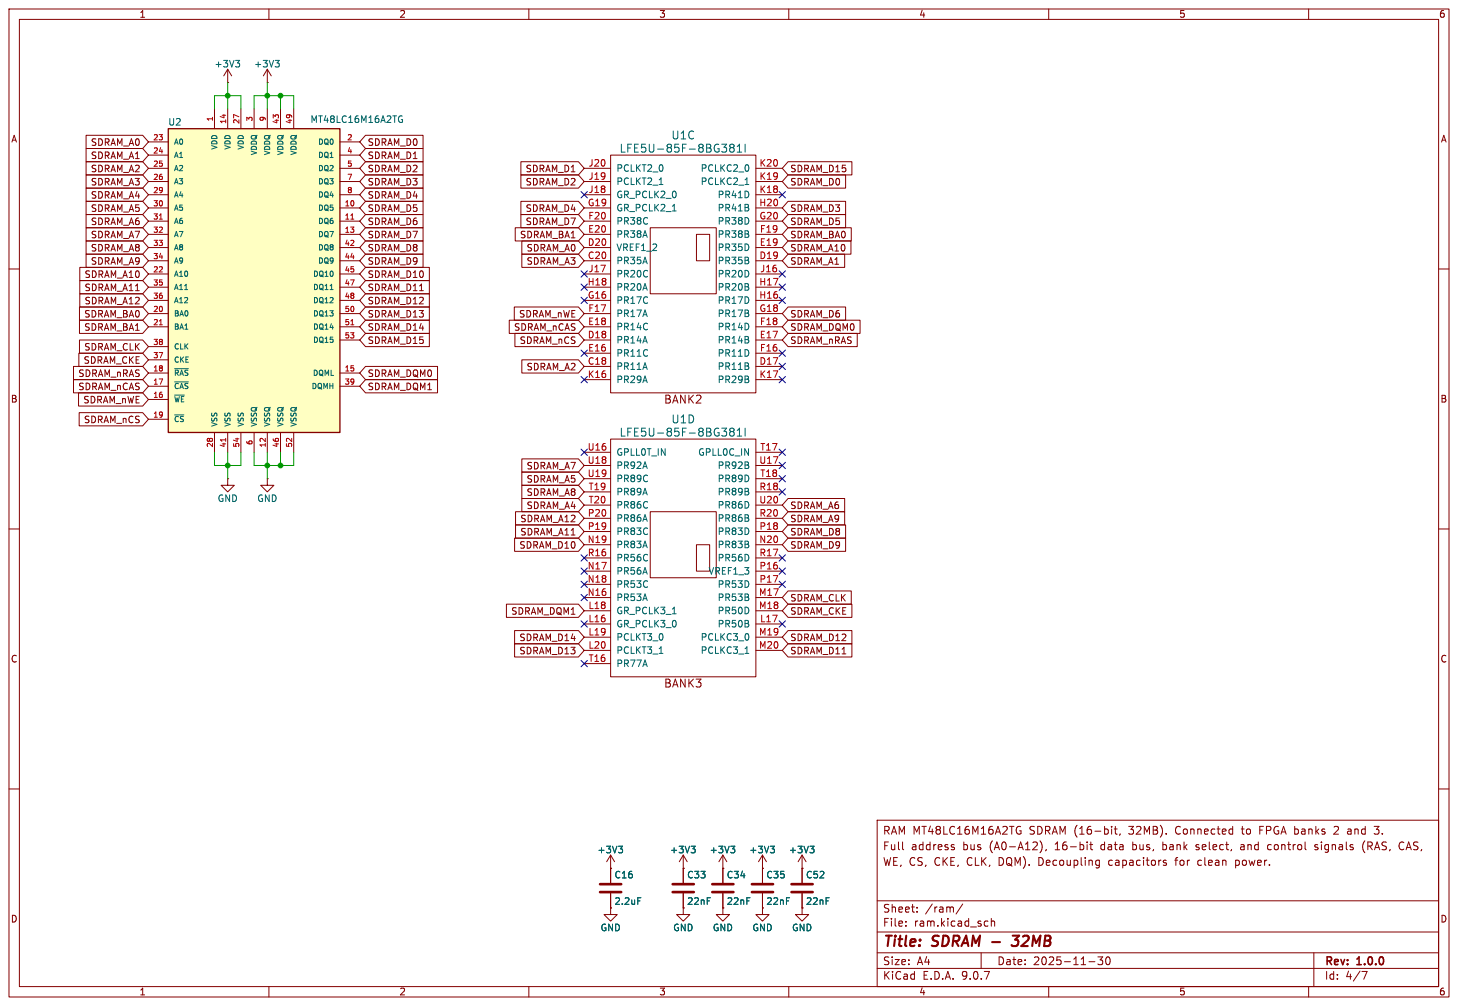
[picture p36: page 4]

9 VSSQ 12 VDDQ 43 VSSQ 46 VDDQ 49 VSSQ 52 DQ0 2 DQ1 4 DQ2 5 DQ3 7 DQ4 8 DQ5 10 DQ6 11 DQ7 13 DQ8 42 DQ9 44 DQ10 45 DQ11 47 DQ12 48 DQ13 50 DQ14 51 DQ15 53 DQML 15 DQMH 39 U2 MT48LC16M16A2TG

1 VSS 28 VDD 14 VSS 41 VDD 27 VSS 54 VDDQ

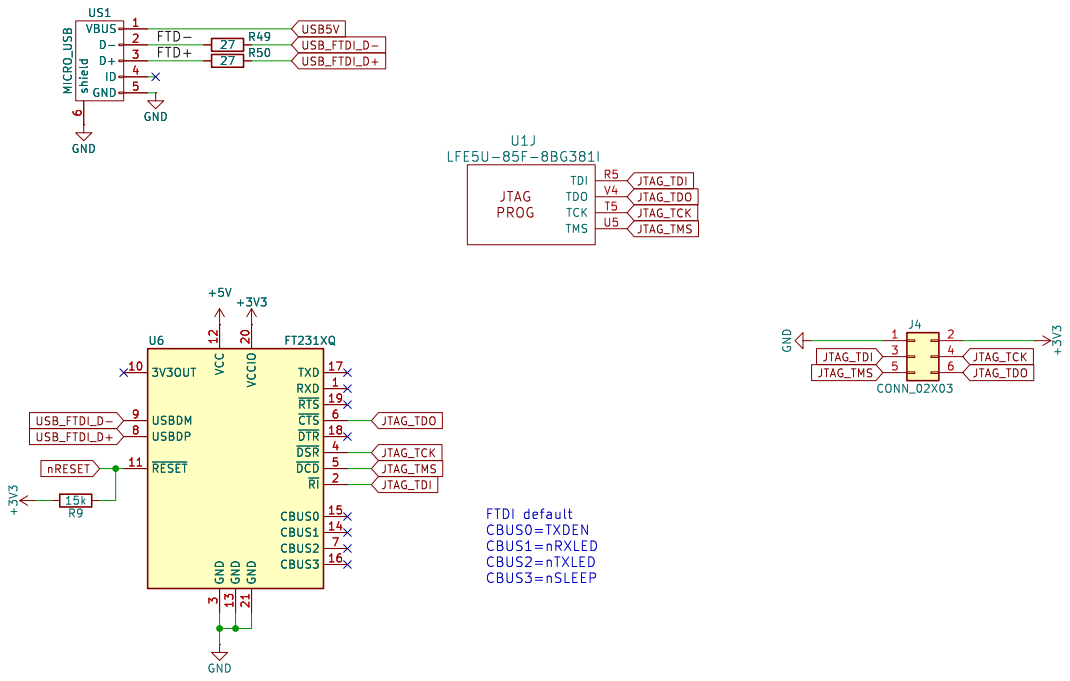
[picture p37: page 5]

3 GND 13 VCCIO 20 GND 21 TXD 17 RXD 1 ~{RTS}19 ~{CTS}6 ~{DTR}18 ~{DSR}4 ~{DCD}5 ~{RI}2 CBUS0 15 CBUS1 14 CBUS2 7 CBUS3 16 +5V R49

3 GND 13 VCCIO 20 GND 21 TXD 17 RXD 1 ~{RTS}19 ~{CTS}6 ~{DTR}18 ~{DSR}4 ~{DCD}5 ~{RI}2 CBUS0 15 CBUS1 14 CBUS2 7 CBUS3 16 U6 FT231XQ

File: usb.kicad_sch Sheet: /usb/
Id: 5/7 Title: USB Programming Interface - JTAG

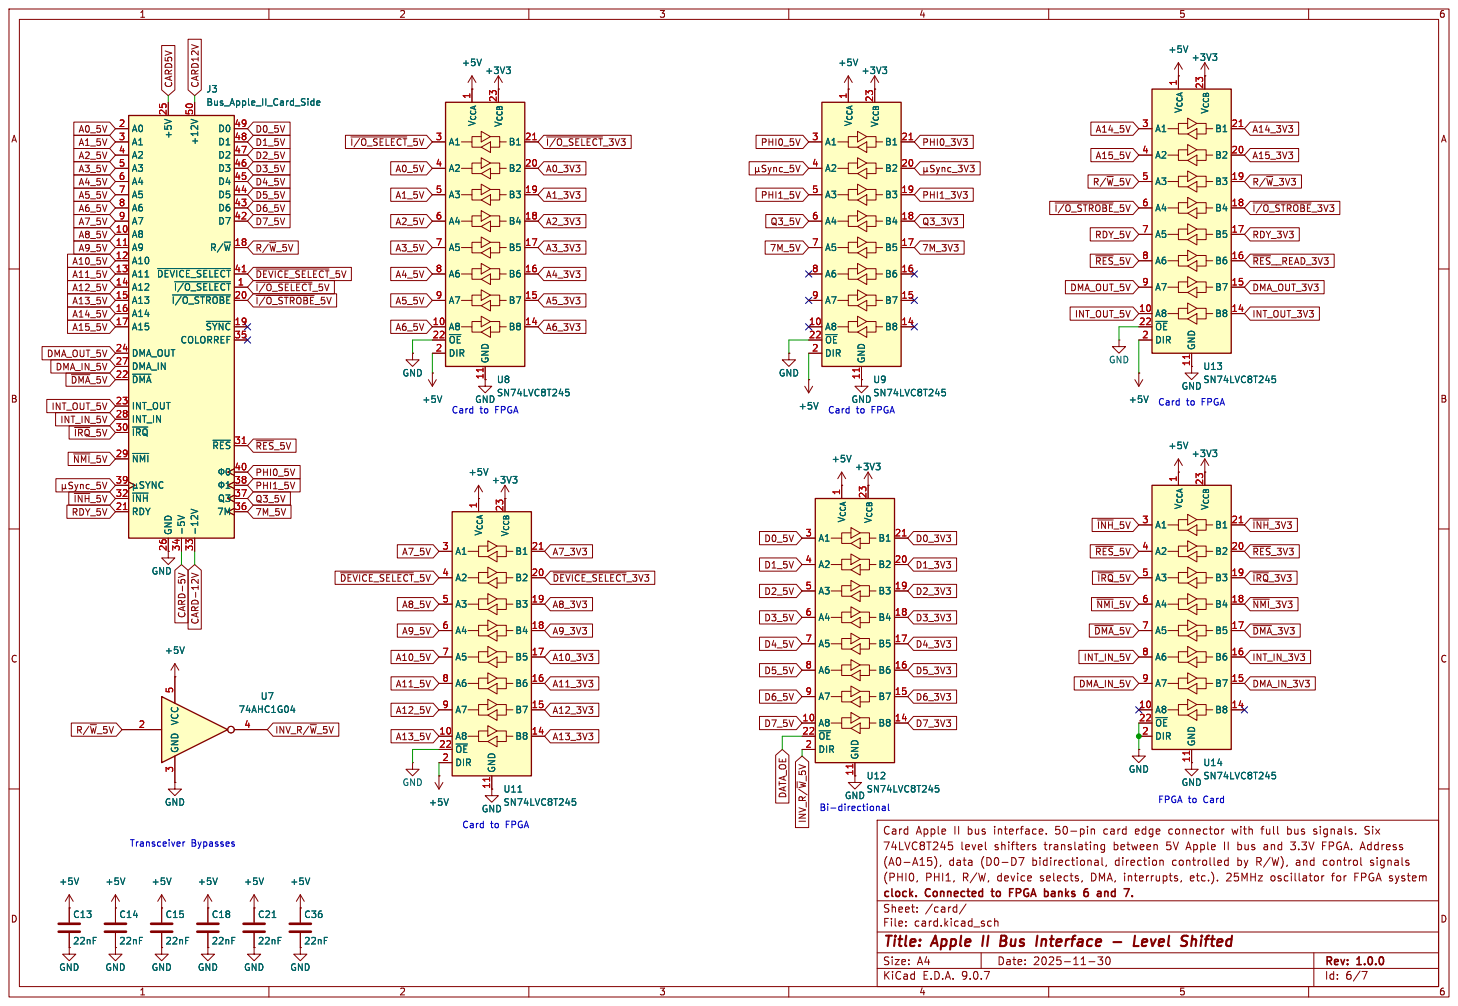
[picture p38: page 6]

Id: 6/7 Title: Apple II Bus Interface - Level Shifted


File: card_fpga.kicad_sch Sheet: /card_fpga/
Id: 7/7 Title: Byte Hamr - Apple II FPGA Peripheral Card

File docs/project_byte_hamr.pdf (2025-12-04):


File: project_byte_hamr.kicad_sch Sheet: / power File: power.kicad_sch

Id: 1/6 Title: Byte Hamr - Apple II FPGA Peripheral Card


voltage setting: 0.6V at FB pin Vout = (RA/RB+1)*0.6V

File: power.kicad_sch Sheet: /power/


FLASH_SCK Deviation from TN1260 in pullup: values for BOM simplification.

4 SCK 6 MOSI 5 MISO 2 +3V3 1.1k R29 4.7k R30 +3V3 +3V3 10k R11 10k R12 10k R27 10k R28 GND

4 SCK 6 MOSI 5 MISO 2 U10 IS25LP128F-JBLE



3 GND 13 VCCIO 20 GND 21 TXD 17 RXD 1 ~{RTS}19 ~{CTS}6 ~{DTR}18 ~{DSR}4 ~{DCD}5 ~{RI} 2 CBUS0 15 CBUS1 14 CBUS2 7 CBUS3 16 U6 FT231XQ +3V3 USB_FTDI_D- USB5V

3 GND 13 VCCIO 20 GND 21 TXD 17 RXD 1 ~{RTS}19 ~{CTS}6 ~{DTR}18 ~{DSR}4 ~{DCD}5 ~{RI} 2 CBUS0 15 CBUS1 14 CBUS2 7 CBUS3 16 +3V3R50

File: usb.kicad_sch Sheet: /usb/
Id: 5/6 Title: USB Programming Interface - JTAG


Id: 6/6 Title: Apple II Bus Interface - Level Shifted

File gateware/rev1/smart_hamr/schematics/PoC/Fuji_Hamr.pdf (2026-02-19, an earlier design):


Id: 1/1 Title: File: Fuji_Hamr.kicad_sch Sheet: / GND ESP32-DevKitC 5V 19 GND 14 CHIP_PU 2

Noise Filter Caps U2ESP32-DevKitC 5V 19 GND 14 CHIP_PU 2

1 GND
22pF MISO 3 MOSI 4 CS 6 SCK 5 VCC

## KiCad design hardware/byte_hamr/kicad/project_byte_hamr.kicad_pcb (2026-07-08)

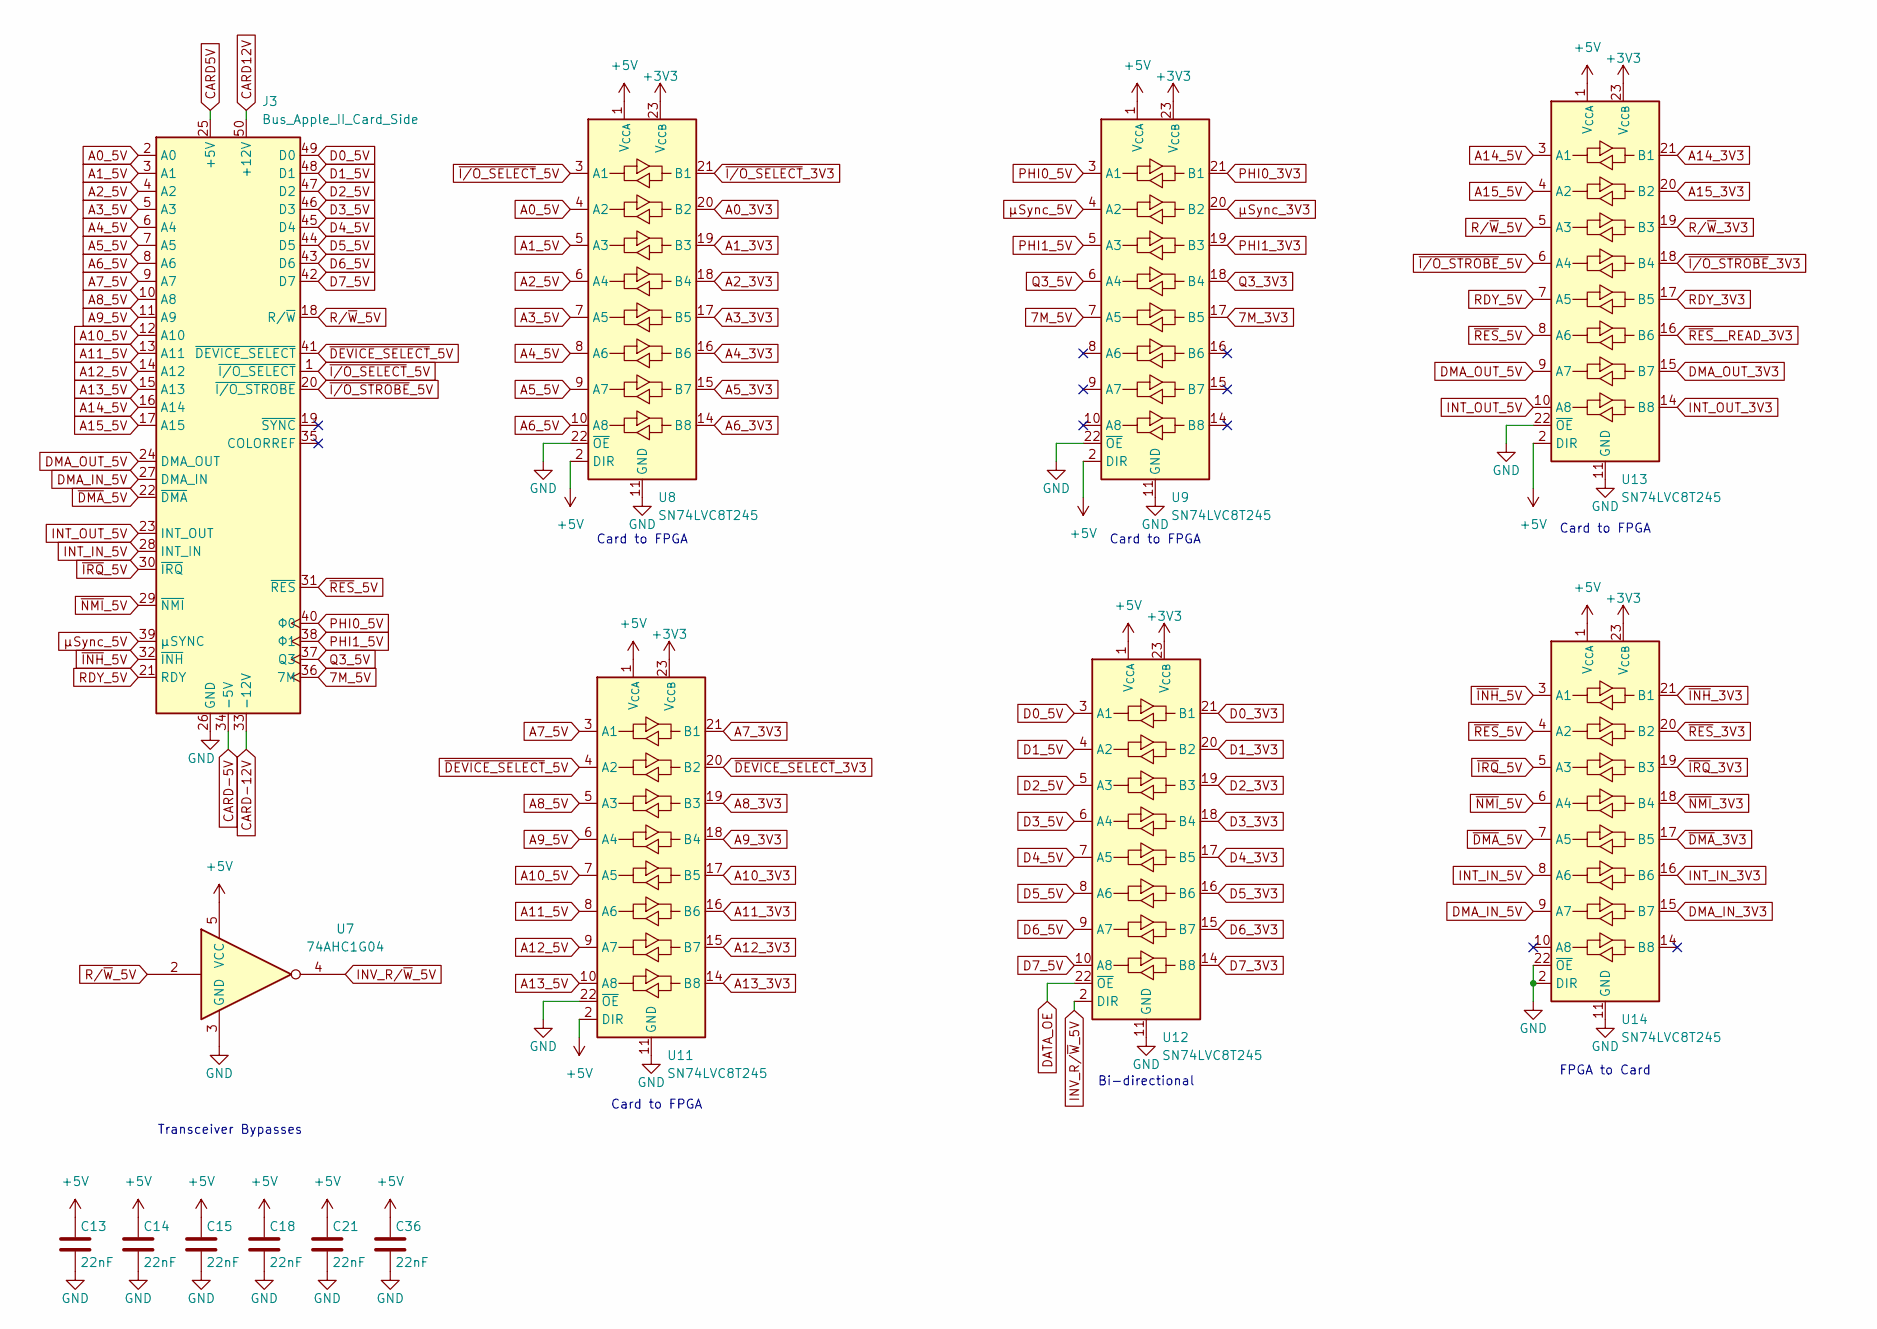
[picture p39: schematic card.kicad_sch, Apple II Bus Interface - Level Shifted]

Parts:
C13, C14, C15, C18, C21, C36: 22nF; C_0603_1608Metric; MPN CX0603MRX7R8BB223
J3: Bus_Apple_II_Card_Side; Peripheral_Bus_Edge
U7: 74AHC1G04; SOT95P280X145-5N; MPN SN74LVC1G04DBVR
U8, U9, U11, U12, U13, U14: SN74LVC8T245; DBQ24-L; MPN SN74LVC8T245DBQR

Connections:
7M_3V3: U9.17 (B5); also elsewhere on the board
7M_5V: J3.36 (7M), U9.7 (A5)
+3V3: U8.23 (V_{CCB}), U8.24 (V_{CCB}), U9.23 (V_{CCB}), U9.24 (V_{CCB}), U11.23 (V_{CCB}), U11.24 (V_{CCB}), U12.23 (V_{CCB}), U12.24 (V_{CCB}), U13.23 (V_{CCB}), U13.24 (V_{CCB}), U14.23 (V_{CCB}), U14.24 (V_{CCB}); also elsewhere on the board
+5V: C13.1, C14.1, C15.1, C18.1, C21.1, C36.1, U7.5 (VCC), U8.1 (V_{CCA}), U8.2 (DIR), U9.1 (V_{CCA}), U9.2 (DIR), U11.1 (V_{CCA}), U11.2 (DIR), U12.1 (V_{CCA}), U13.1 (V_{CCA}), U13.2 (DIR), U14.1 (V_{CCA}); also elsewhere on the board
A0_3V3: U8.20 (B2); also elsewhere on the board
A0_5V: J3.2 (A0), U8.4 (A2)
A1_3V3: U8.19 (B3); also elsewhere on the board
A1_5V: J3.3 (A1), U8.5 (A3)
A2_3V3: U8.18 (B4); also elsewhere on the board
A2_5V: J3.4 (A2), U8.6 (A4)
A3_3V3: U8.17 (B5); also elsewhere on the board
A3_5V: J3.5 (A3), U8.7 (A5)
A4_3V3: U8.16 (B6); also elsewhere on the board
A4_5V: J3.6 (A4), U8.8 (A6)
A5_3V3: U8.15 (B7); also elsewhere on the board
A5_5V: J3.7 (A5), U8.9 (A7)
A6_3V3: U8.14 (B8); also elsewhere on the board
A6_5V: J3.8 (A6), U8.10 (A8)
A7_3V3: U11.21 (B1); also elsewhere on the board
A7_5V: J3.9 (A7), U11.3 (A1)
A8_3V3: U11.19 (B3); also elsewhere on the board
A8_5V: J3.10 (A8), U11.5 (A3)
A9_3V3: U11.18 (B4); also elsewhere on the board
A9_5V: J3.11 (A9), U11.6 (A4)
A10_3V3: U11.17 (B5); also elsewhere on the board
A10_5V: J3.12 (A10), U11.7 (A5)
A11_3V3: U11.16 (B6); also elsewhere on the board
A11_5V: J3.13 (A11), U11.8 (A6)
A12_3V3: U11.15 (B7); also elsewhere on the board
A12_5V: J3.14 (A12), U11.9 (A7)
A13_3V3: U11.14 (B8); also elsewhere on the board
A13_5V: J3.15 (A13), U11.10 (A8)
A14_3V3: U13.21 (B1); also elsewhere on the board
A14_5V: J3.16 (A14), U13.3 (A1)
A15_3V3: U13.20 (B2); also elsewhere on the board
A15_5V: J3.17 (A15), U13.4 (A2)
CARD5V: J3.25 (+5V); also elsewhere on the board
CARD12V: J3.50 (+12V); also elsewhere on the board
CARD-5V: J3.34 (-5V); also elsewhere on the board
CARD-12V: J3.33 (-12V); also elsewhere on the board
D0_3V3: U12.21 (B1); also elsewhere on the board
D0_5V: J3.49 (D0), U12.3 (A1)
D1_3V3: U12.20 (B2); also elsewhere on the board
D1_5V: J3.48 (D1), U12.4 (A2)
D2_3V3: U12.19 (B3); also elsewhere on the board
D2_5V: J3.47 (D2), U12.5 (A3)
D3_3V3: U12.18 (B4); also elsewhere on the board
D3_5V: J3.46 (D3), U12.6 (A4)
D4_3V3: U12.17 (B5); also elsewhere on the board
D4_5V: J3.45 (D4), U12.7 (A5)
D5_3V3: U12.16 (B6); also elsewhere on the board
D5_5V: J3.44 (D5), U12.8 (A6)
D6_3V3: U12.15 (B7); also elsewhere on the board
D6_5V: J3.43 (D6), U12.9 (A7)
D7_3V3: U12.14 (B8); also elsewhere on the board
D7_5V: J3.42 (D7), U12.10 (A8)
DATA_OE: U12.22 (~OE); also elsewhere on the board
DMA_IN_3V3: U14.15 (B7); also elsewhere on the board
DMA_IN_5V: J3.27 (DMA_IN), U14.9 (A7)
DMA_OUT_3V3: U13.15 (B7); also elsewhere on the board
DMA_OUT_5V: J3.24 (DMA_OUT), U13.9 (A7)
GND: C13.2, C14.2, C15.2, C18.2, C21.2, C36.2, J3.26 (GND), U7.3 (GND), U8.11 (GND), U8.12 (GND), U8.13 (GND), U8.22 (~OE), U9.11 (GND), U9.12 (GND), U9.13 (GND), U9.22 (~OE), U11.11 (GND), U11.12 (GND), U11.13 (GND), U11.22 (~OE), U12.11 (GND), U12.12 (GND), U12.13 (GND), U13.11 (GND), U13.12 (GND), U13.13 (GND), U13.22 (~OE), U14.2 (DIR), U14.11 (GND), U14.12 (GND), U14.13 (GND), U14.22 (~OE); also elsewhere on the board
INT_IN_3V3: U14.16 (B6); also elsewhere on the board
INT_IN_5V: J3.28 (INT_IN), U14.8 (A6)
INT_OUT_3V3: U13.14 (B8); also elsewhere on the board
INT_OUT_5V: J3.23 (INT_OUT), U13.10 (A8)
INV_R/~W_5V: U7.4, U12.2 (DIR)
PHI0_3V3: U9.21 (B1); also elsewhere on the board
PHI0_5V: J3.40 (Φ0), U9.3 (A1)
PHI1_3V3: U9.19 (B3); also elsewhere on the board
PHI1_5V: J3.38 (Φ1), U9.5 (A3)
Q3_3V3: U9.18 (B4); also elsewhere on the board
Q3_5V: J3.37 (Q3), U9.6 (A4)
RDY_3V3: U13.17 (B5); also elsewhere on the board
RDY_5V: J3.21 (RDY), U13.7 (A5)
R/~W_3V3: U13.19 (B3); also elsewhere on the board
R/~W_5V: J3.18 (R/~W), U7.2, U13.5 (A3)
~DEVICE_SELECT_3V3: U11.20 (B2); also elsewhere on the board
~DEVICE_SELECT_5V: J3.41 (~DEVICE_SELECT), U11.4 (A2)
~DMA_3V3: U14.17 (B5); also elsewhere on the board
~DMA_5V: J3.22 (~DMA), U14.7 (A5)
~INH_3V3: U14.21 (B1); also elsewhere on the board
~INH_5V: J3.32 (~INH), U14.3 (A1)
~IRQ_3V3: U14.19 (B3); also elsewhere on the board
~IRQ_5V: J3.30 (~IRQ), U14.5 (A3)
~I/O_SELECT_3V3: U8.21 (B1); also elsewhere on the board
~I/O_SELECT_5V: J3.1 (~I/O_SELECT), U8.3 (A1)
~I/O_STROBE_3V3: U13.18 (B4); also elsewhere on the board
~I/O_STROBE_5V: J3.20 (~I/O_STROBE), U13.6 (A4)
~NMI_3V3: U14.18 (B4); also elsewhere on the board
~NMI_5V: J3.29 (~NMI), U14.6 (A4)
~RES_3V3: U14.20 (B2); also elsewhere on the board
~RES_5V: J3.31 (~RES), U13.8 (A6), U14.4 (A2)
~RES__READ_3V3: U13.16 (B6); also elsewhere on the board
µSync_3V3: U9.20 (B2); also elsewhere on the board
µSync_5V: J3.39 (µSYNC), U9.4 (A2)

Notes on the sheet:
FPGA to Card
Card to FPGA
Transceiver Bypasses
Bi-directional

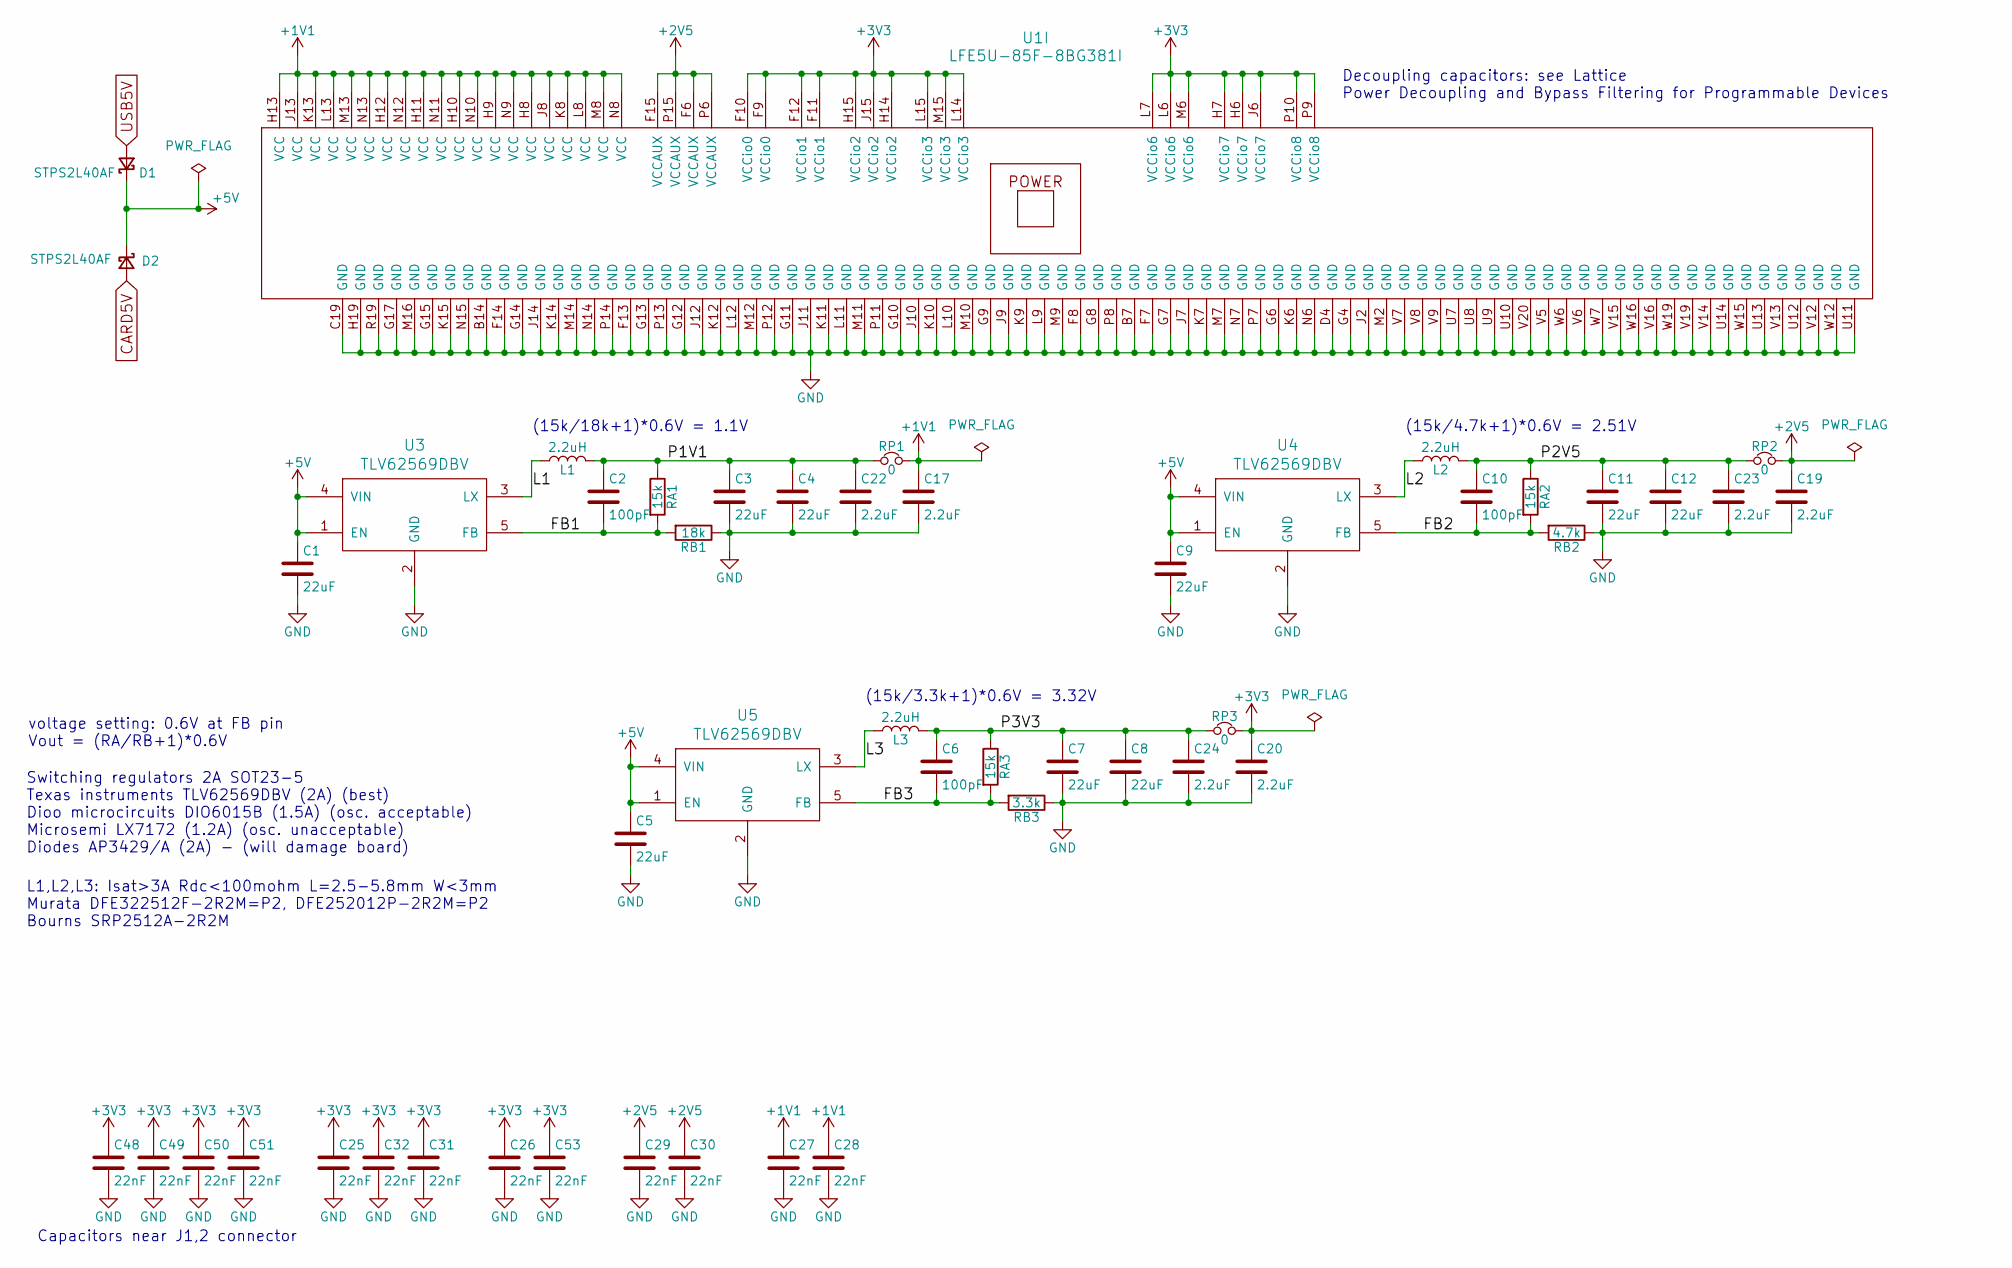
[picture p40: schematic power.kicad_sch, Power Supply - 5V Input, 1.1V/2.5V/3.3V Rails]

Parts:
C1, C3, C4, C5, C7, C8, C9, C11, C12: 22uF; C_0805_2012Metric; MPN CL21A226MQQNNNE
C2, C6, C10: 100pF; C_0603_1608Metric; MPN FH 0603CG101J500NT
C17, C19, C20, C22, C23, C24: 2.2uF; C_0805_2012Metric; MPN CL21B225KOFNNNE
C25, C26, C27, C28, C29, C30, C31, C32, C48, C49, C50, C51, C53: 22nF; C_0603_1608Metric; MPN CX0603MRX7R8BB223
D1, D2: STPS2L40AF; D_SMA; MPN STPS2L40AF
L1, L2, L3: 2.2uH; L_1008_1210; MPN DFE322520FD-2R2M=P2
RA1, RA2, RA3: 15k; R_0603_1608Metric; MPN RC0603FR-0715KL
RB1: 18k; R_0603_1608Metric; MPN RC0603FR-1018KL
RB2: 4.7k; R_0603_1608Metric; MPN AC0603FR-104K7L
RB3: 3.3k; R_0603_1608Metric; MPN RT0603FRE073K3L
RP1, RP2, RP3: 0; R_0805_2012Metric_Pad1.29x1.40mm_HandSolder_Jumper_NC; MPN 0805W8F0000T5E
U1: LFE5U-85F-8BG381I; BGA-381_pitch0.8mm_dia0.4mm; MPN LFE5U-85F-8BG381I
U3, U4, U5: TLV62569DBV; TSOT-25; MPN TLV62569DBVR

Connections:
+1V1: C17.1, C27.1, C28.1, RP1.2, U1.H8 (VCC), U1.H9 (VCC), U1.H10 (VCC), U1.H11 (VCC), U1.H12 (VCC), U1.H13 (VCC), U1.J8 (VCC), U1.J13 (VCC), U1.K8 (VCC), U1.K13 (VCC), U1.L8 (VCC), U1.L13 (VCC), U1.M8 (VCC), U1.M13 (VCC), U1.N8 (VCC), U1.N9 (VCC), U1.N10 (VCC), U1.N11 (VCC), U1.N12 (VCC), U1.N13 (VCC); also elsewhere on the board
+2V5: C19.1, C29.1, C30.1, RP2.2, U1.F6 (VCCAUX), U1.F15 (VCCAUX), U1.P6 (VCCAUX), U1.P15 (VCCAUX)
+3V3: C20.1, C25.1, C26.1, C31.1, C32.1, C48.1, C49.1, C50.1, C51.1, C53.1, RP3.2, U1.F9 (VCCio0), U1.F10 (VCCio0), U1.F11 (VCCio1), U1.F12 (VCCio1), U1.H6 (VCCio7), U1.H7 (VCCio7), U1.H14 (VCCio2), U1.H15 (VCCio2), U1.J6 (VCCio7), U1.J15 (VCCio2), U1.L6 (VCCio6), U1.L7 (VCCio6), U1.L14 (VCCio3), U1.L15 (VCCio3), U1.M6 (VCCio6), U1.M15 (VCCio3), U1.P9 (VCCio8), U1.P10 (VCCio8); also elsewhere on the board
+5V: C1.1, C5.1, C9.1, D1.1 (K), D2.1 (K), U3.1 (EN), U3.4 (VIN), U4.1 (EN), U4.4 (VIN), U5.1 (EN), U5.4 (VIN); also elsewhere on the board
/power/FB1: C2.2, RA1.2, RB1.2, U3.5 (FB)
/power/FB2: C10.2, RA2.2, RB2.2, U4.5 (FB)
/power/FB3: C6.2, RA3.2, RB3.2, U5.5 (FB)
/power/L1: L1.1, U3.3 (LX)
/power/L2: L2.1, U4.3 (LX)
/power/L3: L3.1, U5.3 (LX)
/power/P1V1: C2.1, C3.1, C4.1, C22.1, L1.2, RA1.1, RP1.1
/power/P2V5: C10.1, C11.1, C12.1, C23.1, L2.2, RA2.1, RP2.1
/power/P3V3: C6.1, C7.1, C8.1, C24.1, L3.2, RA3.1, RP3.1
CARD5V: D2.2 (A); also elsewhere on the board
GND: C1.2, C3.2, C4.2, C5.2, C7.2, C8.2, C9.2, C11.2, C12.2, C17.2, C19.2, C20.2, C22.2, C23.2, C24.2, C25.2, C26.2, C27.2, C28.2, C29.2, C30.2, C31.2, C32.2, C48.2, C49.2, C50.2, C51.2, C53.2, RB1.1, RB2.1, RB3.1, U1.B7 (GND), U1.B14 (GND), U1.C19 (GND), U1.D4 (GND), U1.F7 (GND), U1.F8 (GND), U1.F13 (GND), U1.F14 (GND), U1.G4 (GND), U1.G6 (GND), U1.G7 (GND), U1.G8 (GND), U1.G9 (GND), U1.G10 (GND), U1.G11 (GND), U1.G12 (GND), U1.G13 (GND), U1.G14 (GND), U1.G15 (GND), U1.G17 (GND), U1.H19 (GND), U1.J2 (GND), U1.J7 (GND), U1.J9 (GND), U1.J10 (GND), U1.J11 (GND), U1.J12 (GND), U1.J14 (GND), U1.K6 (GND), U1.K7 (GND), U1.K9 (GND), U1.K10 (GND), U1.K11 (GND), U1.K12 (GND), U1.K14 (GND), U1.K15 (GND), U1.L9 (GND), U1.L10 (GND), U1.L11 (GND), U1.L12 (GND), U1.M2 (GND), U1.M7 (GND), U1.M9 (GND), U1.M10 (GND), U1.M11 (GND), U1.M12 (GND), U1.M14 (GND), U1.M16 (GND), U1.N6 (GND), U1.N7 (GND), U1.N14 (GND), U1.N15 (GND), U1.P7 (GND), U1.P8 (GND), U1.P11 (GND), U1.P12 (GND), U1.P13 (GND), U1.P14 (GND), U1.R19 (GND), U1.U7 (GND), U1.U8 (GND), U1.U9 (GND), U1.U10 (GND), U1.U11 (GND), U1.U12 (GND), U1.U13 (GND), U1.U14 (GND), U1.V5 (GND), U1.V6 (GND), U1.V7 (GND), U1.V8 (GND), U1.V9 (GND), U1.V12 (GND), U1.V13 (GND), U1.V14 (GND), U1.V15 (GND), U1.V16 (GND), U1.V19 (GND), U1.V20 (GND), U1.W6 (GND), U1.W7 (GND), U1.W12 (GND), U1.W15 (GND), U1.W16 (GND), U1.W19 (GND), U3.2 (GND), U4.2 (GND), U5.2 (GND); also elsewhere on the board
USB5V: D1.2 (A); also elsewhere on the board

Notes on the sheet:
Switching regulators 2A SOT23-5 Texas instruments TLV62569DBV (2A) (best) Dioo microcircuits DIO6015B (1.5A) (osc. acceptable) Microsemi LX7172 (1.2A) (osc. unacceptable) Diodes AP3429/A (2A) - (will damage board)
(15k/18k+1)*0.6V = 1.1V
L1,L2,L3: Isat>3A Rdc<100mohm L=2.5-5.8mm W<3mm Murata DFE322512F-2R2M=P2, DFE252012P-2R2M=P2 Bourns SRP2512A-2R2M
(15k/4.7k+1)*0.6V = 2.51V
(15k/3.3k+1)*0.6V = 3.32V
Capacitors near J1,2 connector
Decoupling capacitors: see Lattice Power Decoupling and Bypass Filtering for Programmable Devices
voltage setting: 0.6V at FB pin Vout = (RA/RB+1)*0.6V

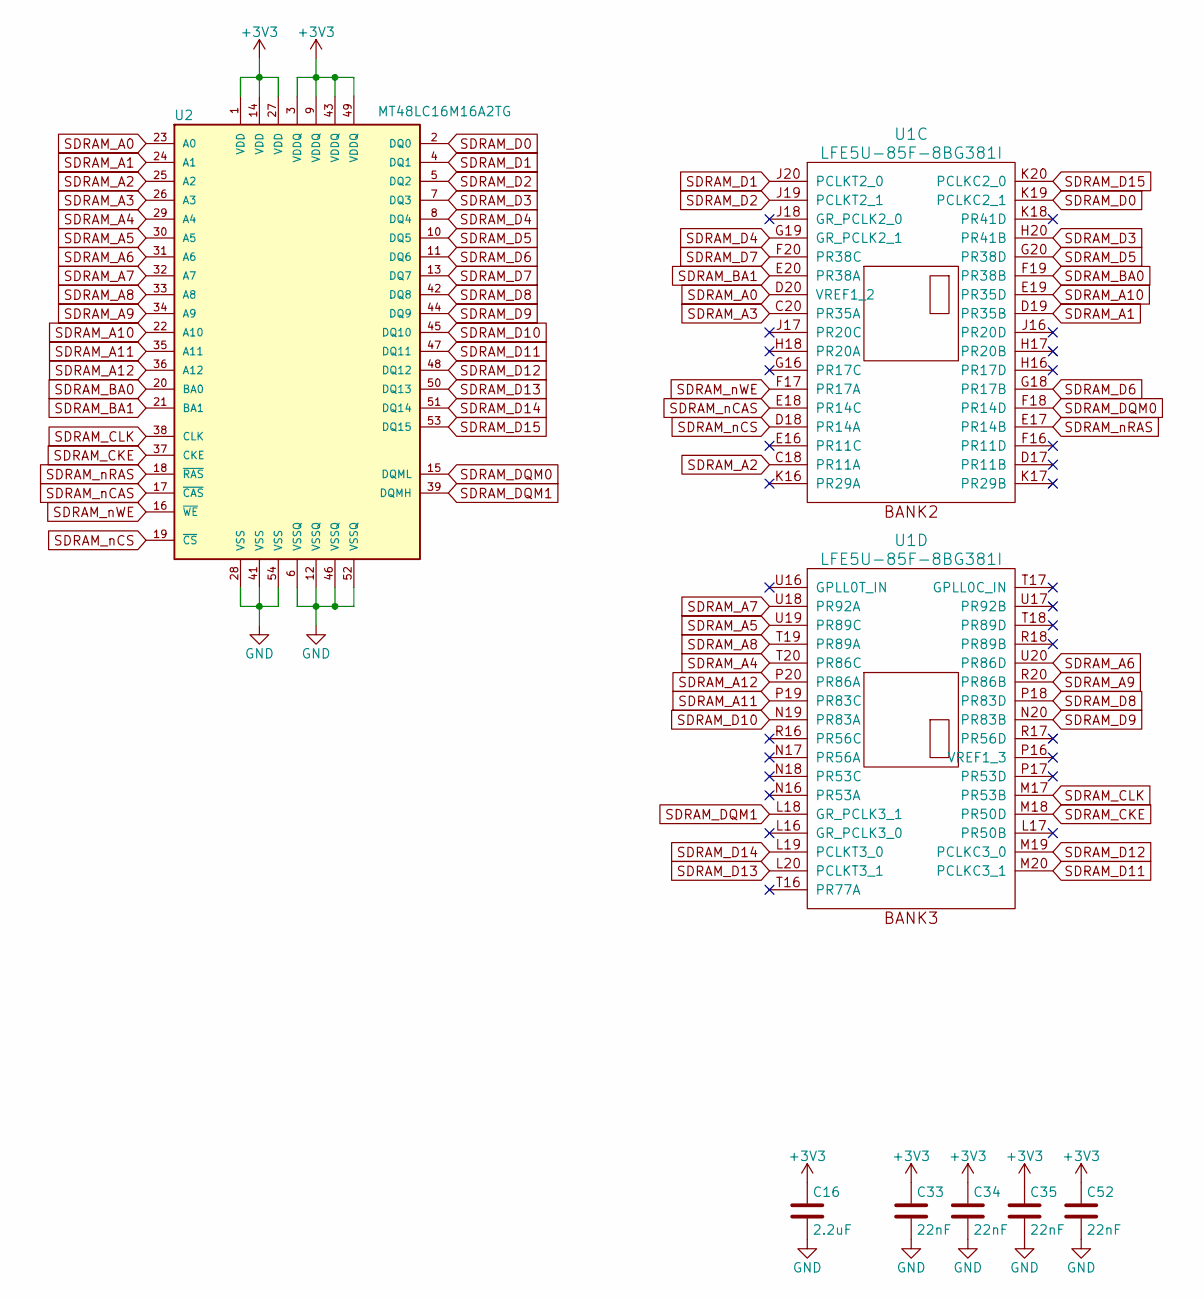
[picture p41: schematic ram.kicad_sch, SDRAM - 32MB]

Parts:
C16: 2.2uF; C_0805_2012Metric; MPN CL21B225KOFNNNE
C33, C34, C35, C52: 22nF; C_0603_1608Metric; MPN CX0603MRX7R8BB223
U1: LFE5U-85F-8BG381I; BGA-381_pitch0.8mm_dia0.4mm; MPN LFE5U-85F-8BG381I
U2: MT48LC16M16A2TG; TSOP54; MPN AS4C32M16SB-7TCNTR

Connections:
+3V3: C16.1, C33.1, C34.1, C35.1, C52.1, U2.1 (VDD), U2.3 (VDDQ), U2.9 (VDDQ), U2.14 (VDD), U2.27 (VDD), U2.43 (VDDQ), U2.49 (VDDQ); also elsewhere on the board
GND: C16.2, C33.2, C34.2, C35.2, C52.2, U2.6 (VSSQ), U2.12 (VSSQ), U2.28 (VSS), U2.41 (VSS), U2.46 (VSSQ), U2.52 (VSSQ), U2.54 (VSS); also elsewhere on the board
SDRAM_A0: U1.D20 (VREF1_2), U2.23 (A0)
SDRAM_A1: U1.D19 (PR35B), U2.24 (A1)
SDRAM_A2: U1.C18 (PR11A), U2.25 (A2)
SDRAM_A3: U1.C20 (PR35A), U2.26 (A3)
SDRAM_A4: U1.T20 (PR86C), U2.29 (A4)
SDRAM_A5: U1.U19 (PR89C), U2.30 (A5)
SDRAM_A6: U1.U20 (PR86D), U2.31 (A6)
SDRAM_A7: U1.U18 (PR92A), U2.32 (A7)
SDRAM_A8: U1.T19 (PR89A), U2.33 (A8)
SDRAM_A9: U1.R20 (PR86B), U2.34 (A9)
SDRAM_A10: U1.E19 (PR35D), U2.22 (A10)
SDRAM_A11: U1.P19 (PR83C), U2.35 (A11)
SDRAM_A12: U1.P20 (PR86A), U2.36 (A12)
SDRAM_BA0: U1.F19 (PR38B), U2.20 (BA0)
SDRAM_BA1: U1.E20 (PR38A), U2.21 (BA1)
SDRAM_CKE: U1.M18 (PR50D), U2.37 (CKE)
SDRAM_CLK: U1.M17 (PR53B), U2.38 (CLK)
SDRAM_D0: U1.K19 (PCLKC2_1), U2.2 (DQ0)
SDRAM_D1: U1.J20 (PCLKT2_0), U2.4 (DQ1)
SDRAM_D2: U1.J19 (PCLKT2_1), U2.5 (DQ2)
SDRAM_D3: U1.H20 (PR41B), U2.7 (DQ3)
SDRAM_D4: U1.G19 (GR_PCLK2_1), U2.8 (DQ4)
SDRAM_D5: U1.G20 (PR38D), U2.10 (DQ5)
SDRAM_D6: U1.G18 (PR17B), U2.11 (DQ6)
SDRAM_D7: U1.F20 (PR38C), U2.13 (DQ7)
SDRAM_D8: U1.P18 (PR83D), U2.42 (DQ8)
SDRAM_D9: U1.N20 (PR83B), U2.44 (DQ9)
SDRAM_D10: U1.N19 (PR83A), U2.45 (DQ10)
SDRAM_D11: U1.M20 (PCLKC3_1), U2.47 (DQ11)
SDRAM_D12: U1.M19 (PCLKC3_0), U2.48 (DQ12)
SDRAM_D13: U1.L20 (PCLKT3_1), U2.50 (DQ13)
SDRAM_D14: U1.L19 (PCLKT3_0), U2.51 (DQ14)
SDRAM_D15: U1.K20 (PCLKC2_0), U2.53 (DQ15)
SDRAM_DQM0: U1.F18 (PR14D), U2.15 (DQML)
SDRAM_DQM1: U1.L18 (GR_PCLK3_1), U2.39 (DQMH)
SDRAM_nCAS: U1.E18 (PR14C), U2.17 (~CAS)
SDRAM_nCS: U1.D18 (PR14A), U2.19 (~CS)
SDRAM_nRAS: U1.E17 (PR14B), U2.18 (~RAS)
SDRAM_nWE: U1.F17 (PR17A), U2.16 (~WE)

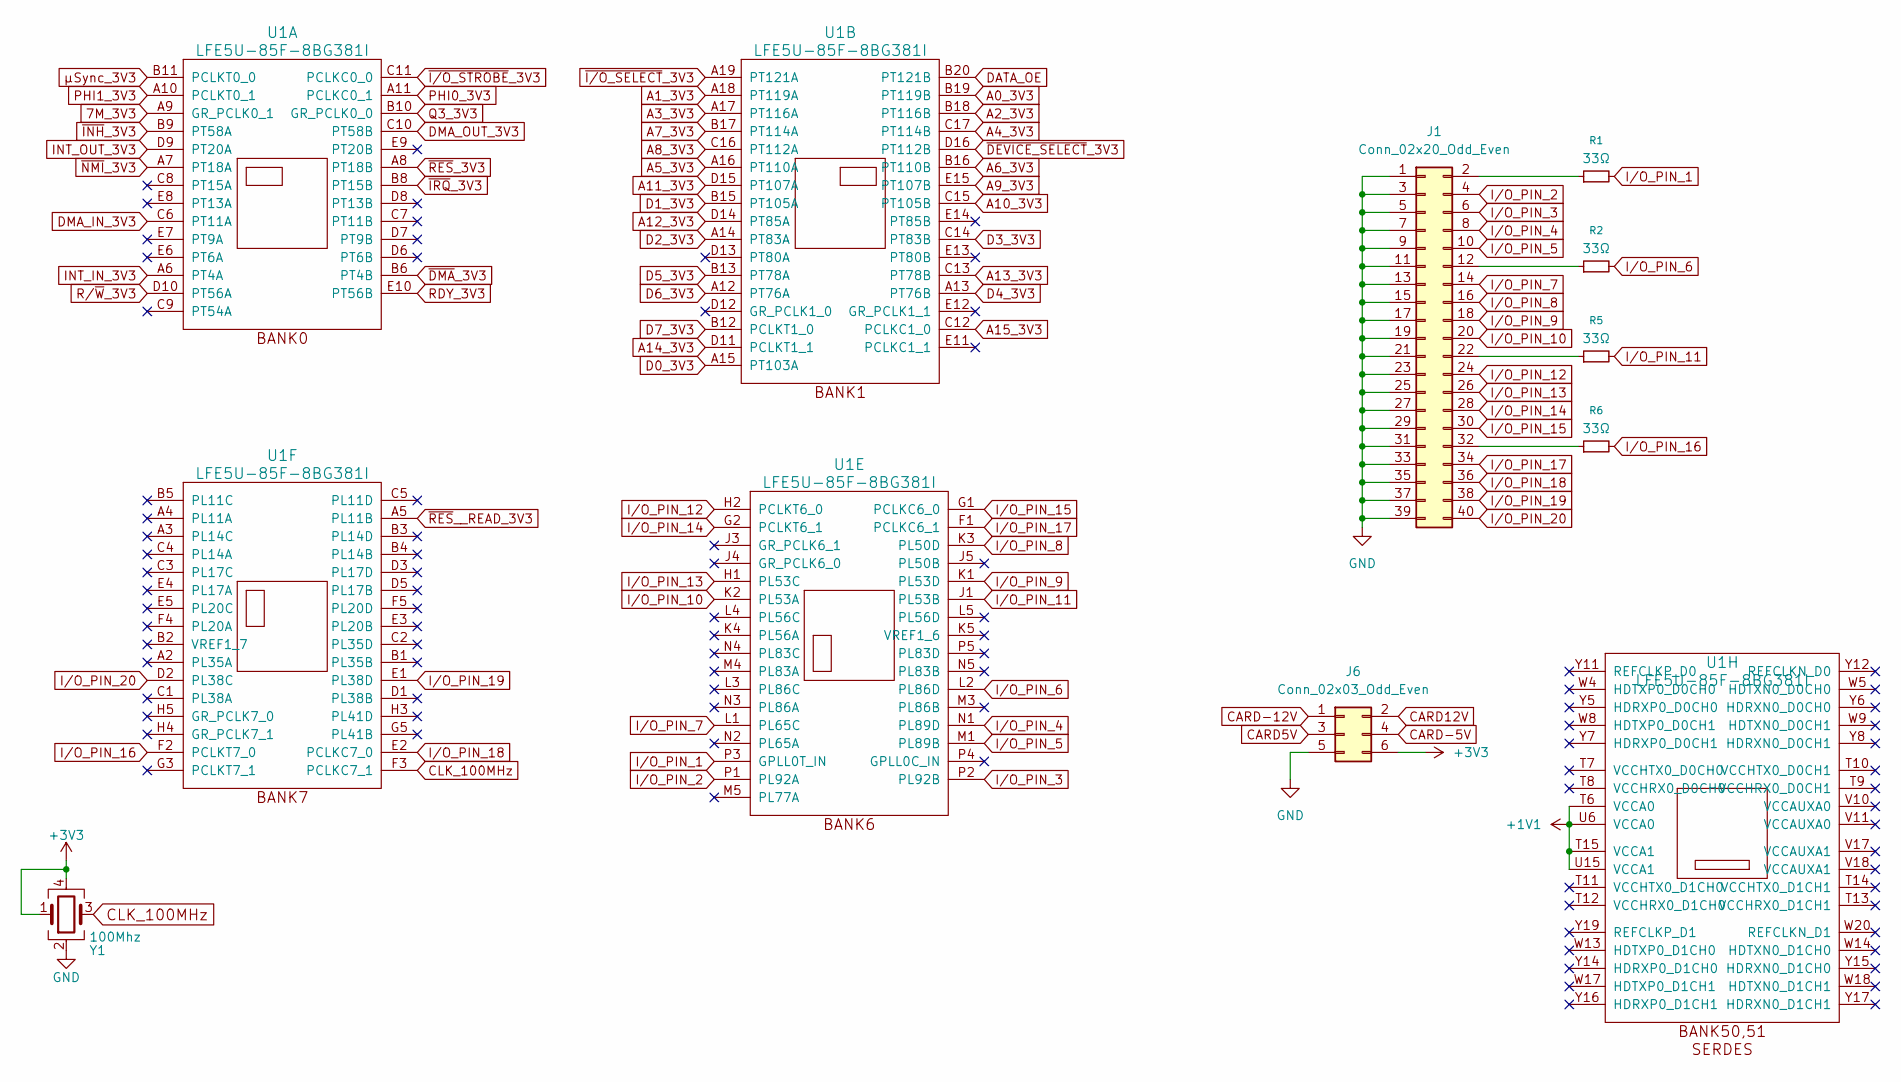
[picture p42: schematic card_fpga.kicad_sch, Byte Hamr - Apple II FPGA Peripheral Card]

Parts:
J1: Conn_02x20_Odd_Even; PinHeader_2x20_P2.54mm_Vertical
J6: Conn_02x03_Odd_Even; PinHeader_2x03_P2.54mm_Vertical
R1, R2, R5, R6: 33Ω; R_0603_1608Metric; MPN 0603WAF330JT5E
U1: LFE5U-85F-8BG381I; BGA-381_pitch0.8mm_dia0.4mm; MPN LFE5U-85F-8BG381I
Y1: 100Mhz; Crystal_SMD_7050_4Pads; MPN CWX813-100.0M

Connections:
7M_3V3: U1.A9 (GR_PCLK0_1); also elsewhere on the board
+1V1: U1.T6 (VCCA0), U1.T15 (VCCA1), U1.U6 (VCCA0), U1.U15 (VCCA1); also elsewhere on the board
+3V3: J6.6, Y1.1, Y1.4; also elsewhere on the board
A0_3V3: U1.B19 (PT119B); also elsewhere on the board
A1_3V3: U1.A18 (PT119A); also elsewhere on the board
A2_3V3: U1.B18 (PT116B); also elsewhere on the board
A3_3V3: U1.A17 (PT116A); also elsewhere on the board
A4_3V3: U1.C17 (PT114B); also elsewhere on the board
A5_3V3: U1.A16 (PT110A); also elsewhere on the board
A6_3V3: U1.B16 (PT110B); also elsewhere on the board
A7_3V3: U1.B17 (PT114A); also elsewhere on the board
A8_3V3: U1.C16 (PT112A); also elsewhere on the board
A9_3V3: U1.E15 (PT107B); also elsewhere on the board
A10_3V3: U1.C15 (PT105B); also elsewhere on the board
A11_3V3: U1.D15 (PT107A); also elsewhere on the board
A12_3V3: U1.D14 (PT85A); also elsewhere on the board
A13_3V3: U1.C13 (PT78B); also elsewhere on the board
A14_3V3: U1.D11 (PCLKT1_1); also elsewhere on the board
A15_3V3: U1.C12 (PCLKC1_0); also elsewhere on the board
CARD5V: J6.3; also elsewhere on the board
CARD12V: J6.2; also elsewhere on the board
CARD-5V: J6.4; also elsewhere on the board
CARD-12V: J6.1; also elsewhere on the board
CLK_100MHz: U1.F3 (PCLKC7_1), Y1.3
D0_3V3: U1.A15 (PT103A); also elsewhere on the board
D1_3V3: U1.B15 (PT105A); also elsewhere on the board
D2_3V3: U1.A14 (PT83A); also elsewhere on the board
D3_3V3: U1.C14 (PT83B); also elsewhere on the board
D4_3V3: U1.A13 (PT76B); also elsewhere on the board
D5_3V3: U1.B13 (PT78A); also elsewhere on the board
D6_3V3: U1.A12 (PT76A); also elsewhere on the board
D7_3V3: U1.B12 (PCLKT1_0); also elsewhere on the board
DATA_OE: U1.B20 (PT121B); also elsewhere on the board
DMA_IN_3V3: U1.C6 (PT11A); also elsewhere on the board
DMA_OUT_3V3: U1.C10 (PT58B); also elsewhere on the board
GND: J1.1, J1.3, J1.5, J1.7, J1.9, J1.11, J1.13, J1.15, J1.17, J1.19, J1.21, J1.23, J1.25, J1.27, J1.29, J1.31, J1.33, J1.35, J1.37, J1.39, J6.5, Y1.2; also elsewhere on the board
INT_IN_3V3: U1.A6 (PT4A); also elsewhere on the board
INT_OUT_3V3: U1.D9 (PT20A); also elsewhere on the board
I/O_PIN_1: R1.2, U1.P3 (GPLL0T_IN)
I/O_PIN_2: J1.4, U1.P1 (PL92A)
I/O_PIN_3: J1.6, U1.P2 (PL92B)
I/O_PIN_4: J1.8, U1.N1 (PL89D)
I/O_PIN_5: J1.10, U1.M1 (PL89B)
I/O_PIN_6: R2.2, U1.L2 (PL86D)
I/O_PIN_7: J1.14, U1.L1 (PL65C)
I/O_PIN_8: J1.16, U1.K3 (PL50D)
I/O_PIN_9: J1.18, U1.K1 (PL53D)
I/O_PIN_10: J1.20, U1.K2 (PL53A)
I/O_PIN_11: R5.2, U1.J1 (PL53B)
I/O_PIN_12: J1.24, U1.H2 (PCLKT6_0)
I/O_PIN_13: J1.26, U1.H1 (PL53C)
I/O_PIN_14: J1.28, U1.G2 (PCLKT6_1)
I/O_PIN_15: J1.30, U1.G1 (PCLKC6_0)
I/O_PIN_16: R6.2, U1.F2 (PCLKT7_0)
I/O_PIN_17: J1.34, U1.F1 (PCLKC6_1)
I/O_PIN_18: J1.36, U1.E2 (PCLKC7_0)
I/O_PIN_19: J1.38, U1.E1 (PL38D)
I/O_PIN_20: J1.40, U1.D2 (PL38C)
unnamed: J1.2, R1.1
unnamed: J1.12, R2.1
unnamed: J1.22, R5.1
unnamed: J1.32, R6.1
PHI0_3V3: U1.A11 (PCLKC0_1); also elsewhere on the board
PHI1_3V3: U1.A10 (PCLKT0_1); also elsewhere on the board
Q3_3V3: U1.B10 (GR_PCLK0_0); also elsewhere on the board
RDY_3V3: U1.E10 (PT56B); also elsewhere on the board
R/~W_3V3: U1.D10 (PT56A); also elsewhere on the board
~DEVICE_SELECT_3V3: U1.D16 (PT112B); also elsewhere on the board
~DMA_3V3: U1.B6 (PT4B); also elsewhere on the board
~INH_3V3: U1.B9 (PT58A); also elsewhere on the board
~IRQ_3V3: U1.B8 (PT15B); also elsewhere on the board
~I/O_SELECT_3V3: U1.A19 (PT121A); also elsewhere on the board
~I/O_STROBE_3V3: U1.C11 (PCLKC0_0); also elsewhere on the board
~NMI_3V3: U1.A7 (PT18A); also elsewhere on the board
~RES_3V3: U1.A8 (PT18B); also elsewhere on the board
~RES__READ_3V3: U1.A5 (PL11B); also elsewhere on the board
µSync_3V3: U1.B11 (PCLKT0_0); also elsewhere on the board

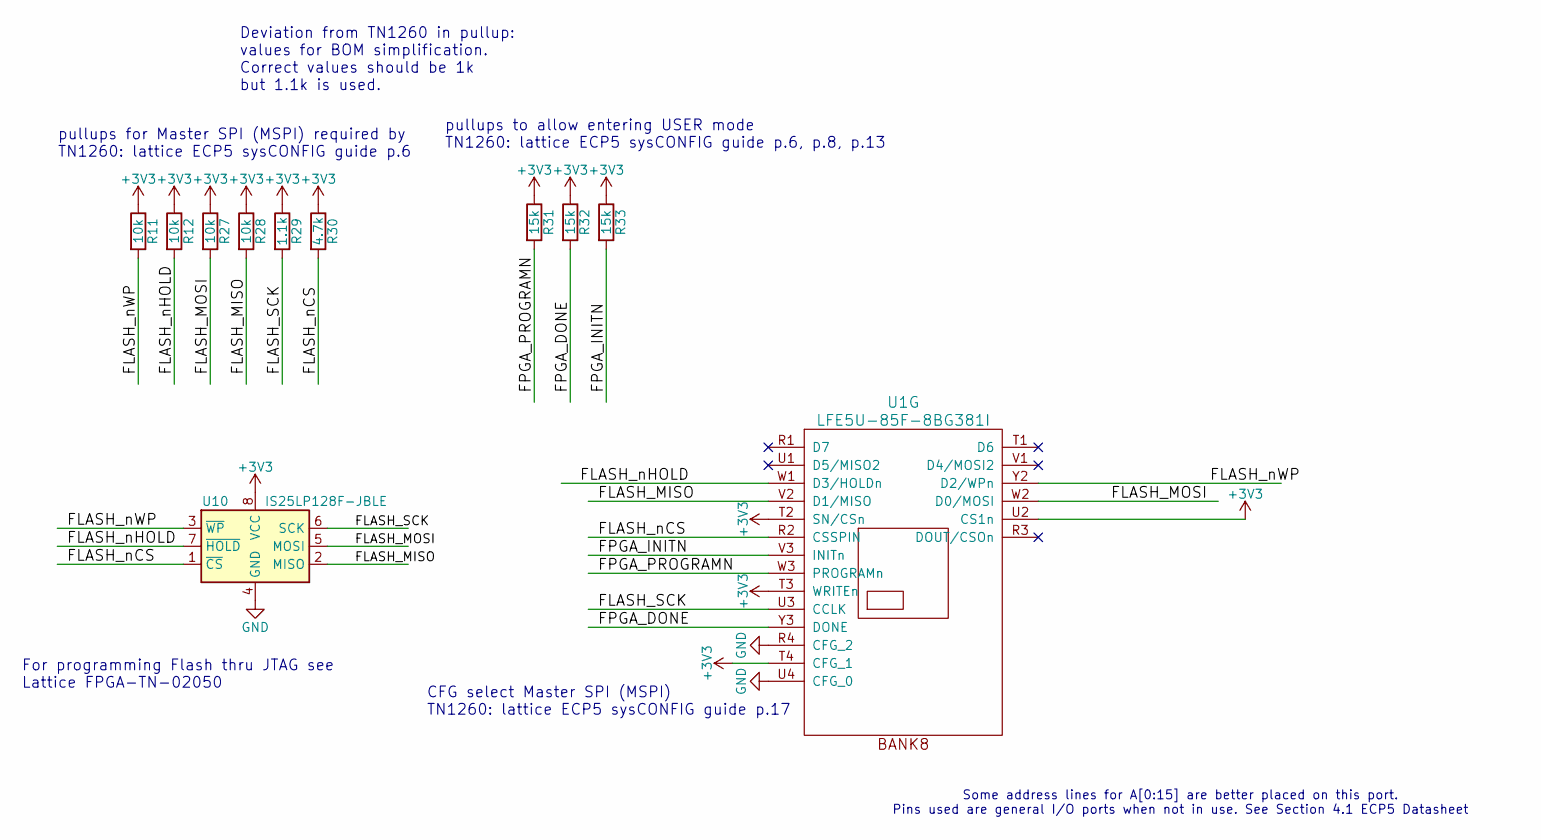
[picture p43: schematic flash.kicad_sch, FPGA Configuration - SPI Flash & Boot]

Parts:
R11, R12, R27, R28: 10k; R_0603_1608Metric; MPN AF0603FR-0710KL
R29: 1.1k; R_0603_1608Metric; MPN 0603WAF1101T5E
R30: 4.7k; R_0603_1608Metric; MPN AC0603FR-104K7L
R31, R32, R33: 15k; R_0603_1608Metric; MPN RC0603FR-0715KL
U1: LFE5U-85F-8BG381I; BGA-381_pitch0.8mm_dia0.4mm; MPN LFE5U-85F-8BG381I
U10: IS25LP128F-JBLE; SOA008-150-208mil; MPN IS25LP128F-JBLE

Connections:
+3V3: R11.1, R12.1, R27.1, R28.1, R29.1, R30.1, R31.1, R32.1, R33.1, U1.T2 (SN/CSn), U1.T3 (WRITEn), U1.T4 (CFG_1), U1.U2 (CS1n), U10.8 (VCC); also elsewhere on the board
/flash/FLASH_MISO: R28.2, U1.V2 (D1/MISO), U10.2 (MISO)
/flash/FLASH_MOSI: R27.2, U1.W2 (D0/MOSI), U10.5 (MOSI)
/flash/FLASH_SCK: R29.2, U1.U3 (CCLK), U10.6 (SCK)
/flash/FLASH_nCS: R30.2, U1.R2 (CSSPIN), U10.1 (~CS)
/flash/FLASH_nHOLD: R12.2, U1.W1 (D3/HOLDn), U10.7 (~HOLD)
/flash/FLASH_nWP: R11.2, U1.Y2 (D2/WPn), U10.3 (~WP)
/flash/FPGA_DONE: R32.2, U1.Y3 (DONE)
/flash/FPGA_INITN: R33.2, U1.V3 (INITn)
/flash/FPGA_PROGRAMN: R31.2, U1.W3 (PROGRAMn)
GND: U1.R4 (CFG_2), U1.U4 (CFG_0), U10.4 (GND); also elsewhere on the board

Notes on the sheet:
pullups to allow entering USER mode TN1260: lattice ECP5 sysCONFIG guide p.6, p.8, p.13
pullups for Master SPI (MSPI) required by TN1260: lattice ECP5 sysCONFIG guide p.6
Some address lines for A[0:15] are better placed on this port. Pins used are general I/O ports when not in use. See Section 4.1 ECP5 Datasheet
Deviation from TN1260 in pullup: values for BOM simplification. Correct values should be 1k but 1.1k is used.
CFG select Master SPI (MSPI) TN1260: lattice ECP5 sysCONFIG guide p.17
For programming Flash thru JTAG see Lattice FPGA-TN-02050

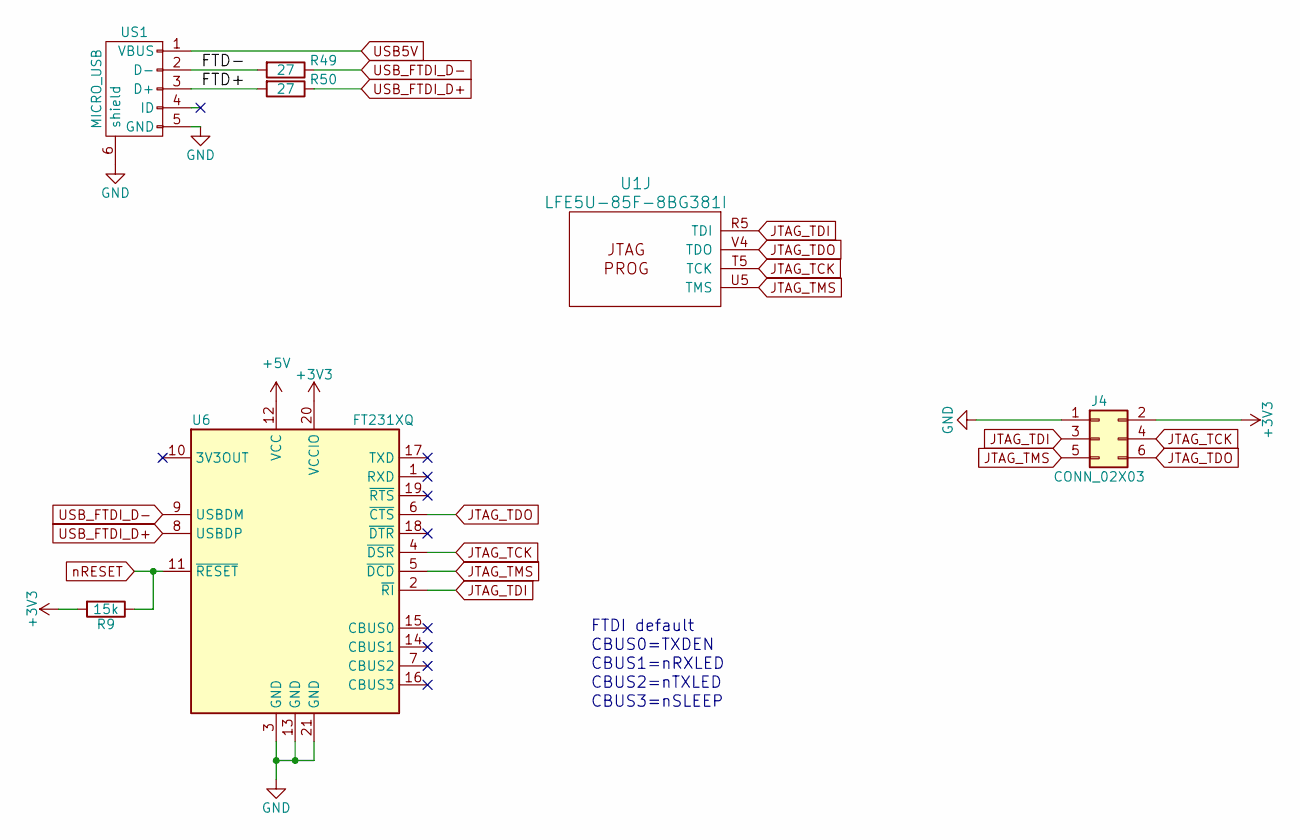
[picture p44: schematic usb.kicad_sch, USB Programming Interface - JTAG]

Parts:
J4: CONN_02X03; PinHeader_2x03_P2.54mm_Vertical
R9: 15k; R_0603_1608Metric; MPN RC0603FR-0715KL
R49, R50: 27; R_0603_1608Metric; MPN RC0603FR-0727RL
U1: LFE5U-85F-8BG381I; BGA-381_pitch0.8mm_dia0.4mm; MPN LFE5U-85F-8BG381I
U6: FT231XQ; FT231X-QFN-20-1EP_4x4mm_P0.5mm_EP2x2mm; MPN FT231XQ-R
US1: MICRO_USB; USB-MICRO-B-FCI-10118192-0001LF; MPN 10118192-0001LF

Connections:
+3V3: J4.2, R9.2, U6.20 (VCCIO); also elsewhere on the board
+5V: U6.12 (VCC); also elsewhere on the board
/usb/FTD+: R50.2, US1.3 (D+)
/usb/FTD-: R49.2, US1.2 (D-)
GND: J4.1, U6.3 (GND), U6.13 (GND), U6.21 (GND), US1.5 (GND), US1.6 (shield); also elsewhere on the board
JTAG_TCK: J4.4, U1.T5 (TCK), U6.4 (~DSR)
JTAG_TDI: J4.3, U1.R5 (TDI), U6.2 (~RI)
JTAG_TDO: J4.6, U1.V4 (TDO), U6.6 (~CTS)
JTAG_TMS: J4.5, U1.U5 (TMS), U6.5 (~DCD)
USB5V: US1.1 (VBUS); also elsewhere on the board
USB_FTDI_D+: R50.1, U6.8 (USBDP)
USB_FTDI_D-: R49.1, U6.9 (USBDM)
nRESET: R9.1, U6.11 (~RESET)

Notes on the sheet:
FTDI default
CBUS0=TXDEN
CBUS3=nSLEEP
CBUS2=nTXLED
CBUS1=nRXLED

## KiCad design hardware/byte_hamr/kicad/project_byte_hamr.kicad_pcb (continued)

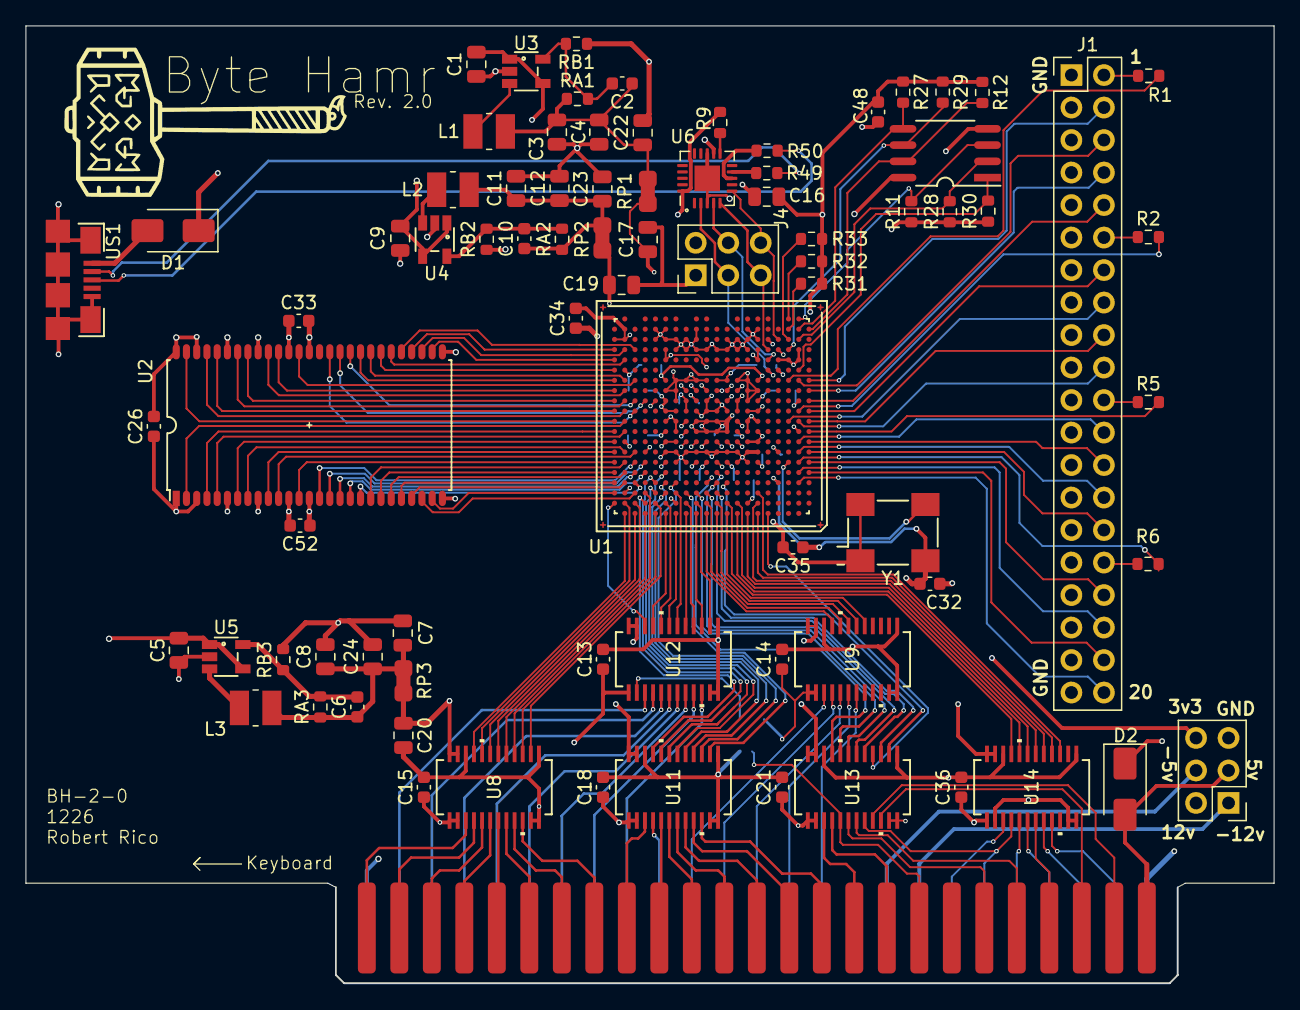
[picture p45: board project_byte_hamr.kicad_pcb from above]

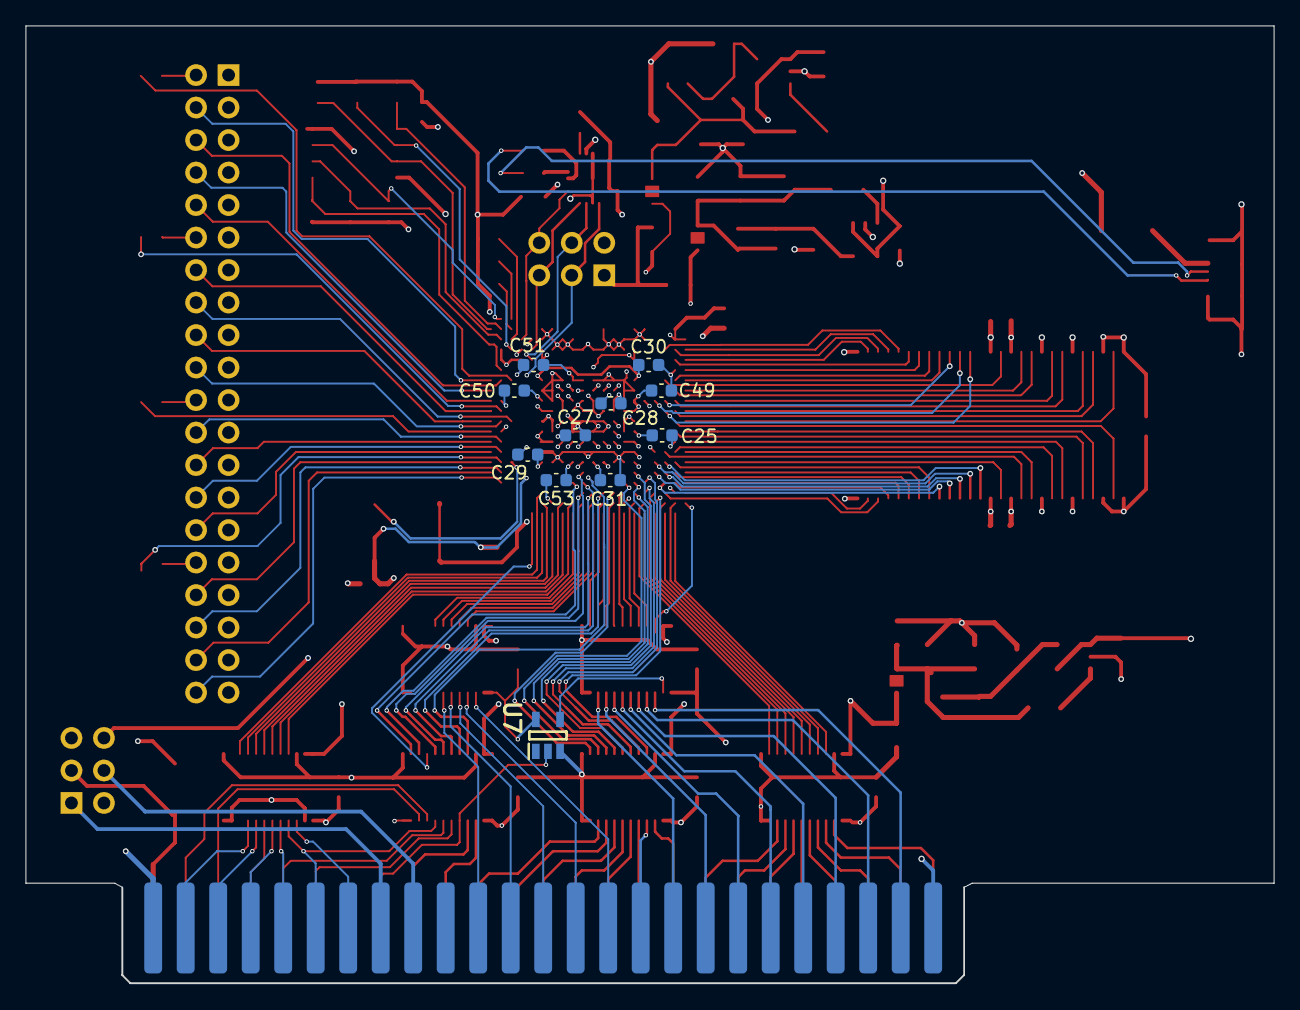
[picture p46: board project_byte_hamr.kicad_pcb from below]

Board: 4 copper layers, 97.6 x 74.8 mm, 92 parts (11 on the bottom side), 190 nets.

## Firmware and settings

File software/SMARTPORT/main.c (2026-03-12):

#include <stdio.h>
#include "pico/stdlib.h"
#include "hardware/pio.h"
#include "hardware/structs/sio.h"
#include "picoport.h"
#include "sp_proto.h"
#include "sd_block.h"
#include "fm_rx.pio.h"
#include "fm_tx.pio.h"

// SmartPort bus loop — runs on Core 0, launches Core 1 for serial (sp_cmd.c)
extern void sp_main(PIO pio_rx, uint sm_rx, PIO pio_tx, uint sm_tx);

// PIO RX program offset (set in main, used by pio_rx_restart)
static uint g_rx_offset;
// PIO TX program offset (set in main, used by pio_tx_restart)
static uint g_tx_offset;

// Called from assembly to restart PIO RX state machine after each packet
void pio_rx_restart(void) {
    PIO pio = pio0;
    uint sm = 0;
    pio_sm_set_enabled(pio, sm, false);
    pio_sm_clear_fifos(pio, sm);
    pio_sm_restart(pio, sm);
    pio_sm_exec(pio, sm, pio_encode_jmp(g_rx_offset));
    pio_sm_set_enabled(pio, sm, true);
}

// Reset PIO TX SM before each packet — ensures no leftover OSR bits
void pio_tx_restart(void) {
    PIO pio = pio0;
    uint sm = 1;
    pio_sm_set_enabled(pio, sm, false);
    pio_sm_clear_fifos(pio, sm);
    pio_sm_restart(pio, sm);
    pio_sm_exec(pio, sm, pio_encode_set(pio_pins, 0));  // force pin LOW (idle)
    pio_sm_exec(pio, sm, pio_encode_jmp(g_tx_offset));
    pio_sm_set_enabled(pio, sm, true);
}

int main() {
    stdio_init_all();

    // --- Configure ACK pin: open-drain, initially deasserted (input/hi-Z) ---
    gpio_init(SP_ACK);
    gpio_put(SP_ACK, 0);           // output value = LOW when driven
    gpio_set_dir(SP_ACK, GPIO_IN); // start as input = hi-Z = deasserted

    // --- Configure all input pins ---
    // Phase pins (GP3-6)
    for (int i = SP_PHI_BASE; i < SP_PHI_BASE + 4; i++) {
        gpio_init(i);
        gpio_set_dir(i, GPIO_IN);
    }
    // Other input pins (NOT wrdata/rddata — those are configured by PIO)
    int input_pins[] = { SP_ENBL1, SP_DEVSEL, SP_WREQ, SP_ENBL2 };
    for (int i = 0; i < 4; i++) {
        gpio_init(input_pins[i]);
        gpio_set_dir(input_pins[i], GPIO_IN);
    }
    gpio_pull_up(SP_ENBL1);  // active-low, needs pull-up

    // --- PIO RX: FM receiver on WRDATA (GP11) ---
    PIO pio_rx = pio0;
    uint sm_rx = 0;
    g_rx_offset = pio_add_program(pio_rx, &fm_rx_program);
    fm_rx_program_init(pio_rx, sm_rx, g_rx_offset, SP_WRDATA);

    // --- PIO TX: FM transmitter on RDDATA (GP2) ---
    PIO pio_tx = pio0;
    uint sm_tx = 1;
    g_tx_offset = pio_add_program(pio_tx, &fm_tx_program);
    uint tx_offset = g_tx_offset;
    fm_tx_program_init(pio_tx, sm_tx, tx_offset, SP_RDDATA);
    gpio_pull_down(SP_RDDATA);  // idle LOW → FPGA rddata HIGH (idle)

    // Wait for USB serial to enumerate
    sleep_ms(2000);
    printf("PicoPort SmartPort Device\n");
    printf("  RX(WRDATA)=GP%d  TX(RDDATA)=GP%d\n", SP_WRDATA, SP_RDDATA);
    printf("  ACK=GP%d  REQ=GP%d\n", SP_ACK, SP_REQ);

    // ============================================================
    // GPIO wiring diagnostic — verify every signal
    // ============================================================
    printf("\n--- GPIO Wiring Diagnostic ---\n");
    printf("  Pico   FPGA    Signal       Value  Expected\n");
    printf("  -----  ------  -----------  -----  --------\n");

    // Read all pins once
    uint32_t gpio = sio_hw->gpio_in;

    // _enbl1: GP2 ← GPIO1 (active LOW, should be HIGH when no drive selected)
    int enbl1 = (gpio >> SP_ENBL1) & 1;
    printf("  GP2    GPIO1   _enbl1       %d      1 (inactive)  %s\n",
           enbl1, enbl1 ? "OK" : "WRONG");

    // phase[2]: GP3 ← GPIO2
    int ph2 = (gpio >> 3) & 1;
    printf("  GP3    GPIO2   phase[2]     %d\n", ph2);

    // phase[3]: GP4 ← GPIO3
    int ph3 = (gpio >> 4) & 1;
    printf("  GP4    GPIO3   phase[3]     %d\n", ph3);

    // phase[0]/REQ: GP5 ← GPIO4
    int ph0 = (gpio >> SP_REQ) & 1;
    printf("  GP5    GPIO4   PH0/REQ      %d\n", ph0);

    // phase[1]: GP6 ← GPIO5
    int ph1 = (gpio >> 6) & 1;
    printf("  GP6    GPIO5   phase[1]     %d\n", ph1);

    // ~DEV_SEL: GP7 ← GPIO6 (active LOW, HIGH when idle)
    int devsel = (gpio >> SP_DEVSEL) & 1;
    printf("  GP7    GPIO6   ~DEV_SEL     %d      1 (inactive)  %s\n",
           devsel, devsel ? "OK" : "(active)");

    // _wreq: GP8 ← GPIO7 (active LOW, should be HIGH idle)
    int wreq = (gpio >> SP_WREQ) & 1;
    printf("  GP8    GPIO7   _wreq        %d      1 (inactive)  %s\n",
           wreq, wreq ? "OK" : "WRONG");

    // ACK/sense: GP9 → GPIO8 (open-drain output)
    // Currently deasserted (input/hi-Z), FPGA pull-up should read HIGH
    int ack_idle = (gpio >> SP_ACK) & 1;
    printf("  GP9    GPIO8   ACK(idle)    %d      1 (hi-Z+PU)   %s\n",
           ack_idle, ack_idle ? "OK" : "WRONG");

    // RDDATA: GP21 → GPIO9 (PIO TX output)
    int rddata = (gpio >> SP_RDDATA) & 1;
    printf("  GP21   GPIO9   rddata       %d      (PIO TX out)\n", rddata);

    // WRDATA: GP11 ← GPIO10 (PIO RX input)
    int wrdata = (gpio >> SP_WRDATA) & 1;
    printf("  GP11   GPIO10  wrdata       %d      (PIO RX in)\n", wrdata);

    // _enbl2: GP12 ← GPIO11 (active LOW, should be HIGH when no drive)
    int enbl2 = (gpio >> SP_ENBL2) & 1;
    printf("  GP12   GPIO11  _enbl2       %d      1 (inactive)  %s\n",
           enbl2, enbl2 ? "OK" : "WRONG");

    // --- Logical phase decode ---
    uint32_t raw_phases = (gpio >> SP_PHI_BASE) & SP_PHI_MASK;
    // Unscramble: raw bit0=PH2, bit1=PH3, bit2=PH0, bit3=PH1
    uint32_t logical = ((raw_phases >> 2) & 1) << 0   // PH0
                     | ((raw_phases >> 3) & 1) << 1    // PH1
                     | ((raw_phases >> 0) & 1) << 2    // PH2
                     | ((raw_phases >> 1) & 1) << 3;   // PH3
    printf("\n  Phases: raw=0x%X -> logical=0x%X (PH3:PH2:PH1:PH0)", raw_phases, logical);
    if (logical == 0x0A) printf(" = IDLE");
    else if (logical == 0x0B) printf(" = COMMAND");
    else if (logical == 0x05) printf(" = RESET");
    printf("\n");

    // --- ACK toggle test ---
    printf("\n  ACK toggle test:\n");
    printf("    Before assert: GP9 = %d\n", (sio_hw->gpio_in >> SP_ACK) & 1);
    gpio_set_dir(SP_ACK, GPIO_OUT);  // assert ACK (drives LOW)
    sleep_ms(1);
    printf("    After assert:  GP9 = %d (expect 0)\n", (sio_hw->gpio_in >> SP_ACK) & 1);
    gpio_set_dir(SP_ACK, GPIO_IN);   // deassert ACK (hi-Z)
    sleep_ms(1);
    printf("    After release: GP9 = %d (expect 1)\n", (sio_hw->gpio_in >> SP_ACK) & 1);

    // --- ~DEV_SEL activity test ---
    // Count low pulses over ~100K samples (IWM register accesses)
    int dev_pulses = 0;
    int dev_last = 1;
    for (int i = 0; i < 100000; i++) {
        int cur = (sio_hw->gpio_in >> SP_DEVSEL) & 1;
        if (cur == 0 && dev_last == 1) dev_pulses++;  // falling edge
        dev_last = cur;
    }
    printf("\n  ~DEV_SEL: %d pulses (IWM accesses) in ~100K samples", dev_pulses);
    if (dev_pulses > 0) printf(" -- ACTIVE\n");
    else printf(" -- idle (no IWM access)\n");

    printf("--- End Diagnostic ---\n\n");

    // --- Mount SD card and open disk image ---
    printf("Initializing SD card...\n");
    if (!sd_init()) {
        printf("*** SD init failed — halting ***\n");
        for (;;) sleep_ms(1000);
    }
    sp_data_set_blocks(sd_get_block_count());
    printf("Image mounted: %u blocks (%u KB)\n",
           sd_get_block_count(), sd_get_block_count() / 2);

    printf("Entering sp_main...\n");

    // Hand off to assembly — never returns
    sp_main(pio_rx, sm_rx, pio_tx, sm_tx);

    return 0;
}

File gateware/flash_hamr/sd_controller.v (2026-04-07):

// sd_controller.v — SD card command/response layer (SPI mode)
//
// Handles initialization, CMD17 (read block), CMD24 (write block).
// Instantiates sd_spi for byte-level transfers.
//
// Init: power-up clocks → CMD0 → CMD8 → ACMD41 loop → CMD58 → done
// Read: CMD17 → R1 → start token → 512 data bytes → 2 CRC
// Write: CMD24 → R1 → 0xFE token → 512 data bytes → 2 CRC → resp → busy

`timescale 1ns / 1ps

module sd_controller (
    input  wire        clk,          // 25 MHz
    input  wire        rst_n,

    // ---- Init ----
    input  wire        init_start,
    output reg         init_done,
    output reg         init_error,
    output reg         is_sdhc,

    // ---- Block read (CMD17) ----
    input  wire        read_start,
    input  wire [31:0] read_addr,     // block number
    output wire [7:0]  read_data,
    output reg         read_data_valid,
    input  wire        read_data_ready,
    output reg         read_done,
    output reg         read_error,

    // ---- Block write (CMD24) ----
    input  wire        write_start,
    input  wire [31:0] write_addr,    // block number
    input  wire [7:0]  write_data,
    input  wire        write_data_valid,
    output reg         write_data_req,
    output reg         write_done,
    output reg         write_error,

    // ---- SPI pins ----
    output wire        sd_sck,
    output wire        sd_mosi,
    input  wire        sd_miso,
    output reg         sd_cs
);

    // =========================================================================
    // SPI byte engine
    // =========================================================================
    reg        spi_start;
    reg [7:0]  spi_tx;
    wire [7:0] spi_rx;
    wire       spi_done;
    wire       spi_busy;
    reg        spi_slow;

    sd_spi u_spi (
        .clk(clk), .rst_n(rst_n),
        .start(spi_start), .tx_byte(spi_tx), .rx_byte(spi_rx),
        .done(spi_done), .busy(spi_busy), .slow_mode(spi_slow),
        .spi_sck(sd_sck), .spi_mosi(sd_mosi), .spi_miso(sd_miso)
    );

    assign read_data = spi_rx;

    // =========================================================================
    // Sub-state: send_byte — fires spi_start, waits for spi_done
    // Used by macro-states via phase counters.
    // =========================================================================
    // Convention: set spi_tx and spi_start=1 to initiate. spi_done=1 when complete.
    // The state machine checks (spi_done) to advance, or (!spi_busy && !spi_start) to initiate.

    // =========================================================================
    // Command buffer + argument
    // =========================================================================
    reg [7:0]  cmd_frame [0:5];
    reg [2:0]  byte_idx;
    reg [7:0]  r1;
    reg [31:0] r7;
    reg [1:0]  r7_cnt;
    reg [7:0]  poll_cnt;
    reg [9:0]  data_cnt;
    reg [1:0]  crc_cnt;
    reg [24:0] acmd41_timeout;
    reg [19:0] token_timeout;
    reg        sd_v2;
    reg [7:0]  wr_latch;          // latched write data byte
    reg        wr_latched;        // write data ready to send

    task set_cmd;
        input [5:0]  idx;
        input [31:0] arg;
        input [7:0]  crc;
        begin
            cmd_frame[0] = {2'b01, idx};
            cmd_frame[1] = arg[31:24];
            cmd_frame[2] = arg[23:16];
            cmd_frame[3] = arg[15:8];
            cmd_frame[4] = arg[7:0];
            cmd_frame[5] = crc;
        end
    endtask

    // =========================================================================
    // State encoding — explicit states, no return_state trickery
    // =========================================================================
    localparam [5:0]
        IDLE            = 6'd0,
        // Init sequence
        POWERUP         = 6'd1,   // CS=HIGH, send 10× 0xFF
        I_CMD0_SEND     = 6'd2,   // send CMD0 bytes
        I_CMD0_POLL     = 6'd3,   // poll R1
        I_CMD0_DONE     = 6'd4,   // check R1, CS_HIGH gap
        I_CMD8_SEND     = 6'd5,
        I_CMD8_POLL     = 6'd6,
        I_CMD8_R7       = 6'd7,   // read 4 R7 bytes
        I_CMD8_DONE     = 6'd8,
        I_CMD55_SEND    = 6'd9,
        I_CMD55_POLL    = 6'd10,
        I_ACMD41_SEND   = 6'd11,
        I_ACMD41_POLL   = 6'd12,
        I_ACMD41_DONE   = 6'd13,
        I_CMD58_SEND    = 6'd14,
        I_CMD58_POLL    = 6'd15,
        I_CMD58_R7      = 6'd16,
        I_CMD58_DONE    = 6'd17,
        I_DONE          = 6'd18,
        I_ERROR         = 6'd19,
        GAP             = 6'd20,  // CS=HIGH + 8 clocks
        // Read CMD17
        R_CMD_SEND      = 6'd21,
        R_CMD_POLL      = 6'd22,
        R_TOKEN         = 6'd23,  // poll for 0xFE
        R_DATA          = 6'd24,  // 512 bytes
        R_CRC           = 6'd25,  // 2 CRC bytes
        R_DONE          = 6'd26,
        // Write CMD24
        W_CMD_SEND      = 6'd27,
        W_CMD_POLL      = 6'd28,
        W_TOKEN         = 6'd29,  // send 0xFE
        W_DATA          = 6'd30,  // 512 bytes
        W_CRC           = 6'd31,
        W_RESP          = 6'd32,
        W_BUSY          = 6'd33,
        W_DONE          = 6'd34;

    reg [5:0]  state = IDLE;
    reg [5:0]  gap_return;        // where to go after GAP state
    reg [4:0]  powerup_cnt;

    // =========================================================================
    // State machine
    // =========================================================================
    always @(posedge clk or negedge rst_n) begin
        if (!rst_n) begin
            state           <= IDLE;
            sd_cs           <= 1'b1;
            spi_start       <= 1'b0;
            spi_tx          <= 8'hFF;
            spi_slow        <= 1'b1;
            init_done       <= 1'b0;
            init_error      <= 1'b0;
            is_sdhc         <= 1'b0;
            read_data_valid <= 1'b0;
            read_done       <= 1'b0;
            read_error      <= 1'b0;
            write_data_req  <= 1'b0;
            write_done      <= 1'b0;
            write_error     <= 1'b0;
            sd_v2           <= 1'b0;
            wr_latch        <= 8'd0;
            wr_latched      <= 1'b0;
            r1              <= 8'hFF;
            r7              <= 32'd0;
            byte_idx        <= 3'd0;
            poll_cnt        <= 8'd0;
            data_cnt        <= 10'd0;
            crc_cnt         <= 2'd0;
            powerup_cnt     <= 4'd0;
            acmd41_timeout  <= 25'd0;
            token_timeout   <= 20'd0;
            r7_cnt          <= 2'd0;
            gap_return      <= IDLE;
        end else begin
            spi_start       <= 1'b0;
            // read_data_valid: level-based, cleared by handshake (NOT pulsed)
            read_done       <= 1'b0;
            read_error      <= 1'b0;
            write_data_req  <= 1'b0;
            write_done      <= 1'b0;
            write_error     <= 1'b0;
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

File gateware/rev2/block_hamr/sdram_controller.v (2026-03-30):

// =============================================================================
// SDRAM Controller for Block Hamr
// =============================================================================
//
// Provides a simple SRAM-like interface to the SDRAM, abstracting all timing
// details including initialization, refresh, row activation, precharge, and
// CAS latency. Single point of contact with SDRAM - no other module touches
// SDRAM pins directly.
//
// Interface:
//   - Single request port (read or write), 16-bit data
//   - pause_refresh: Defer refresh during time-critical operations
//   - init_done: High when SDRAM is ready for use
//
// SDRAM: AS4C32M16SB-7TCNTR (64MB, 32M x 16-bit) at 25 MHz
//   - 26-bit byte address decomposition:
//       addr[0]     = byte lane (DQM select, reserved for future use)
//       addr[10:1]  = column (10 bits, 1024 columns)
//       addr[23:11] = row (13 bits, 8192 rows)
//       addr[25:24] = bank (2 bits, 4 banks)
//   - tRCD: 20ns (1 clock at 25 MHz)
//   - tRP: 20ns (1 clock)
//   - tRFC: 66ns (2 clocks minimum, using 8 for margin)
//   - tWR + tRP: 4 clocks
//   - CAS Latency: 2
//   - Burst Length: 1
//
// =============================================================================

`timescale 1ns / 1ps

module sdram_controller (
    input  wire        clk,            // 25 MHz system clock
    input  wire        rst_n,          // Active-low reset

    // Initialization status
    output reg         init_done,      // High when SDRAM is ready for use

    // Refresh control
    input  wire        pause_refresh,  // Defer refresh while high

    // Request interface (single port)
    input  wire        req,            // Request (read or write)
    input  wire        req_write,      // 1 = write, 0 = read
    input  wire [25:0] req_addr,       // 26-bit byte address
    input  wire [15:0] req_wdata,      // Write data (16-bit)
    output reg         req_ready,      // Ready to accept request
    output reg  [15:0] req_rdata,      // Read data (16-bit)
    output reg         req_rdata_valid, // Read data valid (one cycle pulse)

    // SDRAM physical pins
    output wire        SDRAM_CLK,
    output reg         SDRAM_CKE,
    output wire        SDRAM_nCS,
    output wire        SDRAM_nRAS,
    output wire        SDRAM_nCAS,
    output wire        SDRAM_nWE,
    output reg         SDRAM_DQM0,
    output reg         SDRAM_DQM1,
    output wire        SDRAM_BA0,
    output wire        SDRAM_BA1,
    output reg  [12:0] SDRAM_A,
    inout  wire [15:0] SDRAM_DQ
);

    // =========================================================================
    // SDRAM Command Encoding: {nCS, nRAS, nCAS, nWE}
    // =========================================================================

    localparam [3:0] CMD_NOP       = 4'b0111;
    localparam [3:0] CMD_ACTIVE    = 4'b0011;
    localparam [3:0] CMD_READ      = 4'b0101;
    localparam [3:0] CMD_WRITE     = 4'b0100;
    localparam [3:0] CMD_PRECHARGE = 4'b0010;
    localparam [3:0] CMD_REFRESH   = 4'b0001;
    localparam [3:0] CMD_LOAD_MODE = 4'b0000;

    // =========================================================================
    // State Machine States
    // =========================================================================

    localparam [3:0]
        ST_INIT_WAIT   = 4'd0,   // Power-up wait (200us)
        ST_PRECHARGE   = 4'd1,   // Precharge all banks
        ST_REFRESH1    = 4'd2,   // First auto-refresh
        ST_REFRESH2    = 4'd3,   // Second auto-refresh
        ST_LOAD_MODE   = 4'd4,   // Load mode register
        ST_IDLE        = 4'd5,   // Ready for requests
        ST_ACTIVATE    = 4'd6,   // Activate row
        ST_READ_CMD    = 4'd7,   // Issue read command
        ST_READ_WAIT   = 4'd8,   // Wait for CAS latency
        ST_WRITE_CMD   = 4'd9,   // Issue write command
        ST_WRITE_WAIT  = 4'd10,  // Wait for tWR
        ST_REFRESH     = 4'd11,  // Periodic refresh
        ST_REFRESH_WAIT= 4'd12;  // Wait for refresh complete

    reg [3:0]  state;
    reg [15:0] delay_cnt;

    // =========================================================================
    // SDRAM Control Signals
    // =========================================================================

    reg [3:0]  sdram_cmd;
    reg [1:0]  sdram_ba;
    reg [15:0] sdram_dq_out;
    reg        sdram_dq_oe;

    // Assign command pins
    assign {SDRAM_nCS, SDRAM_nRAS, SDRAM_nCAS, SDRAM_nWE} = sdram_cmd;
    assign SDRAM_CLK = clk;
    assign SDRAM_BA0 = sdram_ba[0];
    assign SDRAM_BA1 = sdram_ba[1];

    // Bidirectional data bus
    assign SDRAM_DQ = sdram_dq_oe ? sdram_dq_out : 16'hZZZZ;

    // Sample input data
    reg [15:0] sdram_dq_sample;
    always @(posedge clk) begin
        sdram_dq_sample <= SDRAM_DQ;
    end

    // =========================================================================
    // Refresh Counter
    // =========================================================================

    // Refresh interval: 7.6us ~ 190 clocks at 25 MHz
    localparam [7:0] REFRESH_INTERVAL = 8'd190;

    reg [7:0]  refresh_cnt;
    reg        refresh_needed;
    reg        refresh_pending;  // Tracks if refresh was needed but paused

    always @(posedge clk or negedge rst_n) begin
        if (!rst_n) begin
            refresh_cnt <= REFRESH_INTERVAL;
            refresh_needed <= 1'b0;
            refresh_pending <= 1'b0;
        end else if (state == ST_INIT_WAIT || state == ST_REFRESH) begin
            refresh_cnt <= REFRESH_INTERVAL;
            refresh_needed <= 1'b0;
            refresh_pending <= 1'b0;
        end else if (refresh_cnt == 0) begin
            if (pause_refresh) begin
                // Defer refresh, mark as pending
                refresh_pending <= 1'b1;
            end else begin
                refresh_needed <= 1'b1;
            end
        end else begin
            refresh_cnt <= refresh_cnt - 1'b1;
            // If pause_refresh drops and we have a pending refresh
            if (!pause_refresh && refresh_pending) begin
                refresh_needed <= 1'b1;
                refresh_pending <= 1'b0;
            end
        end
    end

    // =========================================================================
    // Address Decomposition
    // =========================================================================
    //
    // 26-bit byte address:
    //   addr[0]     = byte lane (reserved, full 16-bit transfers for now)
    //   addr[10:1]  = column (10 bits)
    //   addr[23:11] = row (13 bits)
    //   addr[25:24] = bank (2 bits)
    //

    // =========================================================================
    // Request Latching
    // =========================================================================

    reg         latched_write;
    reg [25:0]  latched_addr;
    reg [15:0]  latched_wdata;
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

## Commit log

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2025-12-08 Update PCB design and replace outdated gerbers
    Replaces old gerber files with a new version reflecting design
    updates. Revamps PCB layout by adding new segments and vias while
    removing outdated ones, optimizing net 2 connections for improved
    efficiency and functionality. Corrects routing and aligns segments
    with new design specifications.
    [project_byte_hamr.kicad_pcb]
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2025-12-10 Updated Rev. 1.1
    - Wired Level Shifters
    - Expansion GPIOs
    - Oscillator
    - Flash
    - USB
    [card.kicad_sch, card_fpga.kicad_sch, flash.kicad_sch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]
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2025-12-12 Updates BOM and README for GPIO and SDRAM
    Changes PinHeader in BOM to support 13 pins. Updates README to reflect correct GPIO specifications and expands SDRAM capacity from 32MB to 64MB, ensuring accurate technical details for users.
    Relates to branch 1.1
    [project_byte_hamr_bom_full.csv]
2025-12-12 Updates FPGA model in BOM and schematics
    Replaces LFE5U-25F-6BG381C with LFE5U-85F-8BG381I in multiple files.
    Ensures consistency across BOM, schematics, and PCB layouts for the updated FPGA model.
    Adjusts related properties such as part number and connectivity attributes.
    Addresses a hardware specification upgrade in branch 1.1.
    [card_fpga.kicad_sch, flash.kicad_sch, gpio.kicad_sch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]
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2025-12-30 Replace legacy BOM with all-pos version
    Adds a new all-position BOM file for Byte HAMR with detailed placement data and removes the previous legacy BOM file along with an associated PCB ZIP artifact.
    [project_byte_hamr-all-pos.csv]
2026-01-17 Improves signal check functionality and testability
    Refactors the signal check gateware for enhanced functionality and testability.
    This commit introduces a fake PHI0 generator, enabling standalone
    testing of the GPIO3 activity indicator without requiring an
    external Apple II connection. An external PHI0 detector
    automatically switches to the fake clock when no external clock
    source is present.
    The heartbeat LED is changed to a 250kHz square wave for easier
    oscilloscope testing.
    Pull-up resistors are enabled on the Apple II I/O signals.
    A diode rotation is corrected on the PCB.
    [project_byte_hamr.kicad_pcb]
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2026-02-01 Deprecates byte_ravn hardware files
    Moves byte_ravn hardware files to the deprecated folder.
    This indicates that the design is no longer actively maintained
    or intended for future use.
    [byte_ravn.kicad_pcb, byte_ravn.kicad_sch, card.kicad_sch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]
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2026-02-03 Implements Logic Hamr v2 logic analyzer
    This commit introduces Logic Hamr v2, a complete redesign of the logic analyzer with significant performance improvements and a modular architecture.
    Key features include:
    - Parallel regeneration: Processes all 8 channels simultaneously from a single SDRAM pass, resulting in an 8x speed increase compared to v1.
    - Re-zoom capability: Regenerates the display buffer with different window presets without requiring a new capture.
    - Modular design: Uses separate modules for SDRAM control, capture, regeneration, and bus interface.
    - Comprehensive testbench: Includes integration tests for SDRAM initialization, capture with trigger detection, parallel regener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
    [sdram_controller.v]
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2026-02-18 Added Proof of Concept / Prototype Board
    Adding a schematic and PoC board for the FujiNet Tool - Aiming to reduce noise and capacitance on the lines.
    [Fuji_Hamr.kicad_pcb, Fuji_Hamr.kicad_sch]
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2026-03-08 Adds KiCad inverter symbol; configures GPIO pulls
    Adds the SN74LVC1G04DBVR single inverter to the KiCad library,
    including its symbol and SOT-23-5 footprint.
    Configures GPIO pins for proper idle states:
    - `SP_ENBL1`: Adds a pull-up resistor, as it's an active-low enable.
    - `SP_RDDATA`: Adds a pull-down resistor, ensuring the line idles low
    to correctly present a high idle state to the FPGA's read data input.
    [main.c]
2026-03-10 Improve SmartPort communication reliability and signal integrity
    - Relocates `rddata` to GP21 and flushes the RX FIFO after transmission to mitigate crosstalk.
    - Implements a bit-shift correction mechanism in the receiver to handle spurious bits caused by inter-byte pauses.
    - Adds a 15µs delay before sending to ensure the Apple II's IWM Q6 flush is complete before data arrives.
    - Updates the decoder to correctly handle the high idle state of `wrdata`.
    - Increases preamble length and idle detection timing for better synchronization.
    - Returns error status packets for invalid block requests to prevent host timeouts.
    [main.c, picoport.h]
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2026-03-14 Update footprint metadata: add MPNs, fix pin types, and refresh datasheets/descriptions
    This change enriches KiCad footprints with manufacturer part numbers (MPN) across numerous components, updates datasheet URLs and descriptions for clarity, and corrects a pin-type for a JTAG signal. It also extends the ki_fp_filters for certain footprints to better reflect their package families. These metadata improvements support more accurate BOM generation, sourcing, and assembly coordination.
    [project_byte_hamr.kicad_pcb]
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2026-03-19 Refine hardware design and documentation for Revision 2.0
    Updates footprint library references to use local Apple II connector footprints and adjusts component placements and trace routing across the PCB. Silkscreen date codes and text sizes have been updated, and a correction was made to the flash memory capacity notation in the README.
    [project_byte_hamr.kicad_pcb]
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2026-03-27 IWM Hamr v2 — register-based block device with working writes
    Replace SmartPort/IWM protocol stack with a simple 4-register bus
    interface. The 6502 driver fits in 256 bytes ($Cn page, no $C800).
    Three write-path bugs fixed:
    - 7MHz clock can't reliably sample 6502 write data (~200ns valid
    window). Fix: posedge nDEVICE_SELECT latch captures at the exact
    bus cycle boundary, matching how real Apple II peripherals work.
    - assemble_rom.py filled BRAM but never issued CMD_WRITE to trigger
    the BRAM→SDRAM transfer. Driver returned success with no write.
    - 6502 STA abs,X is 5 cycles: cycle 4 is a dummy READ at the
    effective address, generating a spurious auto-increment. Fix:
    split DATA_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
    [sdram_controller.v]
2026-03-30 Block Hamr v3 — synchronous write-through flash persistence
    Rename iwm_hamr → block_hamr to reflect the register-based block device
    architecture (IWM protocol was removed in v2).
    Add SPI flash write-back so ProDOS block writes survive power cycles.
    Every block write triggers a sector erase + 16 page programs from SDRAM
    to flash, gated through three separate modules to avoid Yosys ECP5
    synthesis corruption:
    write_through.v — block_ready gating only
    flash_persist.v — flash erase + page program from SDRAM
    flash_writer.v — SPI engine (WREN, SECTOR_ERASE, PAGE_PROGRAM, WIP poll)
    Driver ROM (assemble_rom.py) adds wait_long for the ~718ms flash write
    latency, using ZP $3A wit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
    [block_hamr_tb.v, boot_loader_tb.v]
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2026-04-07 Flash Hamr v1 — PicoRV32 + FatFS SD card controller (Phases 1-8)
    Replace RTL FAT32 state machines with PicoRV32 soft-core CPU running
    elm-chan FatFS in C firmware. Full read/write/persist path verified on
    hardware.
    Architecture:
    - PicoRV32 (RV32I, 25MHz) with 32KB IMEM + 16KB DMEM
    - SPI master for SD card (Mode 0, dual-speed 195kHz/3.125MHz)
    - UART TX (115200 baud) for debug printf
    - Mailbox (toggle-CDC FFs) bridges 7MHz Apple II bus to 25MHz CPU
    - Magic block intercept ($FFFF) routes catalog through block buffer
    - SDRAM port with claim mux for mount streaming
    - block_ready_gate (strict module separation for Yosys ECP5 safety)
    Verified on hardware:
    - SD card init (SDSC + SDHC)
    - FatFS mo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
    [main.c]
2026-04-07 Flash Hamr v2 — Picker UI, mount-to-block-0, 12.5MHz SPI (Phase 9)
    Picker program (A.PICKER.SYSTEM) reads catalog via magic block $FFFF,
    displays file list with names and block counts, mounts selected image
    to SDRAM block 0, reboots via JMP $C400. ProDOS boots from mounted
    image — CATALOG verified working.
    Changes:
    - assemble_picker.py: 6502 picker with magic block catalog reads
    - build_menu.sh: builds menu.po (PRODOS + A.PICKER.SYSTEM)
    - Mount now writes to SDRAM block 0 (overwrites menu volume)
    - SPI data clock increased from 3.125MHz to 12.5MHz (4x faster mount)
    - Magic block ready signal stretched for reliable 25MHz→7MHz CDC
    - Magic block active flag forces dev_block_ready LOW→H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
    [main.c]
2026-04-08 Flash Hamr v3 — Persist fixes: CREATE/SAVE survive cold reboot (Phase 10 prep)
    Three bugs fixed in the block-write persist path:
    1. Gate glitch (block_ready_gate.v): The 7MHz gate let arb_block_ready
    pass through for 1 cycle before the trigger could suppress it,
    causing bus_interface to prematurely exit S_BUSY. Fix: use
    arb_ready_delayed (1-FF registered copy) for the gated output so
    trigger fires before the delayed signal reaches bus_interface.
    2. UART blocking (main.c): Debug UART output before f_write/f_sync
    consumed ~4ms+ of the slot ROM's ~1.28s wait_ready budget. Fix:
    PERSIST_DONE is written before any UART output.
    3. SD card SPI wake-up (main.c, spi_sd.c): SDSC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
    [main.c]
2026-04-09 Flash Hamr v4 — On-demand SD reads work (Phase 10)
    Mount is instant (f_open). Block reads served directly from SD card
    via PicoRV32 firmware — no SDRAM cache, no streaming mount. ProDOS
    boots and runs programs from SD card images (.PO/.2MG).
    Root cause of Phase 10 failures: hamr_rom.mem was stale (from old
    block_hamr design). assemble_rom.py was never called by the build
    system. The 6502 driver ROM didn't match the register interface,
    so the ProDOS boot block's subsequent reads never issued CMD_READ.
    Also fixed: assemble_rom.py rewritten as $Cn-page-only ROM (no $C800
    expansion ROM) to avoid bus contention with Apple IIe internal ROM
    during ProDOS startup. $C800 investigation deferred.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
    [main.c]
2026-04-09 Clean house: archive dead RTL, new integration testbench
    Archive 14 dead RTL modules and testbenches from the old streaming-mount
    architecture (sd_controller, fat32_reader, sd_mount, sd_persist, sd_spi,
    write_through + all their TBs) to archive/rtl_fat32/. These are replaced
    by PicoRV32 firmware + FatFS.
    New flash_hamr_tb.v tests the current on-demand cache architecture:
    - Non-intercepted arbiter reads (S4D1 path)
    - Cache-intercepted reads with toggle CDC + MAGIC_DONE
    - Toggle re-arming for consecutive reads
    - Magic block ($FFFF) interception without cache_enabled
    All 9 tests pass. boot_loader_tb and spi_master_tb also verified passing.
    Added sim_dp16kd.v (behavioral DP16KD model for iveri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
    [fat32_reader.v, sd_card_model_tb.v, sd_controller.v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]
2026-04-09 Flash Hamr v5 — SDRAM block cache (Phase 10 complete)
    On-demand reads now cache in SDRAM. First access reads from SD card
    (miss), subsequent accesses served from SDRAM (hit). Boot Oregon Trail:
    ~70 misses on first load, all hits on warm reboot.
    - Cache bitmap: 8KB (65536 blocks, covers full 32MB ProDOS volume)
    - Miss: SD → sector_buf → SDRAM + block buffer (~5-20ms)
    - Hit: SDRAM → block buffer (~200μs)
    - Writes: arbiter → SDRAM (instant), then persist to SD, mark cached
    - Makefile: sim models in sim/ subdir (excluded from synthesis)
    [main.c]
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2026-04-10 Flash Hamr v7 — Merlin picker + mount flow + on-demand cache fixes
    Picker rewrite (Merlin32):
    - Replace Python assemblers with picker.S (Merlin32 65C02 assembly)
    - Move menu build to Makefile (make menu), remove build_menu.sh
    - Fix CROUT-trashes-A bug: PHA/PLA around COUT/CROUT in all RDKEY paths
    - SD_INIT sent once at startup, not on every redraw (preserves mount state)
    - Multi-slot mount/unmount/boot UI with M/U/B/Q menu
    Firmware (main.c):
    - Parse mount_slot from arg0 high bits ({slot[7:6], img_idx[3:0]})
    - Write per-unit MBOX_UNIT_BLKCNT and MBOX_UNIT_OFFSET registers after mount
    - Set mounted_sdram_base=1024, protect S4D1 cache (blocks 0-279)
    - Cache-first logic: check bitmap before r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
    [main.c]
2026-04-11 Flash Hamr v7.1 — wire block_num_out + multi-drive firmware
    Critical RTL fix:
    - block_num_out (block_num + unit_offset[active_unit]) was UNCONNECTED
    in flash_hamr_top.v — the offset-adjusted address went nowhere.
    Arbiter, magic intercept, and persist all used raw block_num.
    - Wire dev_block_num_abs to arbiter, block_ready_gate, and magic CDC.
    Block reads now use absolute SDRAM addresses with per-unit offsets.
    Multi-drive firmware:
    - Per-drive state: drives[3] array with FIL, block_count, data_offset,
    sdram_base per slot. Replaces single mounted_fil.
    - Sequential SDRAM placement: S4D2@1024, S4D3@1024+D2_size, etc.
    - find_drive(): maps absolute SDRAM block to drive + local block.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
    [main.c]
2026-04-11 Flash Hamr v7.3 — persist debug logging, remove force_fw rebuild
    Firmware: Add detailed persist debug: abs block, drive index, local
    block offset. Confirms multi-drive write routing is correct when SD
    card cooperates. Intermittent SD SPI errors (!R17 tok=00, !W24) cause
    FatFS state corruption on remount — separate issue from drive logic.
    Makefile: Remove force_fw phony dep that caused full rebuild on every
    flash. Add hal.h as explicit firmware dependency instead.
    [main.c]
2026-04-11 Flash Hamr v7.4 — SD write reliability + drive cleanup
    SPI write fixes:
    - Add sd_spi_flush() — 80 dummy clocks with CS high to reset card
    state after errors
    - sd_read_sector: 3 retries with bus flush between attempts
    - sd_write_sector: 3 retries for command rejection, but NO retry
    after card accepts data (response 0x05) — just wait longer
    - Pre-write busy wait: 2M iterations (~2-4s) for cards doing GC
    after multi-file seeks
    - Programming wait: 5M iterations (~5-10s) for worst-case SDSC
    erase storms with 3 drives mounted
    - Error messages now on own lines (\r\n prefix) for UART visibility
    Firmware fixes:
    - MCMD_SD_INIT closes all open drives before f_mount(0) — prevents
    stal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
    [main.c]
2026-04-11 Flash Hamr v8 — Duo Drive architecture + SDHC support
    Replaced the 4-unit multi-drive prototype with a clean 2-unit "Duo Drive"
    design. D1 is the boot drive, D2 is data. Picker UI asks for both, mounts
    them, reboots into D1. Power cycle returns to picker. BRUN PICKER from
    Merlin for warm re-swap.
    - 2 SmartPort units (NUM_UNITS=2), single active_unit bit in bus_interface
    - D1 at SDRAM block 0, D2 at block 32768 (fixed 16MB split)
    - D2 block count register in cpu_soc mailbox (+0x20), CDC to 7MHz
    - ProDOS STATUS checks $43 bit 7 for D1 (regs 6/7) vs D2 (regs B/C)
    - D2 returns ERR_NODEV when unmounted (0 blocks)
    - Firmware: two FIL handles, route cache miss + persist by block ad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
    [main.c]
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2026-04-22 Rev 2 board bring-up — reorg to rev1/rev2 trees, signal_check port
    Rev 2 boards (FTDI serials DP0517RX, DP051FY9) arrived and passed first
    bring-up: both enumerate, flash cleanly, and pass SDRAM + GPIO tests.
    - Move all existing designs into gateware/rev1/ (tag rev1 marks final state)
    - Add gateware/rev2/ with base LPF generated from KiCad netlist
    - Port signal_check to rev2: 100 MHz clock (/4 to 25 MHz), GPIO_1..GPIO_20,
    DATA_OE for transceiver, nRES_READ for bidirectional reset monitoring
    - Makefile: REV variable (defaults rev1) selects which tree to build
    - .gitignore: patterns use gateware/**/ to match either rev
    - README: Rev 2 features, new GPIO map, updated build commands
    Rev 2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
    [Fuji_Hamr.kicad_pcb, Fuji_Hamr.kicad_sch]
2026-04-23 Block Hamr — Rev 2 port
    Port block_hamr from rev1 to rev2 hardware. Verified on bench: PR#4 boots
    ProDOS from SDRAM-backed disk image and block writes persist to flash.
    Top-level changes for Rev 2 pinout / clocking:
    - Switch from direct 25 MHz @ G3 to 100 MHz @ F3, derive 25 MHz via EHXPLLL
    (CLKI_DIV=4, CLKFB_DIV=1, CLKOP_DIV=20 → VCO=500 MHz, CLKOP=25 MHz).
    Counter-divider approach leaves the internal clock on local routing —
    PLL puts CLKOP on a dedicated global clock network, matching rev1's
    direct-oscillator behavior.
    - Unbundle addr[11:0] into individual A0..A15 ports so the design lines
    up with the rev2 base LPF (rev1 used a design-specific LPF).
    - Rename GPIO1..GPIO12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
    [block_hamr_tb.v, boot_loader_tb.v]
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2026-06-08 test(coproc-c0): integration — coproc writes $42 to bank0/$40, host reads it
    Add the C0 proof + monitor-regression checks to project_obscurus_tb.v.
    Root-causing the initial failure surfaced a real DUT deadlock: the Arlet
    coproc executed STA $E000 ~10 cycles after reset, long before sdram_ctrl
    finished its ~200us init. sdram_ctrl gates request-accept on `ready` and
    silently dropped the early write, but sdram_arb had already committed
    `servicing` and waited forever for an op_complete that never arrived —
    permanently starving the monitor (c0) too. Fix in the DUT, not the test:
    add a `ready` input + ST_BOOT state to coproc.v that holds the core
    RDY-stalled until SDRAM init completes, then re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
    [project_obscurus_tb.v]
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2026-06-08 test(coproc-c2): integration — cooperative race orders 1/2, re-arm flips to 2/1
    Add the C2 race integration block to project_obscurus_tb.v: register two
    racetask instances, arm via COUNT, and assert host-observable finish order
    (NPARAM 4/8 -> 1/2) then re-arm with swapped budgets (12/8 -> 2/1). Proves
    YIELD/RESTORE context switch, round-robin, finish-order stamping, and the
    COUNT re-arm edge.
    Root-caused two pre-existing kernel/test defects exposed by this work:
    - kernel BOOTSTRAP hardcoded $0300 as every task's resume address instead of
    reading TABLE[X]=$0200+2*X, so distinct C1 tasks all ran taskA. Fixed
    BOOTSTRAP to push (TABLE[X]-1) hi/lo; rebuilt kernel.mem via Merlin32.
    - C1 tas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
    [project_obscurus_tb.v]
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2026-06-08 test(coproc-c3): preemptive race orders 1/2, re-arm flips 2/1 (timer preemption proven); C2 cooperative still passes
    Adds the C3 preemptive race+flip (no-yield tasks sliced by the timer tick)
    and a BRK-safety check to the integration TB. The FLIP (budgets 20/12 -> r1=01)
    is the preemption proof: a dead-timer scheduler would run task0 to completion
    regardless of budget. All C1/C2/C3 + monitor pass, 0 errors.
    Two real defects fixed to make the C3 kernel actually run under sim:
    - coproc.v: irq_pending/tick regs were declared AFTER the cpu instance that
    binds .IRQ(irq_pending); iverilog -g2005 needs declaration-before-use, so
    the C3 coproc never compiled. Reordered the declarations (no log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
    [project_obscurus_tb.v]
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2026-06-09 vendor(coproc-cflash): port flash_writer/reader + combined SPI flash sim model
    Copy flash_writer.v and flash_reader.v verbatim from block_hamr (proven
    IS25LP128F engines, no logic changes). Add sim/spi_flash_model.v: a
    merged write+read model (4KB backing store, addr[11:0]-masked, nonvolatile
    across DUT resets) derived by merging the two block_hamr proven models.
    Bonus: sim/flash_roundtrip_tb.v — erase→program→read round-trip through
    the real engines passes 10/10 checks under -g2005.
    [flash_reader.v, flash_writer.v]
2026-06-09 test(coproc-cflash): cflash_save_tb assert 14 data pages + header-LAST ordering
    Spec-review flagged coverage gaps: no page-count/ordering check. Add asserts that
    exactly 14 data pages program before the single header page (the torn-save fail-safe).
    [cflash_save_tb.v]
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2026-06-09 test(coproc-cflash): T6 end-to-end SAVE->RAM-loss->auto-RESTORE->run service
    Integration proof in project_obscurus_tb.v: host-load racetask3 service +
    TABLE into coproc BRAM, SAVE to SPI flash ($C0CF<-$5A), explicitly zero the
    $0200-$0FFF task region via the host load port (models the power-cycle RAM
    loss a sim reset does NOT -- BRAM survives rst_n, $readmemh only runs at t=0),
    pulse nRES_READ to re-arm the restore FSM, poll restore_done/valid, set NPARAM
    fresh (ZP $00E8 is below the saved region), GO, and read SDRAM result cells
    $0061/$0062 == 01/02 -> the restored-from-flash service ran.
    Wire spi_flash_model to the DUT FLASH pins; SCK reached by hierarchical ref
    (assign flash_sck_probe =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
    [project_obscurus_tb.v]
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2026-06-10 feat(multiverse): LIFE8 TICK1 - bit-packed sliding-window Life + torus, sim-verified (blinker/glider/boundary/torus)
    TICK1: one Conway Life generation on one universe, on the Arlet soft-6502
    coprocessor. True sliding window (3 rotating 80-byte BRAM row buffers, one
    new SDRAM row read per output row via rotation-by-pointer, ~NROWS+1 reads/gen).
    COLSUM pass (per-column up+mid+dn, 0..3, tracked by incremental byte/bit
    counters, no mod-7 divide) then ROWOUT pass (n = colsum[x-1]+colsum[x]+
    colsum[x+1]-mid, with horizontal torus wrap col0<->col559). Wrapper ticks
    universe 0, flips FRONT[0], bumps GEN[0], JMP DONE. LSIM=1 builds the 8-row
    sim grid (full 80-byte width); flip to 0 for the 192-row ha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
    [project_obscurus_tb.v]
2026-06-10 feat(multiverse): LIFE8 forever loop - round-robin 8 universes, flip-before-bump (R5), never DONE, budget=0
    [project_obscurus_tb.v]
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2026-06-10 test(farm): M1 a-e - spawn, STATUS, PLANT/HARVEST, growth walk, EV_RIPE, error paths
    FARM protocol helpers (farm_load/farm_init/farm_cmd/farm_drain) + farm_m1
    test block: slot-0-free guard, spawn skill 2 budget 0, STATUS, PLANT (3,3)
    and corner (19,19) with plot/SEEDS checks, occupied E1, unripe E2, SELL/BUY
    qty-0 E6, ripen wait, EV_RIPE drain order, HARVEST -> CROPS=1.
    EV_RIPE drain uses a bounded re-drain loop: DOGROW writes the plot byte
    before PUTEV publishes, so a single drain after the ripen poll can race
    the in-flight publish of the last-scanned plot's event.
    sdram_model.v: WORDS doubled 1M -> 2M words (banks 0..63) - the FARM game
    world at GBANK=32 sat exactly on the old 1M-word mo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
    [project_obscurus_tb.v]
2026-06-11 test(farm): M1 economy - SELL/BUYSEED, ERR_FULL clamp, price walk, EV_PRICE
    farm_econ block: SELL 1 @ 10 -> CASH 110/SUPPLY 1, no-crops E5, BUYSEED 2
    @ 3 -> CASH 104/SEEDS 5, SEEDS=254 + buy 5 -> E7 with SEEDS untouched.
    Price walk forces SUPPLY=10 (TGT=5) and asserts the MINIMUM price seen
    <= 7 over 200 samples - with DECAYDIV=4 the target rises as supply drains,
    so any endpoint assertion is wrong by construction. >=3 EV_PRICE drained
    (sim saw 4).
    [project_obscurus_tb.v]
2026-06-11 test(farm): tb diagnosability - bound resync loop, tighten cmd timeout, phase-order note
    [project_obscurus_tb.v]
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2026-06-11 test(farm): sim speed + robustness - +farmonly/+vcd plusargs (VCD off by default, was ~20GB/run), measured FARMLEN (fixes silent blob-tail truncation that killed PUTEV), yield-aware econ asserts, har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
    Full suite 38 PASS / 0 FAIL in 9m16 (was ~40min); farm-only 90s.
    [project_obscurus_tb.v]
2026-06-11 feat(farm): rare-yield RNG - 0.4% crop death / 1.6% double / 0.8% triple; scratch relocated $0B->$0E00 + hard blob-size guard
    Yield roll moved from 2-bit table (25%/25%) to full-byte compare chain
    (user-spec rates). New CROP DIED! status message on zero delta.
    Blob crossed $0B00 into EVLIB scratch when the chain was added (PUTEV
    self-corrupting, ring dead) - scratch now at $0E00-$0E2C, code bound
    $0C00 (LIFE8GR scratch), enforced by FARMTASK_MAXLEN check in both
    blob rules. tb: yield asserts widened to 0-3, econ sell-leg skips on
    death roll. farm-only suite green 90s.
    [project_obscurus_tb.v]
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
